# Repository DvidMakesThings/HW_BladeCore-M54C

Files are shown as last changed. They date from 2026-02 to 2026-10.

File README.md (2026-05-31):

# BladeCore‑M54C

BladeCore‑M54C is part of the **BladeCore** modular controller series.  
Each BladeCore variant is implemented as a standalone hardware repository, sharing a common architectural philosophy while targeting different microcontrollers and interfaces.

This repository documents the **BladeCore-M54C** hardware, which is based on the **RP2354B** microcontroller and integrates **CAN 2.0B connectivity**.

## BladeCore Series Overview

The BladeCore series consists of the following hardware variants:

| Module | Microcontroller | Primary Interface | Form Factor | Status |
|---|---|---|---|---|
| [BladeCore‑M40](#)  | RP2040  | — | - | Work in progress |
| [BladeCore‑M40E](#) | RP2040  | Ethernet | - | Work in progress |
| [BladeCore‑M40C](#) | RP2040  | CAN | - | Work in progress |
| [BladeCore‑M54](#)  | RP2354B | — | - | Work in progress |
| [BladeCore-M54E](https://github.com/DvidMakesThings/HW_BladeCore-M54E) | RP2354B | Ethernet | 2980 | Available |
| [BladeCore-M54C](https://github.com/DvidMakesThings/HW_BladeCore-M54C) | RP2354B | CAN | 2980 | Available |

### Naming Scheme Explanation

The BladeCore naming scheme encodes the **microcontroller family** and **primary communication interface** directly in the module name:

- **M40** designates an RP2040‑based module  
- **M54** designates an RP2354B‑based module  
- **E** suffix indicates integrated Ethernet support  
- **C** suffix indicates integrated CAN support  

Variants without a suffix represent the **base module** for that microcontroller family, without Ethernet or CAN integrated.

Each BladeCore variant is implemented as a **separate hardware design and repository**.

## Description

BladeCore-M54C is a compact controller module built around the **RP2354B** microcontroller, combined with a **MCP2515T-I/ML CAN controller** and the **TCAN1044AVDRBRQ1** CAN transceiver.  
The module is designed as a **2980-size M.2 M-Key card**, intended to be embedded into a carrier board or system that provides power through the M.2 edge connector.

The design integrates:

*   RP2354B microcontroller
*   External QSPI flash memory
*   External I²C EEPROM
*   Onboard CAN controller and transceiver with 120 Ohm termination
*   Dual‑path USB connectivity with automatic source selection
*   Onboard power regulation and defined power‑up sequencing

This repository contains the schematics and documentation.

- [BladeCore‑M54 schematics (PDF)](src/PDF/BladeCore-M54C_Schematics.pdf).
- [BladeCore‑M54 KiCad folder](src/HardwareDesign/1.0.0/).

### Resources

- **KiCad Libraries:** [src/HardwareDesign/Libraries/KiCad](src/HardwareDesign/Libraries/KiCad)
    - BladeCore‑M54C footprint 
    - BladeCore‑M54C symbol
    - Plain M.2 connector footprint (MDT420E03001)
    - 3D STEP: BladeCore‑M54C + MDT420E03001 assembly
    - 3D STEP: M.2 connector
- **Eagle Libraries:** [src/HardwareDesign/Libraries/Eagle](src/HardwareDesign/Libraries/Eagle)
    - Status: Work in progress

## Hardware Overview

<table>
    <tr>
        <td align="center">
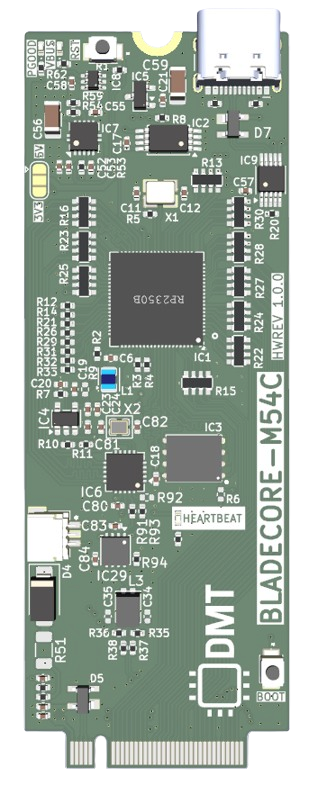
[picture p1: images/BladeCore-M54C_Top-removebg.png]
BladeCore‑M54C top view
            <br><em>Top view</em>
        </td>
        <td align="center">
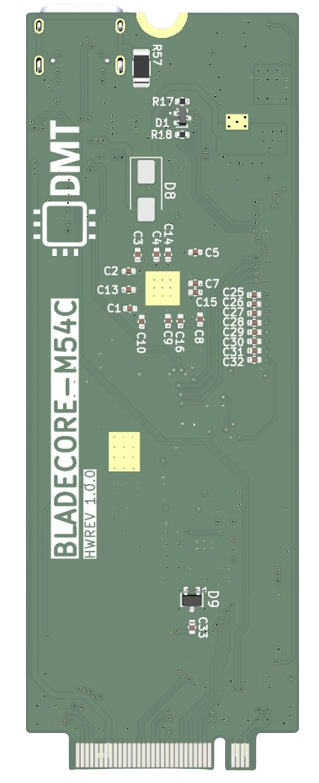
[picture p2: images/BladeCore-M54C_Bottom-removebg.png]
BladeCore‑M54C bottom view
            <br><em>Bottom view</em>
        </td>
    </tr>
 </table>

### Form Factor

*   **M.2 2980**
*   **M‑Key**
*   Power and I/O routed through the M.2 edge connector

### Microcontroller

*   **RP2354B**
*   External **12 MHz crystal**
*   Internal 1.1 V core supply generated by the MCU
*   SWD debug interface available
*   GPIOs routed to the M.2 edge connector

### Memory

*   **Integrated Flash**
    *   RP2354B
    *   Capacity: **2 MB**
*   **External QSPI Flash**
    *   W25Q128JVPIQ
    *   Capacity: **16 MB**
*   **External I²C EEPROM**
    *   AT24C256
    *   Capacity: **256 kbit**

***

### CAN

*   **MCP2515T-I/ML CAN controller**
*   **TCAN1044AVDRBRQ1** CAN transceiver
*   Interface to MCU via **SPI**
*   Onboard 120 Ohm termination
*   Dedicated reset and interrupt signals
*   ESD protection

### USB

BladeCore‑M54C supports **two physical USB connection paths**:

1.  **USB routed through the M.2 edge connector** (external host or carrier board USB), and
2.  **Onboard USB‑C connector**.

A **FSUSB42 USB 2.0 high‑speed multiplexer** is used to select which USB path is connected to the RP2354B.

**USB path selection behavior:**

*   By default, the USB data lines are routed to the **M.2 edge connector**.
*   When the **onboard USB‑C connector is plugged in**, the FSUSB42 automatically **redirects the USB data path** from the edge connector to the onboard USB‑C connector.
*   Removing the onboard USB connection restores the default routing to the M.2 edge connector.

This allows the module to be normally operated via a carrier board USB connection, while still enabling direct access through the onboard USB‑C connector when needed, without manual configuration.

***

### Power

*   Input supply: **VBUS / 5 V / 3.3 V** (5V and 3.3V is selectable by onboard solder jumper)
*   **TPS74801** low‑dropout regulator generating 3.3 V in case of 5V power is selected
*   Power‑good signaling with visal feedback (LED)
*   USB VBUS sensing routed to ADC
*   Optional USB‑powered operation depending on component population (as noted in schematics)

### M.2 Connector Pinout

#### Left Side (Odd Pins)

| Pin | Name | F0 | F1 | F2 | F3 | F4 | F5 | F6 | F7 | F8 | F9 |
|----:|---|----|----|----|----|----|----|----|----|----|----|
| 1 | GND | | | | | | | | | | |
| 3 | GPIO24 | SPI0 TX | UART1 RTS | I2C1 SCL | PWM3 B | SIO | PIO0 | PIO1 | PIO2 | | CLOCK GPOUT1 |
| 5 | GPIO23 | SPI0 TX | UART1 RTS | I2C1 SCL | PWM3 B | SIO | PIO0 | PIO1 | PIO2 | | CLOCK GPOUT1 |
| 7 | GPIO22 | SPI0 SCK | UART1 CTS | I2C1 SDA | PWM3 A | SIO | PIO0 | PIO1 | PIO2 | | CLOCK GPIN1 |
| 9 | GPIO21 | SPI0 CSn | UART1 RX | **I2C0 SCL | PWM2 B | SIO | PIO0 | PIO1 | PIO2 | | CLOCK GPOUT0 |
| 11 | GND | | | | | | | | | | |
| 13 | GPIO20 | SPI0 RX | UART1 TX | **I2C0 SDA | PWM2 A | SIO | PIO0 | PIO1 | PIO2 | | CLOCK GPIN0 |
| 15 | GPIO19 | SPI0 TX | UART0 RTS | I2C1 SCL | PWM1 B | SIO | PIO0 | PIO1 | PIO2 | | QMI CS1n |
| 17 | GPIO18 | SPI0 SCK | UART0 CTS | I2C1 SDA | PWM1 A | SIO | PIO0 | PIO1 | PIO2 | | |
| 19 | GPIO17 | SPI0 CSn | UART0 RX | **I2C0 SCL | PWM0 B | SIO | PIO0 | PIO1 | PIO2 | | |
| 21 | GPIO16 | SPI0 RX | UART0 TX | **I2C0 SDA | PWM0 A | SIO | PIO0 | PIO1 | PIO2 | | |
| 23 | GND | | | | | | | | | | |
| 25 | GPIO15 | *SPI1 TX | UART0 RTS | I2C1 SCL | PWM7 B | SIO | PIO0 | PIO1 | PIO2 | | CLOCK GPOUT1 |
| 27 | GPIO14 | *SPI1 SCK | UART0 CTS | I2C1 SDA | PWM7 A | SIO | PIO0 | PIO1 | PIO2 | | CLOCK GPIN1 |
| 29 | GPIO13 | *SPI1 CSn | UART0 RX | **I2C0 SCL | PWM6 B | SIO | PIO0 | PIO1 | PIO2 | | CLOCK GPOUT0 |
| 31 | GPIO12 | *SPI1 RX | UART0 TX | **I2C0 SDA | PWM6 A | SIO | PIO0 | PIO1 | PIO2 | | CLOCK GPIN0 |
| 33 | GPIO11 | *SPI1 TX | UART1 RTS | I2C1 SCL | PWM5 B | SIO | PIO0 | PIO1 | PIO2 | | |
| 35 | GPIO10 | *SPI1 SCK | UART1 CTS | I2C1 SDA | PWM5 A | SIO | PIO0 | PIO1 | PIO2 | | |
| 37 | GPIO9 | *SPI1 CSn | UART1 RX | **I2C0 SCL | PWM4 B | SIO | PIO0 | PIO1 | PIO2 | | |
| 39 | GPIO8 | *SPI1 RX | UART1 TX | **I2C0 SDA | PWM4 A | SIO | PIO0 | PIO1 | PIO2 | | QMI CS1n |
| 41 | GND | | | | | | | | | | |
| 43 | GPIO7 | SPI0 TX | UART1 RTS | I2C1 SCL | PWM3 B | SIO | PIO0 | PIO1 | PIO2 | | |
| 45 | GPIO6 | SPI0 SCK | UART1 CTS | I2C1 SDA | PWM3 A | SIO | PIO0 | PIO1 | PIO2 | | |
| 47 | GPIO5 | SPI0 CSn | UART1 RX | **I2C0 SCL | PWM2 B | SIO | PIO0 | PIO1 | PIO2 | | |
| 49 | GPIO4 | SPI0 RX | UART1 TX | **I2C0 SDA | PWM2 A | SIO | PIO0 | PIO1 | PIO2 | | |
| 51 | GPIO3 | SPI0 TX | UART0 RTS | I2C1 SCL | PWM1 B | SIO | PIO0 | PIO1 | PIO2 | | |
| 53 | GPIO2 | SPI0 SCK | UART0 CTS | I2C1 SDA | PWM1 A | SIO | PIO0 | PIO1 | PIO2 | | |
| 55 | GPIO1 | SPI0 CSn | UART0 RX | **I2C0 SCL | PWM0 B | SIO | PIO0 | PIO1 | PIO2 | | TRACECLK |
| 57 | GPIO0 | SPI0 RX | UART0 TX | **I2C0 SDA | PWM0 A | SIO | PIO0 | PIO1 | PIO2 | | QMI CS1n |
| 67 | GND | | | | | | | | | | |
| 69 | USB_D+ | | | | | | | | | | |
| 71 | USB_D- | | | | | | | | | | |
| 73 | GND | | | | | | | | | | |
| 75 | VBUS | | | | | | | | | | |

#### Right Side (Even Pins)

| Pin | Name | F0 | F1 | F2 | F3 | F4 | F5 | F6 | F7 | F8 | F9 |
|----:|---|----|----|----|----|----|----|----|----|----|----|
| 2 | GND | | | | | | | | | | |
| 4 | GPIO27 | *SPI1 TX | UART1 RTS | I2C1 SCL | PWM5 B | SIO | PIO0 | PIO1 | PIO2 | | |
| 6 | GPIO26 | *SPI1 SCK | UART1 CTS | I2C1 SDA | PWM5 A | SIO | PIO0 | PIO1 | PIO2 | | |
| 8 | GPIO25 | *SPI1 CSn | UART1 RX | **I2C0 SCL | PWM4 B | SIO | PIO0 | PIO1 | PIO2 | | CLOCK GPOUT3 |
| 10 | 3V3_OUT | | | | | | | | | | |
| 12 | 3V3_OUT | | | | | | | | | | |
| 14 | +5V_IN | | | | | | | | | | |
| 16 | +5V_IN | | | | | | | | | | |
| 18 | GND | | | | | | | | | | |
| 20 | GND | | | | | | | | | | |
| 22 | GND | | | | | | | | | | |
| 24 | GND | | | | | | | | | | |
| 26 | GND | | | | | | | | | | |
| 28 | CAN_P | | | | | | | | | | |
| 30 | CAN_N | | | | | | | | | | |
| 32 | GND | | | | | | | | | | |
| 34 | GPIO37 |  | SPI0 CSn | UART1 RX | **I2C0 SCL | PWM10 B | SIO | PIO0 | PIO1 | PIO2 |  |
| 36 | GPIO38 |  | SPI0 SCK | UART1 CTS | I2C1 SDA | PWM11 A | SIO | PIO0 | PIO1 | PIO2 |  |
| 38 | GND | | | | | | | | | | |
| 40 | GPIO39 |  | SPI0 TX | UART1 RTS | I2C1 SCL | PWM11 B | SIO | PIO0 | PIO1 | PIO2 |  |
| 42 | GND | | | | | | | | | | |
| 44 | GND | | | | | | | | | | |
| 46 | ADC0/GPIO40 |  | *SPI1 RX | UART1 TX | **I2C0 SDA | PWM8 A | SIO | PIO0 | PIO1 | PIO2 |  |
| 48 | ADC1/GPIO41 |  | *SPI1 CSn | UART1 RX | **I2C0 SCL | PWM8 B | SIO | PIO0 | PIO1 | PIO2 |  |
| 50 | ADC2/GPIO42 |  | *SPI1 SCK | UART1 CTS | I2C1 SDA | PWM9 A | SIO | PIO0 | PIO1 | PIO2 |  |
| 52 | ADC3/GPIO43 |  | *SPI1 TX | UART1 RTS | I2C1 SCL | PWM9 B | SIO | PIO0 | PIO1 | PIO2 |  |
| 54 | ADC4/GPIO44 |  | *SPI1 RX | UART0 TX | **I2C0 SDA | PWM10 A | SIO | PIO0 | PIO1 | PIO2 |  |
| 56 | ADC5/GPIO45 |  | *SPI1 CSn | UART0 RX | **I2C0 SCL | PWM10 B | SIO | PIO0 | PIO1 | PIO2 |  |
| 58 | GND | | | | | | | | | | |
| 68 | GND | | | | | | | | | | |
| 70 | GND | | | | | | | | | | |
| 72 | VBUS | | | | | | | | | | |
| 74 | VBUS | | | | | | | | | | |
| SH1 | SHIELD | | | | | | | | | | |

*SPI1 is used for the onboard CAN controller (MCP2515T)

**I2C0 is used for the onboard EEPROM (AT24C256)

## Revision History

| Revision | Date | Notes |
| --- | --- | --- |
| 1.0.0 | 2026‑01‑31 | Initial creation |

## Notes

*   This documentation intentionally avoids assumptions about firmware features, supported protocols, or software behavior.
*   All statements are derived from the provided schematics and explicit design notes.
*   Component‑level limits and behavior should be verified against the respective datasheets.

## License
### Hardware Components
Hardware designs, schematics, and related documentation are licensed under the **Creative Commons Attribution-NonCommercial-ShareAlike 4.0 International License (CC BY-NC-SA 4.0)**. See the [Hardware License](LICENSE-CC-BY-NC-SA) file for details.

#### What CC BY-NC-SA 4.0 means:

- ✅ **You can** study, modify, and distribute the hardware designs
- ✅ **You can** create derivative works for personal, educational, or non-commercial use
- ✅ **You can** build this project for your own personal use

- ⚠️ **You must** give appropriate credit and indicate if changes were made
- ⚠️ **You must** share any modifications under the same license terms
- ⚠️ **You must** include the original license and copyright notices

- ❌ **You cannot** use the designs for commercial purposes without explicit permission
- ❌ **You cannot** manufacture and sell products based on these designs without a commercial license
- ❌ **You cannot** create closed-source derivatives for commercial purposes
- ❌ **You cannot** use the designer's trademarks without permission

### Commercial & Enterprise Use

Commercial use of this project is prohibited without obtaining a separate commercial license. If you are interested in:

- Manufacturing and selling products based on these designs
- Incorporating these designs into commercial products
- Any other commercial applications

Please contact me through any of the channels listed in the [Contact](#contact) section to discuss commercial licensing arrangements. Commercial licenses are available with reasonable terms to support ongoing development.

## Contact

For questions or feedback:
- **Email:** [info@dmt-hw.com](mailto:info@dmt-hw.com)
- **GitHub:** [DvidMakesThings](https://github.com/DvidMakesThings)

## Contributing

Contributions are welcome! As this is an early-stage project, please reach out before 
making substantial changes:

1. Fork the repository
2. Create a feature branch (`git checkout -b feature/concept`)
3. Commit your changes (`git commit -m 'Add concept'`)
4. Push to the branch (`git push origin feature/concept`)
5. Open a Pull Request with a detailed description

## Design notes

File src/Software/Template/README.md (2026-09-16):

# Create_M54C_RTOS.ps1

One PowerShell script that generates a ready-to-build FreeRTOS project for the BladeCore-M54C module (RP2354B) and, when asked, keeps the project's `CMakeLists.txt` in sync with your own source files.

Location: `src/Software/Template/Create_M54C_RTOS.ps1`

## What it does

- Writes a complete project (`main.c`, `CONFIG.h`, `FreeRTOSConfig.h`, `CMakeLists.txt`, `pico_sdk_import.cmake`, `build.py`, `.gitignore`, `.vscode/`) into a folder you choose.
- Creates an `incl/` folder for your own source and header files.
- Downloads and installs whatever is missing on your PC: Git, Python 3, CMake, Ninja, ARM GNU toolchain, Raspberry Pi Pico SDK, picotool, OpenOCD, FreeRTOS-Kernel.
- Sets `PICO_SDK_PATH` and `PICO_TOOLCHAIN_PATH` at user scope.
- Has an update mode that scans `incl/` and rewrites two marked regions of `CMakeLists.txt` so every `.c` becomes a source and every subfolder with a `.h` becomes an include directory.

## Requirements

- Windows 10 or 11
- Windows PowerShell 5.1 or newer
- winget available (only used to install Git and Python if they are missing)
- Internet access on the first run

You do NOT need admin rights. Everything installs under `%USERPROFILE%\.pico-sdk\`.

## Quick start

Open PowerShell in the repo root and run:

```powershell
.\src\Software\Template\Create_M54C_RTOS.ps1 -TargetPath C:\Dev\MyProject -ProjectName MyProject
```

That single command will:
1. Check every required tool. Install anything missing.
2. Clone the Pico SDK and FreeRTOS-Kernel.
3. Write all project files at `C:\Dev\MyProject`.
4. Print a "Next steps" block with the exact build command.

## Build and flash

From inside the generated project folder:

```powershell
python3 build.py            # configure if needed, then build
python3 build.py rebuild    # wipe build/, then build from scratch
python3 build.py clean      # delete build/
python3 build.py size       # print memory usage of last build
python3 build.py upload     # build, then flash via picotool (hold BOOTSEL)
```

Build outputs land in `build/`:

```
MyProject.elf, MyProject.hex, MyProject.uf2, MyProject.bin, MyProject.dis, MyProject.elf.map
```

The `.uf2` is what you drag onto the RPI-RP2 mass storage volume, or `python3 build.py upload` handles it automatically.

## Adding your own source files

1. Drop `.c` and `.h` files under `incl/`. Group them in subfolders however you like, a folder can hold as many files as you want:
    ```
    incl/
       task/
          task1.c
          task1.h
          task2.c
          task2.h
       utils/
          utils.c
          utils.h
    ```
2. Run:
    ```powershell
    .\src\Software\Template\Create_M54C_RTOS.ps1 -TargetPath C:\Dev\MyProject -Update
    ```
3. `CMakeLists.txt` now has your sources between `# === USER SOURCES BEGIN ===` and `# === USER SOURCES END ===`, and your header folders between `# === USER INCLUDE DIRS BEGIN ===` and `# === USER INCLUDE DIRS END ===`. Nothing else is touched.
4. Rebuild:
    ```powershell
    python3 build.py rebuild
    ```

You can `#include "task/task1.h"` from `main.c` right away because `incl/` is on the include path by default.

Rules for `-Update`:
- Every `.c` under `incl/` becomes a source.
- Every subfolder that contains at least one `.h` becomes an include directory.
- Only `.c` and `.h` extensions are picked up. `.cpp`, `.cc`, `.S`, `.hpp` are ignored; add them to `CMakeLists.txt` outside the marker regions.
- File and folder names must not contain spaces or `#` / `+` / `"`. CMake will misparse them.
- Do not put symlinks or junctions under `incl/`. The scan follows them and can loop.
- Anything you put inside the marker regions is overwritten on the next `-Update`. Custom tweaks belong outside the markers.

## Command reference

```powershell
.\Create_M54C_RTOS.ps1 -TargetPath <path> [-ProjectName <name>] [-SkipToolInstall] [-Force]
.\Create_M54C_RTOS.ps1 -TargetPath <path> -Update
```

| Parameter | Mode | Meaning |
|---|---|---|
| `-TargetPath` | both | Path of the project folder. |
| `-ProjectName` | create | C identifier used as the CMake target name. Defaults to the folder name.|
| `-Update` | update | Rescan `incl/` and rewrite the two marker regions of `CMakeLists.txt`.  |
| `-SkipToolInstall` | create | Skip all tool detection and installation. |
| `-Force` | create | Overwrite existing files in `TargetPath`. |

Examples:

```powershell
# Create a new project, install any missing tools
.\Create_M54C_RTOS.ps1 -TargetPath C:\Dev\MyProject -ProjectName MyProject

# Regenerate files into a folder that already has stuff in it
.\Create_M54C_RTOS.ps1 -TargetPath C:\Dev\MyProject -Force

# Only generate files, don't touch anything else on the PC
.\Create_M54C_RTOS.ps1 -TargetPath C:\Dev\MyProject -SkipToolInstall

# After you've added or removed files under incl\
.\Create_M54C_RTOS.ps1 -TargetPath C:\Dev\MyProject -Update
```

## What gets installed and where

Everything lands under `%USERPROFILE%\.pico-sdk\` (no admin needed):

| Tool | Version | Location |
|---|---|---|
| Pico SDK | 2.2.0 | `%USERPROFILE%\.pico-sdk\sdk\2.2.0\` |
| ARM GNU toolchain | 14.2.rel1 | `%USERPROFILE%\.pico-sdk\toolchain\14_2_Rel1\` |
| CMake | 3.31.5 | `%USERPROFILE%\.pico-sdk\cmake\v3.31.5\` |
| Ninja | 1.12.1 | `%USERPROFILE%\.pico-sdk\ninja\v1.12.1\` |
| picotool | 2.2.0-a4 | `%USERPROFILE%\.pico-sdk\picotool\2.2.0-a4\` |
| OpenOCD | 0.12.0+dev | `%USERPROFILE%\.pico-sdk\openocd\0.12.0+dev\` |
| FreeRTOS-Kernel | main branch  | `<project>\FreeRTOS-Kernel\` (git clone per project) |

Winget is used to install Git and Python 3 if they are missing on your PATH.

Two user environment variables are set:
- `PICO_SDK_PATH`
- `PICO_TOOLCHAIN_PATH`

## Generated project layout

```
MyProject/
   .vscode/                (IDE tasks, launch, IntelliSense, CMake kits)
   FreeRTOS-Kernel/        (git clone, ignored by git)
   incl/                   (your source and header files go here)
   build/                  (created by build.py, ignored by git)
   .gitignore
   build.py                (build and flash helper)
   CMakeLists.txt          (has USER SOURCES and USER INCLUDE DIRS regions)
   CONFIG.h                (BladeCore-M54C pin map)
   FreeRTOSConfig.h
   main.c
   pico_sdk_import.cmake
```

## VS Code

Open the generated folder:

```powershell
code C:\Dev\MyProject
```

The recommended extensions (Cortex-Debug, C/C++, Raspberry Pi Pico, Serial Monitor) are listed in `.vscode/extensions.json`.

- `Ctrl+Shift+B` runs the "Compile Project" task.
- The "Flash" and "Rescue Reset" tasks use OpenOCD over CMSIS-DAP.
- Two Cortex-Debug launch configs are provided: embedded OpenOCD and external OpenOCD on `localhost:3333`.

## Troubleshooting

**"Target path is not empty. Use -Force to overwrite."**
Either point `-TargetPath` at an empty or non-existent folder, or pass `-Force`.

**"USER SOURCES markers not found in CMakeLists.txt"**
The `-Update` mode requires the two marker regions. If you deleted them, restore them by running create mode with `-Force` (this overwrites CMakeLists.txt), then re-add your customizations outside the markers.

**Build cannot find CMake / Ninja / picotool**
Open a fresh terminal so the updated `PICO_SDK_PATH`, `PICO_TOOLCHAIN_PATH`, and `PATH` are picked up. `build.py` also searches `%USERPROFILE%\.pico-sdk\...` as a fallback, so it works even if PATH is misconfigured.

**Board does not enter BOOTSEL**
Hold the BOOTSEL button while plugging USB, then run `python3 build.py upload`.

**Python 2 is on PATH as `python`**
The script auto-prefers `python3` and only accepts a `Python 3.x` version. If your PC only has Python 2, it will install Python 3.12 via winget.

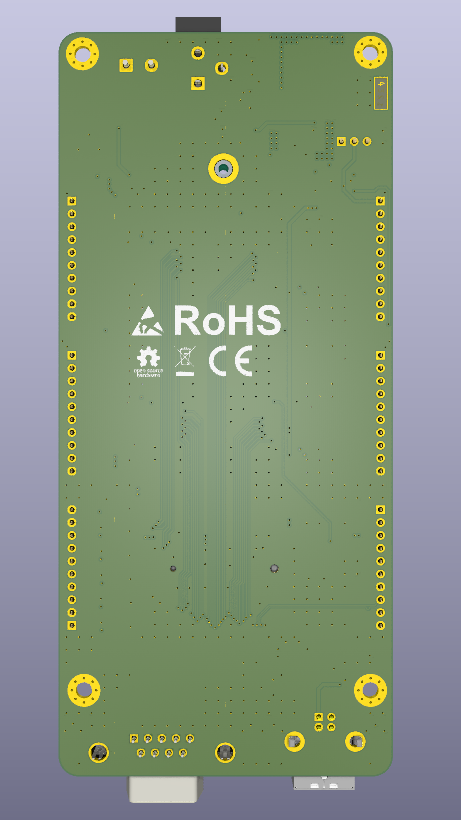
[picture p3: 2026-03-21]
src/HardwareDesign/M54-DevBoard_1.0.0/Images/M54-DevBoard_1.0.0_Bottom.png

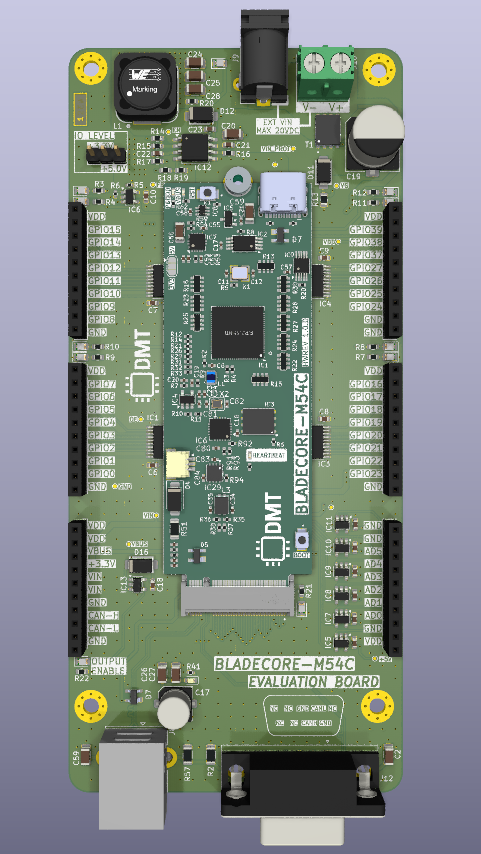
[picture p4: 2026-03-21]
src/HardwareDesign/M54-DevBoard_1.0.0/Images/M54-DevBoard_1.0.0_Top.png

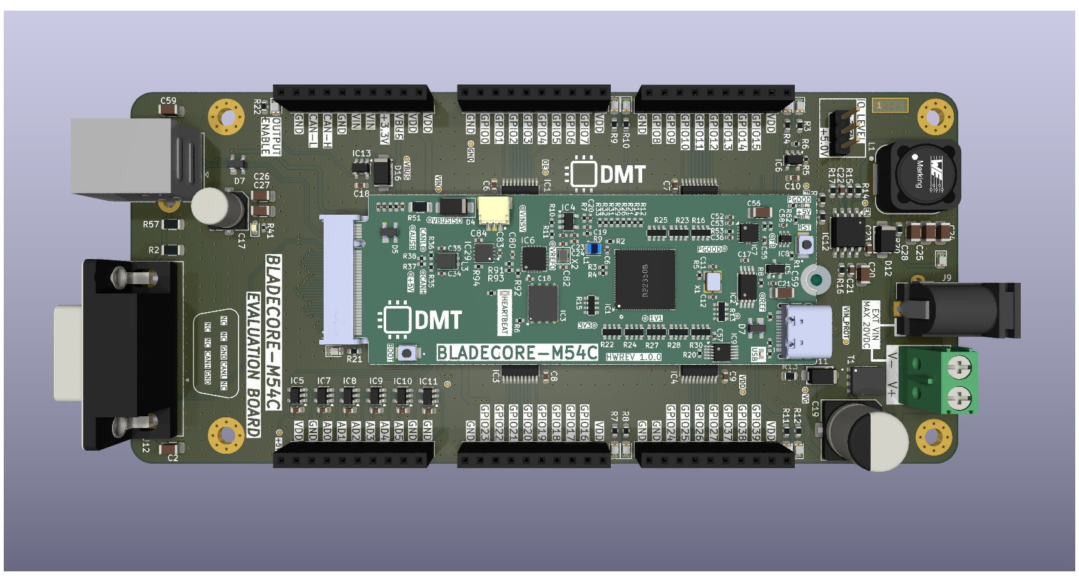
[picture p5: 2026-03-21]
src/HardwareDesign/M54-DevBoard_1.0.0/Images/3D/M54-DevBoard_1.0.0-3.png

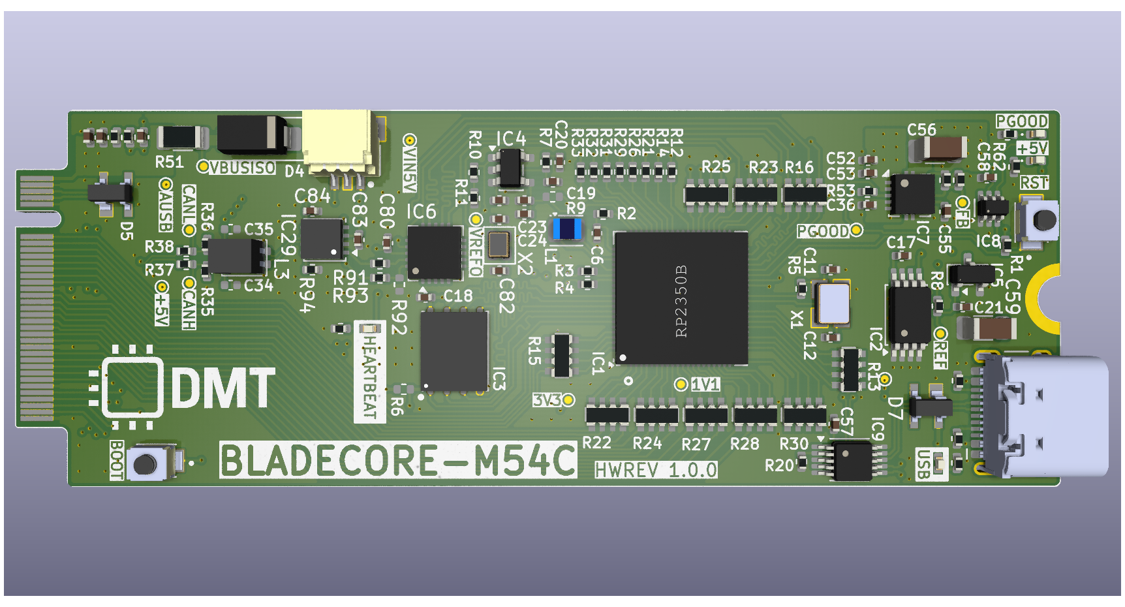
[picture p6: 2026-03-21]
src/HardwareDesign/1.0.0/Images/BladeCore-M54C_Top.png

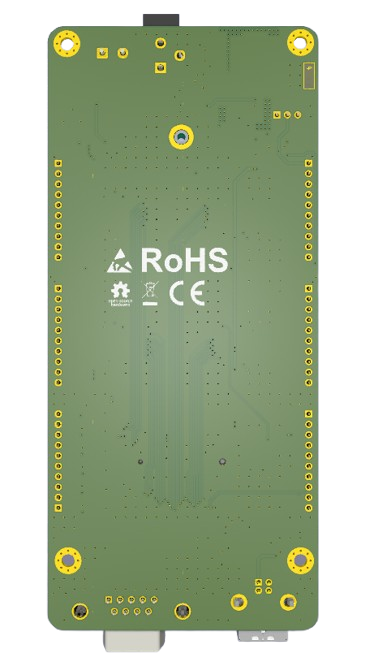
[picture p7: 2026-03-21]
src/HardwareDesign/M54-DevBoard_1.0.0/Images/M54-DevBoard_1.0.0_Bottom-removebg-preview.png

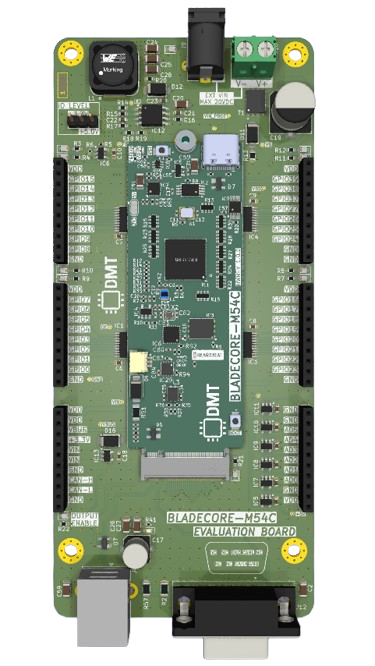
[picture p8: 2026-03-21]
src/HardwareDesign/M54-DevBoard_1.0.0/Images/M54-DevBoard_1.0.0_Top-removebg-preview.png

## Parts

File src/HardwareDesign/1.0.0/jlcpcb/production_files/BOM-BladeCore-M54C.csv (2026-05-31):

Comment | Designator | Footprint | LCSC | Quantity
0R 1% | R51 | R_1206_3216Metric | C205296 | 1
100R 1% | R13,R15,R16,R22,R23,R24,R25,R27,R28,R30 | R_Array_Convex_4x0603 | C136838 | 10
100R 1% | R12,R14,R21,R26,R29,R31,R32,R33 | R_0402_1005Metric | C25076 | 8
100nF 50V | C1,C10,C13,C14,C15,C17,C18,C19,C2,C21,C23,C3,C4,C5,C51,C52,C57,C58,C7,C8,C80,C83,C84,C9 | C_0402_1005Metric | C307331 | 24
100uH CMC | L3 | ACT1210D-101-2P-TL00 | C3039743 | 1
10K 1% | R10,R11,R53,R94 | R_0402_1005Metric | C25744 | 4
10pF 50V | C11,C12,C81,C82 | C_0402_1005Metric | C466222 | 4
10uF 50V | C56 | C_1206_3216Metric | C13585 | 1
12MHz 10pF | X1 | X3225 | C2901649 | 1
16MHz 8pF | X2 | Crystal_SMD_2016-4Pin_2.0x1.6mm | C2965577 | 1
1K 1% | R34,R41,R5,R60,R62,R91 | R_0402_1005Metric | C11702 | 6
1M 1% | R57 | R_1206_3216Metric | C17927 | 1
1R 1% | R37,R38 | R_0402_1005Metric | C185446 | 2
1nF 2kV | C59 | C_1206_3216Metric | C173242 | 1
1nF 50V | C25,C26,C27,C28,C29,C30,C31,C32 | C_0402_1005Metric | C14442 | 8
1uF 50V | C53 | C_0402_1005Metric | C1518208 | 1
2.2K 1% | R17,R18 | R_0402_1005Metric | C25879 | 2
2.2nF 50V | C55 | C_0402_1005Metric | C106861 | 1
2.4K 1% | R59 | R_0402_1005Metric | C25882 | 1
27R 1% | R7 | R_0402_1005Metric | C138021 | 1
3.3uH 2.8A | L1 | 0805 | C42411119 | 1
33R 1% | R2,R3,R4 | R_0402_1005Metric | C25105 | 3
4.7K 1% | R1,R8 | R_0402_1005Metric | C25900 | 2
4.7nF 50V | C33 | C_0402_1005Metric | C1538 | 1
4.7uF 10V | C20,C22,C24 | C_0402_1005Metric | C368809 | 3
4.7uF 25V | C16,C36,C49,C50,C6 | C_0402_1005Metric | C22367824 | 5
5.1K 1% | R19,R20,R52,R55,R56 | R_0402_1005Metric | C25905 | 5
510R 1% | R93 | R_0402_1005Metric | C25123 | 1
60.4R 1% | R35,R36 | R_0402_1005Metric | C137954 | 2
7.5K 1% | R54 | R_0402_1005Metric | C25918 | 1
AT24C256C-XHL-T | IC2 | TSSOP-8 | C33035 | 1
B3U-1000P | SW1,SW2 | SW_B3U-1000P | C231329 | 2
Blue | D3 | LED_0402_1005Metric | C22355736 | 1
FSUSB42MUX | IC9 | MSOP-10_3x3mm_P0.5mm | C11355 | 1
Green | D10,D2,D6 | LED_0402_1005Metric | C965793 | 3
LM4040B30FTA | IC5 | SOT-23 | C460604 | 1
MCP2515T-I/ML | IC6 | QFN-20-1EP_4x4mm_P0.5mm_EP2.7x2.7mm | C96140 | 1
MCP6001RT | IC4 | SOT-23-5 | C154973 | 1
PESD2CANFD24V-UX | D9 | SOT-323_SC-70 | C46970732 | 1
RCLAMP0582BQTCT | D1 | SOT-416 | C841193 | 1
RP2354B | IC1 | QFN80_10x10 | C39843328 | 1
SM03B-SRSS-TB | J2 | JST_SM03B-SRSS-TB_LF__SN_ | C160403 | 1
SN74LVC1G97QDCKRQ1 | IC8 | SOT-363_SC-70-6 | C179911 | 1
SP0503BAHTG | D5,D7 | SOT143 | C3040626 | 2
TCAN1044AVDRBRQ1 | IC29 | HVSON-8-1EP_3x3mm_P0.65mm_EP1.6x2.4mm | C3234119 | 1
TPS74801DRCT | IC7 | VSON-10-1EP_3x3mm_P0.5mm_EP1.65x2.4mm_ThermalVias | C882845 | 1
USB-TYPE-C-018 | J3 | USB_C_Receptacle_HCTL_HC-TYPE-C-16P-01A | C2927038 | 1
W25Q128JVPIQ | IC3 | WSON8_6x5 | C190862 | 1
SS13 | D4 | D_SMA |  | 1
~ | TP6 | TestPoint_0.6mm |  | 1
~ | TP1 | TestPoint_0.6mm |  | 1
~ | TP8 | TestPoint_0.6mm |  | 1
~ | TP10 | TestPoint_0.6mm |  | 1
~ | TP7 | TestPoint_0.6mm |  | 1
~ | TP2 | TestPoint_0.6mm |  | 1
~ | TP3 | TestPoint_0.6mm |  | 1
~ | TP4 | TestPoint_0.6mm |  | 1
~ | TP15 | TestPoint_0.6mm |  | 1
~ | TP16 | TestPoint_0.6mm |  | 1
~ | TP17 | TestPoint_0.6mm |  | 1
~ | TP11 | TestPoint_0.6mm |  | 1
~ | TP5 | TestPoint_0.6mm |  | 1
~ | TP12 | TestPoint_0.6mm |  | 1
~ | TP13 | TestPoint_0.6mm |  | 1
SS13 | D11 | D_SMA |  | 1
~ | TP14 | TestPoint_0.6mm |  | 1
SS13 | D8 | D_SMA |  | 1

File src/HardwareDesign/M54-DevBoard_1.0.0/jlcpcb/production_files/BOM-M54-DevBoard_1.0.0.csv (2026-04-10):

Comment | Designator | Footprint | LCSC | Quantity
100K 1% | R14,R16,R17 | R_0603_1608Metric | C25803 | 3
100nF 50V | C1,C10,C11,C12,C13,C14,C15,C16,C18,C21,C23,C29,C3,C4,C5,C6,C7,C8,C9 | C_0603_1608Metric | C14663 | 19
100uF 50V | C17 | C_Elec_6.3x7.7 | C3151829 | 1
10K 1% | R1,R13 | R_0805_2012Metric | C17414 | 2
10K 1% | R24,R25,R26,R27,R6 | R_0603_1608Metric | C25804 | 5
10uF 50V | C20,C24,C25,C26,C27,C28 | C_1206_3216Metric | C13585 | 6
150pF 50V | C22 | C_0603_1608Metric | C1594 | 1
15K 1% | R5 | R_0603_1608Metric | C22809 | 1
15uH 4.2A | L1 | L_12x12x6_WE-PD-1260 | C2049359 | 1
1K 1% | R41 | R_0402_1005Metric | C11702 | 1
1K 1% | R10,R11,R12,R20,R21,R22,R3,R4,R7,R8,R9 | R_0603_1608Metric | C21190 | 11
1M 1% | R2,R57 | R_1206_3216Metric | C17927 | 2
1nF 2kV | C2,C59 | C_1206_3216Metric | C173242 | 2
210K 1% | R19 | R_0603_1608Metric | C22952 | 1
24.9K 1% | R15 | R_0603_1608Metric | C2930080 | 1
330uF 50V | C19 | CP_Elec_10x10.5 | C178596 | 1
40.2K 1% | R18 | R_0603_1608Metric | C12447 | 1
Blue | D1 | LED_0603_1608Metric | C965817 | 1
CMSH3-40MA | D12 | SMA | C48937470 | 1
Green | D14,D15 | LED_0805_2012Metric | C965815 | 2
M2.5 | ST1 | Round Standoff Threaded M2.5 Steel | C7435234 | 1
MP4462DN-LF-Z | IC12 | SO-8_3.9x4.9mm_EP2.6x3.5mm | C28398 | 1
OPA365AQDBVRQ1 | IC10,IC11,IC13,IC5,IC7,IC8,IC9 | SOT-23-5 | C485978 | 7
Orange | D10,D2,D5,D8 | LED_0805_2012Metric | C965813 | 4
PJ-102AH | J9 | BarrelJack_CUI_PJ-102AH_Horizontal | C3096093 | 1
Red | D13,D3,D4,D6,D9 | LED_0805_2012Metric | C7371913 | 5
SMAZ15-13-F | D11 | SMA | C110524 | 1
SP0503BAHTG | D7 | SOT143 | C3040626 | 1
SQJ459EP-T1_GE3 | T1 | PowerPAK SO-8 | C3289501 | 1
TXS0108EPWR | IC1,IC2,IC3,IC4 | TSSOP-20_4.4x6.5_P0.65mm | C17206 | 4
USB-B-S-F-B-TH | J8 | USB_B_Lumberg_2411_02_Horizontal | C5714571 | 1
LM397 | IC21 | SOT-23-5 |  | 1
LM397 | IC20 | SOT-23-5 |  | 1
PINHD_1x10_Female | J3 | PinSocket_1x10_P2.54mm_Vertical |  | 1
PINHD_1x10_Female | J4 | PinSocket_1x10_P2.54mm_Vertical |  | 1
PINHD_1x10_Female | J5 | PinSocket_1x10_P2.54mm_Vertical |  | 1
PINHD_1x10_Female | J7 | PinSocket_1x10_P2.54mm_Vertical |  | 1
BSS138LT1G | T2 | SOT-23 |  | 1
BSS138LT1G | T3 | SOT-23 |  | 1
BSS138LT1G | T4 | SOT-23 |  | 1
BSS138LT1G | T5 | SOT-23 |  | 1
BSS138LT1G | T6 | SOT-23 |  | 1
BSS138LT1G | T7 | SOT-23 |  | 1
BSS138LT1G | T8 | SOT-23 |  | 1
~ | TP1 | TestPoint_0.6mm |  | 1
~ | TP2 | TestPoint_0.6mm |  | 1
~ | TP3 | TestPoint_0.6mm |  | 1
~ | TP4 | TestPoint_0.6mm |  | 1
~ | TP5 | TestPoint_0.6mm |  | 1
~ | TP7 | TestPoint_0.6mm |  | 1
~ | TP8 | TestPoint_0.6mm |  | 1
~ | TP9 | TestPoint_0.6mm |  | 1
~ | TP10 | TestPoint_0.6mm |  | 1
~ | TP11 | TestPoint_0.6mm |  | 1
~ | TP12 | TestPoint_0.6mm |  | 1
PINHD_1x10_Female | J6 | PinSocket_1x10_P2.54mm_Vertical |  | 1
~ | TP6 | TestPoint_0.6mm |  | 1
BSS138LT1G | T9 | SOT-23 |  | 1
DE9_Socket_MountingHoles | J12 | DSUB-9_Socket_Horizontal_P2.77x2.84mm_EdgePinOffset7.70mm_Housed_MountingHolesOffset9.12mm |  | 1
PINHD_1x3_Male | J11 | PinHeader_1x03_P2.54mm_Vertical |  | 1
1888687 | J10 | TerminalBlock_Phoenix_PT-1,5-2-5.0-H_1x02_P5.00mm_Horizontal |  | 1
PINHD_1x10_Female | J2 | PinSocket_1x10_P2.54mm_Vertical |  | 1
~ | D16 | SMA |  | 1

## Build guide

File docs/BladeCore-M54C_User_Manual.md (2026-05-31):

---
title: BladeCore-M54C User Manual
---

**Hardware Revision:** 1.0.0
**Date:** 2026-01-31
**Author:** DMT

## Table of Contents

1. [Introduction](#1-introduction)
2. [General Specifications](#2-general-specifications)
3. [Electrical Characteristics](#3-electrical-characteristics)
4. [Microcontroller](#4-microcontroller)
5. [Memory Subsystem](#5-memory-subsystem)
6. [CAN Interface](#6-can-interface)
7. [USB Interface](#7-usb-interface)
8. [Power Management](#8-power-management)
9. [M.2 Connector Pinout](#9-m2-connector-pinout)
10. [Onboard Peripherals](#10-onboard-peripherals)
11. [Power-Up Sequencing](#11-power-up-sequencing)
12. [Getting Started -- Software](#12-getting-started----software)
13. [Programming Guide](#13-programming-guide)
14. [Code Examples](#14-code-examples)
15. [Design Considerations for Carrier Boards](#15-design-considerations-for-carrier-boards)
16. [Mechanical Specifications](#16-mechanical-specifications)
17. [Absolute Maximum Ratings](#17-absolute-maximum-ratings)
18. [Revision History](#18-revision-history)

## 1. Introduction

BladeCore-M54C is a compact, modular microcontroller card built around the **RP2354B**
(ARM Cortex-M33, dual-core) combined with an **MCP2515 CAN controller** and
**TCAN1044AVDRBRQ1 CAN transceiver**.  The module uses an **M.2 2980 M-Key** form
factor (29 mm wide, 80 mm long) with a standard M-Key edge connector at a
non-standard board width, making it suitable for embedding into carrier boards or
systems that provide power and I/O connectivity through the M.2 edge connector.

### Key Features

- RP2354B dual-core ARM Cortex-M33 microcontroller
- 2 MB integrated flash + 16 MB external QSPI flash
- 256 kbit external I2C EEPROM with 200+ year data retention
- CAN 2.0B via MCP2515 (SPI-attached) + TCAN1044A transceiver
- Dual-path USB 2.0 with automatic source selection (M.2 + USB-C)
- 31 GPIO pins + 6 ADC channels routed to M.2 edge connector
- Onboard 3.3 V LDO with power-good signaling
- Defined power-up sequencing
- Onboard heartbeat LED (PWM-capable)
- SWD debug interface

### BladeCore Series

BladeCore-M54C belongs to the BladeCore modular controller series:

| Module | MCU | Primary Interface | 
|---|---|---|
| BladeCore-M40  | RP2040  | -- |
| BladeCore-M40E | RP2040  | Ethernet | 
| BladeCore-M40C | RP2040  | CAN |
| BladeCore-M54  | RP2354B | -- | 
| BladeCore-M54E | RP2354B | Ethernet | 
| BladeCore-M54C | RP2354B | CAN |

**Naming convention:** M40 = RP2040-based, M54 = RP2354B-based. Suffix E = Ethernet,
C = CAN, no suffix = base module.

## 2. General Specifications

| Parameter | Value |
|---|---|
| Microcontroller | RP2354B (ARM Cortex-M33, dual core) |
| Package | QFN-80-EP (10 x 10 mm) |
| System Clock | 150 MHz, overclock possible (Tested max is 200MHz) |
| External Crystal | 12 MHz, 10 pF load |
| Integrated Flash | 2 MB (internal to MCU) |
| External Flash (QSPI) | 16 MB (W25Q128JVPIQ, 133 MHz) |
| External EEPROM (I2C) | 256 kbit (AT24C256C, 400 kHz) |
| CAN | CAN 2.0B, MCP2515 (SPI) + TCAN1044A transceiver |
| USB | USB 2.0, dual path (M.2 + USB-C) |
| GPIO (M.2 connector) | 31 digital I/O pins |
| ADC Channels (M.2) | 6 channels (12-bit, GPIO40--GPIO45) |
| Onboard ADC Channels | 2 (VBUS sense, 3.0 V reference) |
| Operating Voltage (I/O) | 3.3 V |
| Form Factor | M.2 2980 M-Key |
| PCB Layers | 6 |

## 3. Electrical Characteristics

### 3.1 Recommended Operating Conditions

| Parameter | Symbol | Min | Typical | Max | Unit |
|---|---|---|---|---|---|
| Supply Voltage (5 V in)  | VIN | 4.75  | 5.0 | 5.5 | V |
| Supply Voltage (3.3 V) | VCC | 3.0 | 3.3 | 3.6 | V |
| USB VBUS Voltage | VBUS | 4.75  | 5.0 | 5.25  | V |
| Operating Temperature | TA | -20 | 25 | 70 | degC |
| I/O Logic Level (High) | VIH | 2.0 | -- | 3.3 | V |
| I/O Logic Level (Low) | VIL | 0 | -- | 0.8 | V |

### 3.2 RP2354B Core Parameters

| Parameter | Value |
|---|---|
| Core Voltage | 1.1 V (internal) |
| GPIO Output Drive | 2 / 4 / 8 / 12 mA |
| GPIO Input Hysteresis | Schmitt trigger |
| Internal Pull-Up/Down Resistance | 50--80 kOhm |
| ADC Resolution | 12 bits |
| ADC Reference Voltage | 3.3 V (AVDD) |

### 3.3 Power Consumption (Typical)

| Condition | Current (3.3 V)  | Notes |
|---|---|---|
| MCU idle, CAN off | ~15 mA | RP2354B in normal idle |
| MCU active, CAN off | ~40 mA | Both cores running |
| MCU active, CAN active | ~55 mA | MCP2515 + TCAN1044A active |
| MCU dormant (sleep) | <1 mA | Deep sleep, all peripherals off |

> **Note:** The above values are approximate. Actual consumption depends on clock
> frequency, active peripherals, GPIO loading, and CAN bus traffic. Consult the
> RP2354B, MCP2515, and TCAN1044A datasheets for detailed characterization.

### 3.4 LDO Regulator (TPS74801)

| Parameter | Symbol | Min  | Typical | Max  | Unit |
|---|---|---|---|---|---|
| Input Voltage | VIN | 1.1  | 5.0 | 5.5  | V |
| Output Voltage | VOUT | -- | 3.3 | -- | V |
| Max Output Current | IOUT | -- | -- | 1.5  | A |
| Dropout Voltage | VDO | -- | 110 | 300  | mV |
| Output Voltage Accuracy| -- | -- | +/-1 | -- | % |
| Thermal Shutdown | -- | -- | 160 | -- | degC |

### 3.5 Voltage Reference (LM4040B30FTA)

| Parameter | Value |
|---|---|
| Reference Voltage | 3.000 V |
| Tolerance | +/-0.1% |
| Package | SOT-23 |
| Connected To | ADC7 (GPIO47) via 10K-10K divider |

## 4. Microcontroller

### 4.1 RP2354B Overview

The RP2354B is a dual-core ARM Cortex-M33 microcontroller from Raspberry Pi Ltd.
It features hardware floating-point, DSP extensions, and the RP2-series PIO
(Programmable I/O) state machines.

| Feature | Specification |
|---|---|
| Architecture | ARM Cortex-M33 (ARMv8-M) |
| Cores | 2 |
| Max Clock Speed | 150 MHz |
| FPU | Single-precision hardware FPU |
| DSP | Yes (ARMv8-M DSP extension) |
| PIO State Machines | 3 PIO blocks (PIO0, PIO1, PIO2)  |
| DMA Channels | 16 |
| Timers | 2 hardware timers |
| PWM Channels | 24 (12 slices x 2 channels) |
| UART | 2 |
| SPI | 2 |
| I2C | 2 |
| USB | 1 (USB 1.1 Host/Device) |
| ADC | 12-bit SAR, 8 channels (+ temp)  |
| Internal Flash | 2 MB |
| SRAM | 520 KB |
| Debug | SWD (Serial Wire Debug) |
| Package | QFN-80-EP (10 x 10 mm) |

### 4.2 Clock Configuration

- **External Crystal:** 12 MHz (X3225 footprint), 10 pF load capacitance
- **System PLL:** Configurable up to 150 MHz system clock
- **USB PLL:** 48 MHz (required for USB operation)

### 4.3 GPIO Allocation on BladeCore-M54C

| GPIO Range  | Count | Assignment |
|---|---|---|
| GPIO0--27 | 28 | Routed to M.2 edge connector (user I/O) |
| GPIO28--31  | 4 | MCP2515 CAN SPI1 (MISO, CS, SCK, MOSI) |
| GPIO32--33  | 2 | I2C0 -- EEPROM (SDA, SCL) |
| GPIO34 | 1 | MCP2515 hardware reset |
| GPIO35 | 1 | MCP2515 interrupt (active low) |
| GPIO36 | 1 | Onboard heartbeat LED (blue, PWM) |
| GPIO37--39  | 3 | Routed to M.2 edge connector (user I/O) |
| GPIO40--45  | 6 | Routed to M.2 as ADC0--ADC5 |
| GPIO46 | 1 | Onboard ADC6 -- USB VBUS sense |
| GPIO47 | 1 | Onboard ADC7 -- 3.0 V reference monitor |

**Total GPIO available on M.2 connector: 37** (31 digital + 6 ADC-capable)

> **Warning:** GPIO28--31 are dedicated to the MCP2515 CAN controller and are
> NOT available for user applications. GPIO34 and GPIO35 are used for MCP2515
> reset and interrupt respectively.

## 5. Memory Subsystem

### 5.1 Integrated Flash

- Built into the RP2354B
- Capacity: 2 MB
- Used for program storage and execution (XIP -- execute in place)

### 5.2 External QSPI Flash (W25Q128JVPIQ)

| Parameter | Value |
|---|---|
| Part Number | W25Q128JVPIQ (Winbond) |
| Capacity | 16 MB (128 Mbit) |
| Interface | Quad SPI (QSPI) |
| Max Clock | 133 MHz |
| Package | 8-WSON (6 x 5 mm) |
| Erase Granularity | 4 KB sector / 32 KB block / 64 KB block |
| Write Granularity | 256 bytes (page program) |
| Endurance | 100,000 erase cycles per sector  |

The external flash is connected to the RP2354B's dedicated QSPI interface and can be
used for additional program storage, file systems (e.g., LittleFS), or data logging.

### 5.3 External EEPROM (AT24C256C)

| Parameter | Value |
|---|---|
| Part Number | AT24C256C-XHL-T (Microchip) |
| Capacity | 256 kbit (32,768 x 8 bytes) |
| Interface | I2C (shared with I2C0) |
| I2C Address | 0x50 (A0 = A1 = GND) |
| Max Clock | 400 kHz (Fast mode) |
| Write Page Size | 64 bytes |
| Write Cycle Time | 5 ms (max) |
| Endurance | 1,000,000 write cycles |
| Data Retention | 200+ years |
| Package | 8-TSSOP |
| Pull-Up Resistors | 4.7 kOhm on SDA and SCL |

The EEPROM is connected to I2C0 on GPIO32/33, which are internal to the module and
not routed to the M.2 connector. When I2C0 is used on a different pin pair via the
M.2 edge connector, it operates on a physically separate bus - address 0x50 is fully
available on the carrier board side. The EEPROM is ideal for storing configuration
data, calibration values, serial numbers, or small persistent datasets.

## 6. CAN Interface

### 6.1 MCP2515 CAN Controller Overview

| Parameter | Value |
|---|---|
| Part Number | MCP2515T-I/ML (Microchip) |
| Standard | CAN 2.0B (active) |
| Message Buffers | 3 TX, 2 RX (with 6 acceptance filters) |
| Interface to MCU | SPI (up to 10 MHz) |
| Crystal | 16 MHz, 8 pF load |
| Package | QFN-20 (4 x 4 mm) |
| Operating Temp | -40 degC to +85 degC |

The MCP2515 is a stand-alone CAN controller with an SPI interface.  It implements
the CAN 2.0B protocol, supporting both standard (11-bit) and extended (29-bit)
identifiers.  Message filtering and buffering are handled in hardware.

### 6.2 TCAN1044A CAN Transceiver

| Parameter | Value |
|---|---|
| Part Number | TCAN1044AVDRBRQ1 (Texas Instruments) |
| Standard | CAN 2.0 / CAN FD (physical layer) |
| Data Rate | Up to 5 Mbps (CAN FD capable) |
| Supply Voltage | 3.3 V |
| Bus Fault Protection| +/-58 V |
| Package | HVSON-8 (3 x 3 mm) |
| Operating Temp | -40 degC to +125 degC |
| Automotive Qualified| Yes (AEC-Q100) |

The TCAN1044A converts the MCP2515 logic-level TX/RX signals to differential
CAN bus levels (CANH / CANL).

### 6.3 SPI Connection to MCU

| Signal | GPIO | Direction (MCU view) |
|---|---|---|
| MISO | GPIO28 | Input |
| CS | GPIO29 | Output |
| SCK | GPIO30 | Output |
| MOSI | GPIO31 | Output |

These GPIO are used internally and are NOT available on the M.2 connector for
user applications.

| Control  | GPIO | Function |
|---|---|---|
| RST | GPIO34 | Hardware reset (active low) |
| INT | GPIO35 | Interrupt output (active low) |

**SPI Configuration:**
- SPI Instance: SPI1
- Baudrate: 10 MHz (default in CONFIG.h)
- Mode: SPI Mode 0 (CPOL=0, CPHA=0)

### 6.4 CAN Bus Signals on M.2 Connector

| M.2 Pin | Signal | Description |
|---|---|---|
| 28 | CAN_P | CAN High (CANH) |
| 30 | CAN_N | CAN Low (CANL) |

The carrier board connects these pins to the CAN bus through an appropriate
connector (e.g., screw terminal, DB-9, or pin header).

### 6.5 Bus Termination

The module includes onboard split termination:

- R35: 60.4 Ohm (CANH to midpoint)
- R36: 60.4 Ohm (CANL to midpoint)
- Total differential termination: ~120 Ohm (standard CAN bus termination)

> **Note:** The onboard termination is suitable when the module is at one end of
> the CAN bus.  For mid-bus installations, the termination resistors should be
> removed (depopulated) and termination provided at both physical ends of the bus.

### 6.6 Signal Conditioning

- **Common Mode Choke:** ACT1210D-101-2P-TL00 (TDK), 100 uH at 100 kHz,
  1210 package.  Suppresses common-mode noise on the CAN differential pair.
- **Coupling Capacitors:** C34, C35 (47 pF, optional / DNI).  May improve EMC
  performance but can degrade signal integrity at higher bit rates -- evaluate
  on the target application.

### 6.7 ESD Protection

- **Device:** PESD2CANFD24V-UX (Nexperia)
- **Rating:** 24 V, dual-channel ESD protection for CAN FD bus lines
- **Package:** SOC-75 (SOT-523)

### 6.8 Reference Crystal

- Frequency: 16 MHz
- Load Capacitance: 8 pF
- Package: SMD 2016 (2.0 x 1.6 mm)

## 7. USB Interface

### 7.1 Dual-Path Architecture

BladeCore-M54C provides two physical USB connection paths:

1. **M.2 edge connector USB** -- for connection through the carrier board
2. **Onboard USB-C connector** -- for direct access during development or provisioning

A **FSUSB42MUX** (OnSemi) USB 2.0 multiplexer automatically selects the active path:

| Condition | Active USB Path |
|---|---|
| No USB-C cable connected | M.2 edge connector |
| USB-C cable connected | Onboard USB-C |

This selection is automatic -- no firmware intervention or manual jumper configuration
is required.

### 7.2 M.2 USB Signals

| M.2 Pin | Signal | Description |
|---|---|---|
| 69 | USB_D+ | USB Data + |
| 71 | USB_D- | USB Data - |
| 72, 74  | VBUS | USB VBUS (5V) |
| 75 | VBUS | USB VBUS (5V) |

### 7.3 USB-C Connector

- Type: USB-TYPE-C-018 receptacle
- Supports plugging/unplugging during operation (hot-swap)
- CC resistors onboard for proper USB-C enumeration
- ESD protection: SP0503BAHTG on data lines

### 7.4 USB VBUS Sensing

The USB VBUS voltage is monitored via GPIO46 (ADC6) through a resistive voltage divider:

- Divider: 5.1 kOhm / 5.1 kOhm
- ADC input voltage at 5.0 V VBUS: ~2.5 V
- Formula: VBUS = ADC_reading * (3.0 / 4096) * 2

This allows firmware to detect whether USB power is present and measure the
actual VBUS voltage.

## 8. Power Management

### 8.1 Power Input Options

BladeCore-M54C can be powered through four paths:

| Source | Input Pins | Path |
|---|---|---|
| M.2 5 V | Pins 14, 16 (+5V INPUT) | 5 V -> TPS74801 LDO -> 3.3 V rail |
| M.2 VBUS | Pins 72, 74, 75 (VBUS) | VBUS -> TPS74801 LDO -> 3.3 V rail |
| Onboard USB-C | USB-C connector | VBUS -> TPS74801 LDO -> 3.3 V rail |
| External 3.3 V | Pins 10, 12 (+3.3V OUTPUT) | Direct to 3.3 V rail (LDO bypassed) |

### 8.2 3.3 V Output to Carrier Board

When the module is powered from 5 V (pins 14/16, VBUS, or USB-C), the regulated
3.3 V rail is provided back to the carrier board on M.2 pins 10 and 12
(+3.3V OUTPUT).  The LDO can supply **1.5 A** total.  Each M.2 contact is rated
for 0.5 A, so with two pins the connector limits the carrier board output to
**1 A**.  The remaining 0.5 A is the module's own budget, of which ~55 mA is
typically consumed (with CAN active).

When the module is powered externally at 3.3 V on these same pins, the carrier
board supplies both the module and itself -- the LDO is not active in this mode.

### 8.3 Voltage Regulator -- TPS74801DRCT

| Parameter | Value |
|---|---|
| Type | Low-Dropout (LDO) |
| Output Voltage | 3.3 V |
| Max Output Current | 1.5 A |
| Dropout Voltage | 110 mV typical |
| Package | VSON-10-1EP (3x3 mm) |
| Enable Pin | VEN (active high) |
| Power-Good Output | PGOOD (open drain) |

### 8.4 Power-Good Indication

The LDO provides a PGOOD signal that goes high once the output voltage reaches
regulation. This signal is buffered through an **SN74LVC1G97QDCKRQ1** logic gate
before driving an onboard green LED (visual indicator).

### 8.5 Onboard Voltage Reference

A precision **LM4040B30FTA** (3.000 V, +/-0.1%) voltage reference is connected
to GPIO47 (ADC7) through a 10K / 10K voltage divider. This enables:
- ADC calibration at runtime (known reference voltage)
- Detection of supply rail drift
- High-accuracy analog measurements

**To calibrate the ADC:**
```
Expected ADC reading for 3.0V reference through 10K/10K divider:
  VADC = 3.0 / 2 = 1.5 V
  Expected ADC code = 1.5 / 3.0 * 4096 = ~2048

  Calibration factor = 2048 / actual_adc_reading
  Apply this factor to all subsequent ADC readings.
```

## 9. M.2 Connector Pinout

### 9.1 Left Side (Odd Pins)

| Pin | Signal  | GPIO | Alternate Functions |
|-----|---|---|---|
| 1 | GND | -- | Ground |
| 3 | GPIO24  | GPIO24 | SPI0 TX, UART1 RTS, I2C1 SCL, PWM3 B, PIO0/1/2 |
| 5 | GPIO23  | GPIO23 | SPI0 TX, UART1 RTS, I2C1 SCL, PWM3 B, PIO0/1/2 |
| 7 | GPIO22  | GPIO22 | SPI0 SCK, UART1 CTS, I2C1 SDA, PWM3 A, PIO0/1/2 |
| 9 | GPIO21  | GPIO21 | SPI0 CSn, UART1 RX, I2C0 SCL, PWM2 B, PIO0/1/2 |
| 11  | GND | -- | Ground |
| 13  | GPIO20  | GPIO20 | SPI0 RX, UART1 TX, I2C0 SDA, PWM2 A, PIO0/1/2 |
| 15  | GPIO19  | GPIO19 | SPI0 TX, UART0 RTS, I2C1 SCL, PWM1 B, QMI CS1n |
| 17  | GPIO18  | GPIO18 | SPI0 SCK, UART0 CTS, I2C1 SDA, PWM1 A, PIO0/1/2 |
| 19  | GPIO17  | GPIO17 | SPI0 CSn, UART0 RX, I2C0 SCL, PWM0 B, PIO0/1/2 |
| 21  | GPIO16  | GPIO16 | SPI0 RX, UART0 TX, I2C0 SDA, PWM0 A, PIO0/1/2 |
| 23  | GND | -- | Ground |
| 25  | GPIO15  | GPIO15 | SPI1 TX, UART0 RTS, I2C1 SCL, PWM7 B, PIO0/1/2 |
| 27  | GPIO14  | GPIO14 | SPI1 SCK, UART0 CTS, I2C1 SDA, PWM7 A, PIO0/1/2 |
| 29  | GPIO13  | GPIO13 | SPI1 CSn, UART0 RX, I2C0 SCL, PWM6 B, PIO0/1/2 |
| 31  | GPIO12  | GPIO12 | SPI1 RX, UART0 TX, I2C0 SDA, PWM6 A, PIO0/1/2 |
| 33  | GPIO11  | GPIO11 | SPI1 TX, UART1 RTS, I2C1 SCL, PWM5 B, PIO0/1/2 |
| 35  | GPIO10  | GPIO10 | SPI1 SCK, UART1 CTS, I2C1 SDA, PWM5 A, PIO0/1/2 |
| 37  | GPIO9 | GPIO9  | SPI1 CSn, UART1 RX, I2C0 SCL, PWM4 B, PIO0/1/2 |
| 39  | GPIO8 | GPIO8  | SPI1 RX, UART1 TX, I2C0 SDA, PWM4 A, QMI CS1n |
| 41  | GND | -- | Ground |
| 43  | GPIO7 | GPIO7  | SPI0 TX, UART1 RTS, I2C1 SCL, PWM3 B, PIO0/1/2 |
| 45  | GPIO6 | GPIO6  | SPI0 SCK, UART1 CTS, I2C1 SDA, PWM3 A, PIO0/1/2 |
| 47  | GPIO5 | GPIO5  | SPI0 CSn, UART1 RX, I2C0 SCL, PWM2 B, PIO0/1/2 |
| 49  | GPIO4 | GPIO4  | SPI0 RX, UART1 TX, I2C0 SDA, PWM2 A, PIO0/1/2 |
| 51  | GPIO3 | GPIO3  | SPI0 TX, UART0 RTS, I2C1 SCL, PWM1 B, PIO0/1/2 |
| 53  | GPIO2 | GPIO2  | SPI0 SCK, UART0 CTS, I2C1 SDA, PWM1 A, PIO0/1/2 |
| 55  | GPIO1 | GPIO1  | SPI0 CSn, UART0 RX, I2C0 SCL, PWM0 B, TRACECLK |
| 57  | GPIO0 | GPIO0  | SPI0 RX, UART0 TX, I2C0 SDA, PWM0 A, QMI CS1n |
| 67  | GND | -- | Ground |
| 69  | USB_D+  | -- | USB Data Plus |
| 71  | USB_D-  | -- | USB Data Minus |
| 73  | GND | -- | Ground |
| 75  | VBUS | -- | USB VBUS (5 V) |

### 9.2 Right Side (Even Pins)

| Pin | Signal | GPIO | Notes |
|-----|---|---|---|
| 2 | GND | -- | Ground |
| 4 | GPIO27 | GPIO27 | SPI1 TX, UART1 RTS, I2C1 SCL, PWM5 B |
| 6 | GPIO26 | GPIO26 | SPI1 SCK, UART1 CTS, I2C1 SDA, PWM5 A |
| 8 | GPIO25 | GPIO25 | SPI1 CSn, UART1 RX, I2C0 SCL, PWM4 B |
| 10  | +3.3V OUTPUT| -- | 3.3 V LDO output / external 3.3 V input |
| 12  | +3.3V OUTPUT| -- | 3.3 V LDO output / external 3.3 V input |
| 14  | +5V INPUT | -- | 5 V power input to module |
| 16  | +5V INPUT | -- | 5 V power input to module |
| 18  | GND | -- | Ground |
| 20  | GND | -- | Ground |
| 22  | GND | -- | Ground |
| 24  | GND | -- | Ground |
| 26  | GND | -- | Ground |
| 28  | CAN_P | -- | CAN High (CANH) |
| 30  | CAN_N | -- | CAN Low (CANL) |
| 32  | GND | -- | Ground |
| 34  | GPIO37 | GPIO37 | SPI0 CSn, UART1 RX, I2C0 SCL, PWM2 B, PIO0/1/2 |
| 36  | GPIO38 | GPIO38 | SPI0 RX, UART1 TX, I2C0 SDA, PWM3 A, PIO0/1/2  |
| 38  | GND | -- | Ground |
| 40  | GPIO39 | GPIO39 | SPI0 TX, UART1 RTS, I2C1 SCL, PWM3 B, PIO0/1/2 |
| 42  | GND | -- | Ground |
| 44  | GND | -- | Ground |
| 46  | ADC0/GPIO40 | GPIO40 | Analog/digital, PWM8 A, SPI1, UART1, I2C0 |
| 48  | ADC1/GPIO41 | GPIO41 | Analog/digital, PWM8 B, SPI1, UART1, I2C0 |
| 50  | ADC2/GPIO42 | GPIO42 | Analog/digital, PWM9 A, SPI1, UART1, I2C1 |
| 52  | ADC3/GPIO43 | GPIO43 | Analog/digital, PWM9 B, SPI1, UART1, I2C1 |
| 54  | ADC4/GPIO44 | GPIO44 | Analog/digital, PWM10 A, SPI1, UART0, I2C0 |
| 56  | ADC5/GPIO45 | GPIO45 | Analog/digital, PWM10 B, SPI1, UART0, I2C0 |
| 58  | GND | -- | Ground |
| 68  | GND | -- | Ground |
| 70  | GND | -- | Ground |
| 72  | VBUS | -- | USB VBUS (5 V) |
| 74  | VBUS | -- | USB VBUS (5 V) |
| SH1 | SHIELD | -- | Shield / Ground |

### 9.3 Important Notes

- **SPI1** (GPIO8--15, GPIO25--31, GPIO40--45) overlaps with both user-accessible
  pins and the onboard MCP2515.  GPIO28--31 are dedicated to the MCP2515 and are
  **not** available on the M.2 connector.  User code must avoid configuring
  GPIO28--31 for other purposes.
- **I2C0** can be used on any M.2-accessible GPIO with an I2C0 alternate function.
  The onboard EEPROM uses GPIO32--33, which are not wired to the M.2 connector,
  so the carrier board's I2C0 bus is physically independent.
- **CAN bus** signals (CAN_P, CAN_N) on M.2 pins 28 and 30 are directly from
  the TCAN1044A transceiver -- these are not GPIO-controlled.

## 10. Onboard Peripherals

### 10.1 Heartbeat LED

| Parameter | Value |
|---|---|
| GPIO | GPIO36 |
| Color | Blue |
| Package | 0402 (1005 Metric) |
| Series Resistor| 1000 Ohm |
| PWM Slice | Slice 2, Channel A |
| PWM Frequency | 1000 Hz (configurable) |

The heartbeat LED is intended as a visual "alive" indicator.  It can be driven
with simple digital on/off or with hardware PWM for breathing/fading effects.

### 10.2 Reset Buttons

Two tactile switches (B3U-1000P, Omron) are provided on the board for manual
reset and boot-mode selection.

### 10.3 Status LEDs

| LED | Color | Designator | Function |
|---|---|---|---|
| +5V | Green | D10 | Connected to VIN_PWR; active when VBUS or +5V is present |
| PGOOD | Green | D6 | Driven via SN74LVC1G97 buffer; active when 3.3V is OK |
| VBUS | Green | D11 | Monitors onboard USB-C VBUS |
| Heartbeat | Blue  | D3 | Connected to MCU GPIO36; PWM breathing indicator |

### 10.4 ESD Protection

| Device | Protection |
|---|---|
| SP0503BAHTG | USB data line ESD clamping |
| RCLAMP0582BQTCT | General I/O ESD clamping |
| PESD2CANFD24V-UX | CAN bus line ESD clamping |

## 11. Power-Up Sequencing

The board follows a defined power-up sequence with the following timeline:

| Step | Event | Time (cumulative) |
|---|---|---|
| 1 | VIN applied (5.0 V) | 0 ms |
| 2 | VEN asserted (TPS74801 enables) | 0 ms |
| 3 | VOUT (3.3 V) reaches regulation | ~4 ms (soft-start) |
| 4 | PGOOD asserts (power-good valid) | ~4 ms |
| 5 | RP2354B 3.3 V rail stable | ~4 ms |
| 6 | RP2354B 1.1 V core valid (POR) | ~4.01 ms |
| 7 | RP2354B ready for execution | ~4.09 ms |
| 8 | MCP2515 ready after reset | ~4.13 ms |

> **Note:** The MCP2515 requires a minimum 2 us reset pulse width.  After
> deasserting the reset pin, the oscillator start-up time depends on the 16 MHz
> crystal -- typically under 1 ms.  Firmware should wait at least 1 ms after
> releasing the MCP2515 reset before attempting SPI communication.

## 12. Getting Started -- Software

### 12.1 Prerequisites

- **Raspberry Pi Pico SDK** version 2.2.0 or later
- **ARM GCC Toolchain** version 14.2 or later
- **CMake** version 3.13 or later
- **Picotool** version 2.2.0 or later (for UF2 flashing)
- A USB cable (USB-C or via carrier board M.2 connection)

### 12.2 Environment Setup (Windows)

1. Install the [Raspberry Pi Pico VS Code Extension](https://marketplace.visualstudio.com/items?itemName=raspberry-pi.raspberry-pi-pico)
   which automatically installs and manages the SDK, toolchain, and picotool.

2. Alternatively, install manually:
   ```
   # Install Pico SDK
   git clone https://github.com/raspberrypi/pico-sdk.git
   cd pico-sdk
   git checkout 2.2.0
   git submodule update --init

   # Set environment variable
   set PICO_SDK_PATH=C:\path\to\pico-sdk
   ```

### 12.3 Building the Heartbeat Example

```
cd src/Software/Heartbeat

mkdir build
cd build

cmake -G "Ninja" ..
ninja
```

This produces `Heartbeat.uf2` in the build directory.

### 12.4 Flashing Firmware

1. Hold the BOOTSEL button on the RP2354B while connecting USB (or pressing reset).
2. The board enumerates as a USB mass storage device (RP2350 drive).
3. Copy the `.uf2` file to the drive:
   ```
   copy Heartbeat.uf2 E:\
   ```
   (Replace `E:\` with the actual drive letter.)
4. The board automatically reboots and begins executing.

Alternatively, use picotool:
```
picotool load Heartbeat.uf2
picotool reboot
```

### 12.5 Serial Monitor (USB CDC)

The Heartbeat example enables USB stdio output. Connect a terminal at any baud
rate (USB CDC is rate-independent):

```
# Using PuTTY, Tera Term, or any serial monitor
# Select the COM port assigned to the Pico
```

## 13. Programming Guide

### 13.1 Pin Configuration Header

All pin assignments are centralized in `CONFIG.h`.  Always use these definitions
instead of hardcoding GPIO numbers:

```c
#include "CONFIG.h"

// CAN SPI
PIN_CAN_MISO    // GPIO28 - SPI1 RX
PIN_CAN_CS      // GPIO29 - SPI1 CSn
PIN_CAN_SCK     // GPIO30 - SPI1 SCK
PIN_CAN_MOSI    // GPIO31 - SPI1 TX

// I2C EEPROM
PIN_I2C0_SDA    // GPIO32
PIN_I2C0_SCL    // GPIO33

// CAN control
PIN_CAN_RST     // GPIO34 - MCP2515 reset (active low)
PIN_CAN_INT     // GPIO35 - MCP2515 interrupt (active low)

// Heartbeat LED
PIN_HEARTBEAT   // GPIO36

// ADC
PIN_ADC_VUSB    // GPIO46 / ADC6 - USB VBUS sense
PIN_ADC_VREF    // GPIO47 / ADC7 - Voltage reference
```

### 13.2 SPI1 -- CAN Controller (MCP2515)

```c
#include "hardware/spi.h"
#include "CONFIG.h"

void mcp2515_spi_init(void) {
    spi_init(CAN_SPI_INSTANCE, CAN_SPI_BAUDRATE);

    gpio_set_function(PIN_CAN_MISO, GPIO_FUNC_SPI);
    gpio_set_function(PIN_CAN_MOSI, GPIO_FUNC_SPI);
    gpio_set_function(PIN_CAN_SCK, GPIO_FUNC_SPI);

    // CS is managed manually (active low)
    gpio_init(PIN_CAN_CS);
    gpio_set_dir(PIN_CAN_CS, GPIO_OUT);
    gpio_put(PIN_CAN_CS, 1);  // Deselect

    // Reset pin
    gpio_init(PIN_CAN_RST);
    gpio_set_dir(PIN_CAN_RST, GPIO_OUT);
    gpio_put(PIN_CAN_RST, 1);  // Not in reset

    // Interrupt pin
    gpio_init(PIN_CAN_INT);
    gpio_set_dir(PIN_CAN_INT, GPIO_IN);
    gpio_pull_up(PIN_CAN_INT);
}

void mcp2515_reset(void) {
    gpio_put(PIN_CAN_RST, 0);
    sleep_us(10);         // Hold reset for at least 2 us
    gpio_put(PIN_CAN_RST, 1);
    sleep_ms(1);          // Wait for oscillator start-up
}

// MCP2515 SPI instruction: RESET
void mcp2515_soft_reset(void) {
    uint8_t cmd = 0xC0;  // RESET instruction
    gpio_put(PIN_CAN_CS, 0);
    spi_write_blocking(CAN_SPI_INSTANCE, &cmd, 1);
    gpio_put(PIN_CAN_CS, 1);
    sleep_ms(1);
}

// MCP2515 SPI instruction: READ register
uint8_t mcp2515_read_reg(uint8_t addr) {
    uint8_t tx[2] = {0x03, addr};  // READ instruction + address
    uint8_t rx = 0;
    gpio_put(PIN_CAN_CS, 0);
    spi_write_blocking(CAN_SPI_INSTANCE, tx, 2);
    spi_read_blocking(CAN_SPI_INSTANCE, 0x00, &rx, 1);
    gpio_put(PIN_CAN_CS, 1);
    return rx;
}

// MCP2515 SPI instruction: WRITE register
void mcp2515_write_reg(uint8_t addr, uint8_t value) {
    uint8_t tx[3] = {0x02, addr, value};  // WRITE instruction + address + data
    gpio_put(PIN_CAN_CS, 0);
    spi_write_blocking(CAN_SPI_INSTANCE, tx, 3);
    gpio_put(PIN_CAN_CS, 1);
}

// MCP2515 SPI instruction: BIT MODIFY register
void mcp2515_bit_modify(uint8_t addr, uint8_t mask, uint8_t value) {
    uint8_t tx[4] = {0x05, addr, mask, value};
    gpio_put(PIN_CAN_CS, 0);
    spi_write_blocking(CAN_SPI_INSTANCE, tx, 4);
    gpio_put(PIN_CAN_CS, 1);
}
```

### 13.3 I2C0 -- EEPROM (AT24C256)

```c
#include "hardware/i2c.h"
#include "CONFIG.h"

void eeprom_init(void) {
    i2c_init(EEPROM_I2C_INSTANCE, EEPROM_I2C_BAUDRATE);
    gpio_set_function(PIN_I2C0_SDA, GPIO_FUNC_I2C);
    gpio_set_function(PIN_I2C0_SCL, GPIO_FUNC_I2C);
    // External 4.7K pull-ups are on the board -- no internal pull-ups needed
}

// Write up to 64 bytes (one EEPROM page) at a time
int eeprom_write(uint16_t mem_addr, const uint8_t *data, size_t len) {
    uint8_t buf[66];  // 2 address bytes + 64 data bytes max
    buf[0] = (uint8_t)(mem_addr >> 8);
    buf[1] = (uint8_t)(mem_addr & 0xFF);

    if (len > 64) len = 64;
    for (size_t i = 0; i < len; i++) {
        buf[2 + i] = data[i];
    }

    int ret = i2c_write_blocking(EEPROM_I2C_INSTANCE, EEPROM_I2C_ADDR,
                                  buf, 2 + len, false);
    sleep_ms(5);  // Wait for write cycle to complete
    return ret;
}

// Read arbitrary number of bytes
int eeprom_read(uint16_t mem_addr, uint8_t *data, size_t len) {
    uint8_t addr_buf[2];
    addr_buf[0] = (uint8_t)(mem_addr >> 8);
    addr_buf[1] = (uint8_t)(mem_addr & 0xFF);

    int ret = i2c_write_blocking(EEPROM_I2C_INSTANCE, EEPROM_I2C_ADDR,
                                  addr_buf, 2, true);  // No stop
    if (ret < 0) return ret;

    return i2c_read_blocking(EEPROM_I2C_INSTANCE, EEPROM_I2C_ADDR,
                              data, len, false);
}
```

### 13.4 ADC -- Voltage Monitoring

```c
#include "hardware/adc.h"
#include "CONFIG.h"

void adc_monitoring_init(void) {
    adc_init();
    adc_gpio_init(PIN_ADC_VUSB);  // GPIO46 / ADC6
    adc_gpio_init(PIN_ADC_VREF);  // GPIO47 / ADC7
}

// Read USB VBUS voltage (5V nominal)
float read_vbus_voltage(void) {
    adc_select_input(6);  // ADC6 = GPIO46
    adc_read();           // Throwaway sample after channel switch
    uint16_t raw = adc_read();
    // 5.1K / 5.1K divider, factor = 2
    return (float)raw * 3.0f / 4096.0f * 2.0f;
}

// Read precision voltage reference (3.0V nominal)
float read_vref(void) {
    adc_select_input(7);  // ADC7 = GPIO47
    adc_read();           // Throwaway sample after channel switch
    uint16_t raw = adc_read();
    // 10K / 10K divider, factor = 2
    return (float)raw * 3.0f / 4096.0f * 2.0f;
}

// Calculate ADC calibration factor using known reference
float get_adc_calibration_factor(void) {
    adc_select_input(7);
    adc_read();           // Throwaway sample after channel switch
    uint16_t raw = adc_read();
    float measured = (float)raw * 3.0f / 4096.0f * 2.0f;
    return 3.0f / measured;  // Ratio of known vs measured
}
```

### 13.5 PWM -- Heartbeat LED

```c
#include "hardware/pwm.h"
#include "hardware/clocks.h"
#include "CONFIG.h"

#define PWM_WRAP 65535

void heartbeat_init(void) {
    gpio_set_function(PIN_HEARTBEAT, GPIO_FUNC_PWM);

    uint slice = pwm_gpio_to_slice_num(PIN_HEARTBEAT);
    pwm_config cfg = pwm_get_default_config();

    float divider = (float)clock_get_hz(clk_sys) /
                    ((float)HEARTBEAT_PWM_FREQ_HZ * (PWM_WRAP + 1));
    if (divider < 1.0f) divider = 1.0f;

    pwm_config_set_clkdiv(&cfg, divider);
    pwm_config_set_wrap(&cfg, PWM_WRAP);
    pwm_init(slice, &cfg, true);
    pwm_set_chan_level(slice, pwm_gpio_to_channel(PIN_HEARTBEAT), 0);
}

// Set LED brightness: 0 = off, 65535 = full
void heartbeat_set(uint16_t brightness) {
    uint slice = pwm_gpio_to_slice_num(PIN_HEARTBEAT);
    uint channel = pwm_gpio_to_channel(PIN_HEARTBEAT);
    pwm_set_chan_level(slice, channel, brightness);
}
```

### 13.6 UART (via M.2 Connector)

```c
#include "hardware/uart.h"

// Example: UART0 on GPIO0 (TX) and GPIO1 (RX) -- M.2 pins 57 and 55
void uart_example_init(void) {
    uart_init(uart0, 115200);
    gpio_set_function(0, GPIO_FUNC_UART);  // UART0 TX
    gpio_set_function(1, GPIO_FUNC_UART);  // UART0 RX
}
```

### 13.7 CMakeLists.txt Template

```cmake
cmake_minimum_required(VERSION 3.13)

set(CMAKE_C_STANDARD 11)
set(CMAKE_CXX_STANDARD 17)
set(CMAKE_EXPORT_COMPILE_COMMANDS ON)

# Pico SDK integration (VS Code extension auto-config)
if(WIN32)
    set(USERHOME $ENV{USERPROFILE})
else()
    set(USERHOME $ENV{HOME})
endif()
set(sdkVersion 2.2.0)
set(toolchainVersion 14_2_Rel1)
set(picotoolVersion 2.2.0-a4)
set(picoVscode ${USERHOME}/.pico-sdk/cmake/pico-vscode.cmake)
if (EXISTS ${picoVscode})
    include(${picoVscode})
endif()

set(PICO_BOARD pico2 CACHE STRING "Board type")

include(pico_sdk_import.cmake)

project(MyProject C CXX ASM)
pico_sdk_init()

add_executable(MyProject main.c)

pico_set_program_name(MyProject "MyProject")
pico_set_program_version(MyProject "0.1")

# Enable USB output, disable UART output
pico_enable_stdio_uart(MyProject 0)
pico_enable_stdio_usb(MyProject 1)

target_link_libraries(MyProject
    pico_stdlib
    hardware_spi       # For MCP2515 CAN controller
    hardware_i2c       # For EEPROM
    hardware_adc       # For ADC monitoring
    hardware_pwm       # For heartbeat LED
)

target_include_directories(MyProject PRIVATE
    ${CMAKE_CURRENT_LIST_DIR}
)

pico_add_extra_outputs(MyProject)
```

## 14. Code Examples

### 14.1 Heartbeat LED (Breathing Effect)

The included `Heartbeat.c` example demonstrates a smooth PWM breathing pattern on
the onboard blue LED.  See `src/Software/Heartbeat/` for the complete project.

**Behavior:** The LED linearly fades from off to full brightness and back over
approximately 2 seconds (128 steps x 2 directions x 8 ms per step).

### 14.2 Minimal MCP2515 CAN Initialization

```c
#include <stdio.h>
#include "pico/stdlib.h"
#include "hardware/spi.h"
#include "CONFIG.h"

int main(void) {
    stdio_init_all();

    // Initialize SPI1 for MCP2515
    spi_init(CAN_SPI_INSTANCE, CAN_SPI_BAUDRATE);
    gpio_set_function(PIN_CAN_MISO, GPIO_FUNC_SPI);
    gpio_set_function(PIN_CAN_MOSI, GPIO_FUNC_SPI);
    gpio_set_function(PIN_CAN_SCK, GPIO_FUNC_SPI);

    gpio_init(PIN_CAN_CS);
    gpio_set_dir(PIN_CAN_CS, GPIO_OUT);
    gpio_put(PIN_CAN_CS, 1);

    // Hardware reset the MCP2515
    gpio_init(PIN_CAN_RST);
    gpio_set_dir(PIN_CAN_RST, GPIO_OUT);
    gpio_put(PIN_CAN_RST, 0);
    sleep_us(10);
    gpio_put(PIN_CAN_RST, 1);
    sleep_ms(1);

    // Software reset (puts MCP2515 into Configuration mode)
    uint8_t reset_cmd = 0xC0;
    gpio_put(PIN_CAN_CS, 0);
    spi_write_blocking(CAN_SPI_INSTANCE, &reset_cmd, 1);
    gpio_put(PIN_CAN_CS, 1);
    sleep_ms(1);

    // Read CANSTAT register (address 0x0E) to verify Configuration mode
    uint8_t tx[2] = {0x03, 0x0E};  // READ instruction + CANSTAT address
    uint8_t canstat = 0;
    gpio_put(PIN_CAN_CS, 0);
    spi_write_blocking(CAN_SPI_INSTANCE, tx, 2);
    spi_read_blocking(CAN_SPI_INSTANCE, 0x00, &canstat, 1);
    gpio_put(PIN_CAN_CS, 1);

    printf("MCP2515 CANSTAT: 0x%02X (expected 0x80 = Config mode)\n", canstat);

    while (true) {
        tight_loop_contents();
    }
}
```

### 14.3 EEPROM Read/Write Test

```c
#include <stdio.h>
#include <string.h>
#include "pico/stdlib.h"
#include "hardware/i2c.h"
#include "CONFIG.h"

int main(void) {
    stdio_init_all();
    sleep_ms(2000);  // Wait for USB enumeration

    // Initialize I2C0
    i2c_init(EEPROM_I2C_INSTANCE, EEPROM_I2C_BAUDRATE);
    gpio_set_function(PIN_I2C0_SDA, GPIO_FUNC_I2C);
    gpio_set_function(PIN_I2C0_SCL, GPIO_FUNC_I2C);

    // Write test data to EEPROM address 0x0000
    uint8_t write_buf[] = {0x00, 0x00, 'H', 'e', 'l', 'l', 'o'};
    int ret = i2c_write_blocking(EEPROM_I2C_INSTANCE, EEPROM_I2C_ADDR,
                                  write_buf, sizeof(write_buf), false);
    printf("Write returned: %d\n", ret);
    sleep_ms(5);  // EEPROM write cycle

    // Read back
    uint8_t addr_buf[] = {0x00, 0x00};
    i2c_write_blocking(EEPROM_I2C_INSTANCE, EEPROM_I2C_ADDR,
                        addr_buf, 2, true);

    uint8_t read_buf[5] = {0};
    i2c_read_blocking(EEPROM_I2C_INSTANCE, EEPROM_I2C_ADDR,
                       read_buf, 5, false);

    printf("Read back: %c%c%c%c%c\n",
           read_buf[0], read_buf[1], read_buf[2],
           read_buf[3], read_buf[4]);

    while (true) {
        tight_loop_contents();
    }
}
```

### 14.4 ADC Calibration and VBUS Monitoring

```c
#include <stdio.h>
#include "pico/stdlib.h"
#include "hardware/adc.h"
#include "CONFIG.h"

int main(void) {
    stdio_init_all();
    sleep_ms(2000);

    adc_init();
    adc_gpio_init(PIN_ADC_VUSB);
    adc_gpio_init(PIN_ADC_VREF);

    // Calibrate using onboard 3.0V reference
    adc_select_input(7);  // ADC7 = GPIO47 (VREF)
    adc_read();           // Throwaway sample after channel switch
    uint16_t ref_raw = adc_read();
    float ref_measured = (float)ref_raw * 3.0f / 4096.0f * 2.0f;
    float cal_factor = 3.0f / ref_measured;

    printf("Reference ADC raw: %u\n", ref_raw);
    printf("Measured: %.3f V (expected 3.000 V)\n", ref_measured);
    printf("Calibration factor: %.4f\n", cal_factor);

    while (true) {
        // Read VBUS
        adc_select_input(6);  // ADC6 = GPIO46 (VUSB)
        adc_read();           // Throwaway sample after channel switch
        uint16_t vbus_raw = adc_read();
        float vbus = (float)vbus_raw * 3.0f / 4096.0f * 2.0f * cal_factor;

        printf("VBUS: %.2f V (raw: %u)\n", vbus, vbus_raw);
        sleep_ms(1000);
    }
}
```

## 15. Design Considerations for Carrier Boards

### 15.1 CAN Bus Wiring

The carrier board connects the CAN bus signals from the M.2 connector to a bus
connector (screw terminal, DB-9, pin header, etc.):

- **CAN_P (CANH):** M.2 pin 28
- **CAN_N (CANL):** M.2 pin 30

Use a twisted pair or close-routed differential pair for the CAN bus traces.
Keep stub lengths as short as possible to minimize reflections.

### 15.2 Power Supply Design

- **5 V mode:** Provide stable 5 V on M.2 pins 14 and 16 (+5V INPUT).
  Minimum current capacity: 300 mA (to support MCU + MCP2515 + TCAN1044A + peripherals).
  Recommended: 1 A or more if the carrier board also draws from the 3.3 V output.
  M.2 pins 10 and 12 provide **3.3 V output** from the onboard LDO (up to 1 A
  available for carrier board electronics).
- **External 3.3 V mode:** Supply regulated 3.3 V on M.2 pins 10 and 12.
  The carrier board supplies all current (module draws ~55 mA
  typical with CAN active).
- Add bulk capacitance (47-100 uF) near the M.2 connector on the carrier board.

### 15.3 USB Routing

- Route USB_D+ (pin 69) and USB_D- (pin 71) as a 90 Ohm differential pair.
- Keep trace lengths matched.
- Provide VBUS on pins 72, 74, 75 if USB-powered operation is desired.

### 15.4 I2C Bus Extension

- I2C0 can be used on any M.2-accessible GPIO with the I2C0 alternate function.
  The onboard EEPROM (GPIO32--33) is not wired to the M.2 connector, so the
  carrier board operates on a physically separate I2C bus -- all addresses
  including 0x50 are available.
- Total bus capacitance should not exceed 400 pF for reliable 400 kHz operation.

### 15.5 SPI Bus Sharing

- SPI1 is occupied by the MCP2515 (GPIO28--31, directly on the module).
- SPI0 is fully available on the M.2 connector (multiple GPIO options).
- If using SPI1 on M.2 GPIO pins (GPIO8--15, GPIO25--27, GPIO40--45),
  make sure the MCP2515 CS (GPIO29) is deasserted (high) to avoid bus contention.

### 15.6 CAN Bus Termination

- The module includes onboard 120 Ohm split termination (2x 60.4 Ohm).
- If the module is at one end of the CAN bus, onboard termination is sufficient.
- For mid-bus placement, remove the onboard termination resistors (R35, R36) and
  provide 120 Ohm termination at both physical ends of the bus.
- Maximum recommended bus length depends on bit rate:
  - 1 Mbps: ~25 m
  - 500 kbps: ~100 m
  - 125 kbps: ~500 m

## 16. Mechanical Specifications

| Parameter | Value |
|---|---|
| Form Factor | M.2 2980 M-Key |
| Card Dimensions | 29 mm x 80 mm |
| Thickness | ~1.6 mm (6-layer PCB) |
| Edge Connector | M-Key (75 pins) |
| Mating Connector | MDT420E03001 (or equiv) |
| Mounting | M2.5 threaded standoff  |
| Weight | < 10 g |

## 17. Absolute Maximum Ratings

Exceeding absolute maximum ratings may cause permanent damage to the module.

| Parameter | Rating |
|---|---|
| VIN (5 V input) | -0.3 to 6.0 V  |
| VCC (3.3 V rail) | -0.3 to 3.6 V  |
| GPIO voltage (any pin) | -0.3 to 3.63 V |
| Maximum GPIO source current  | 12 mA per pin |
| Maximum total GPIO current | 50 mA |
| Storage Temperature | -40 to +85 degC |
| Operating Temperature | -20 to +70 degC |
| ESD (HBM) | 2 kV |

> **Caution:** The RP2354B GPIOs are **NOT** 5 V tolerant.  All signal levels
> connected to the M.2 connector must be 3.3 V logic.  Use level shifters on
> the carrier board if interfacing with 5 V systems.

## 18. Revision History

| Revision | Date | Notes |
|---|---|---|
| 1.0.0 | 2026-01-31 | Initial creation |

*This document is derived from the BladeCore-M54C schematics (v1.0.0) and
associated design files. Component-level limits and behavior should be verified
against the respective datasheets. For the latest information, refer to the
project repository.*

*Hardware licensed under CC BY-NC-SA 4.0.*
*Contact: info@dmt-hw.com | GitHub: DvidMakesThings*

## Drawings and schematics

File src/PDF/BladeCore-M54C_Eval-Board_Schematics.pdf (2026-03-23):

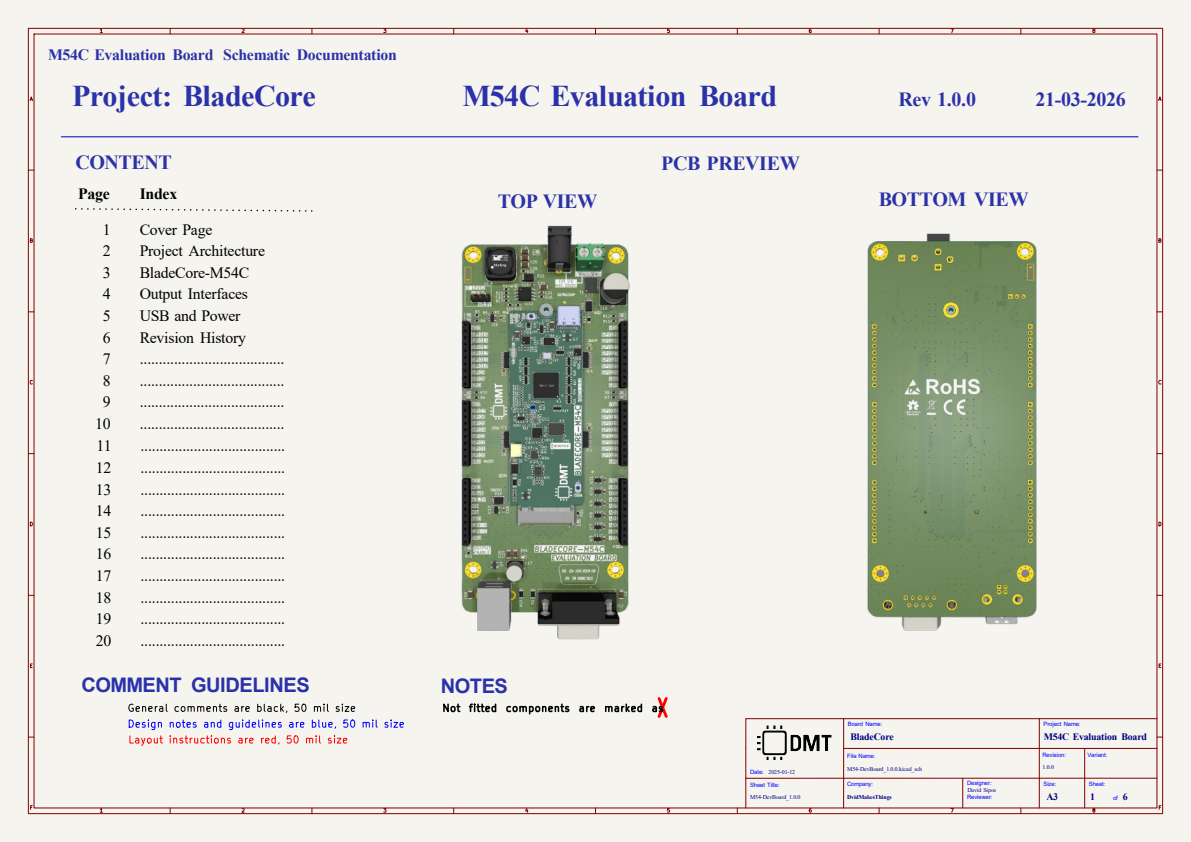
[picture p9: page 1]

M54C Evaluation Board Schematic Documentation
Project: BladeCore

Design notes and guidelines are blue, 50 mil size
Layout instructions are red, 50 mil size

File Name: Sheet Title: M54-DevBoard_1.0.0

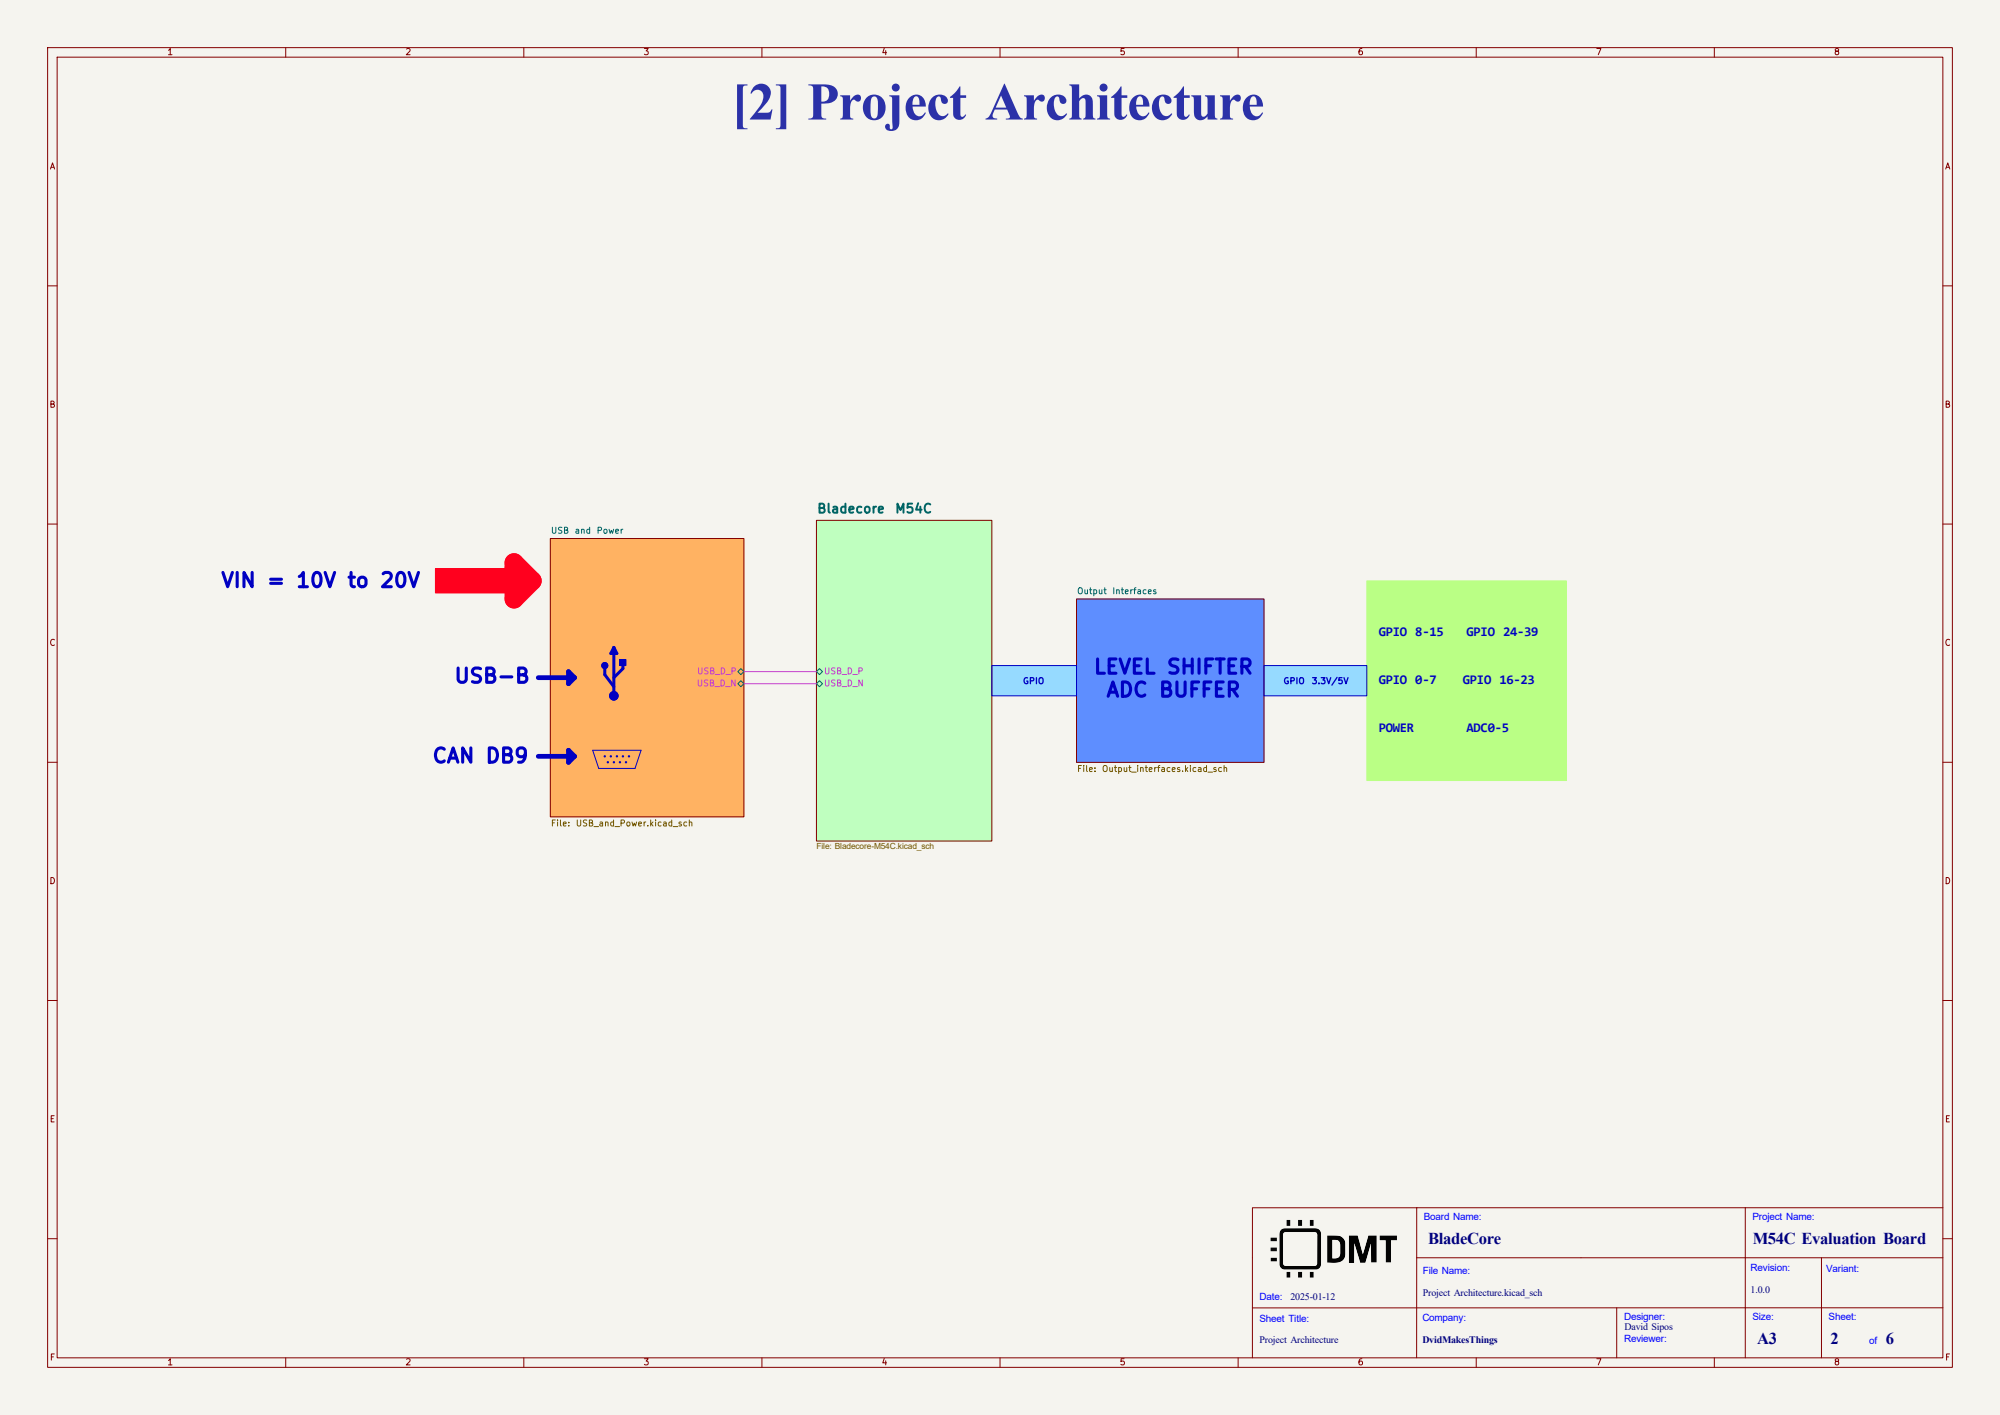
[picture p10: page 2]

Output Interfaces File: Output_interfaces.kicad_sch USB_D_P USB_D_N Bladecore M54C

File Name: Sheet Title: Project Architecture

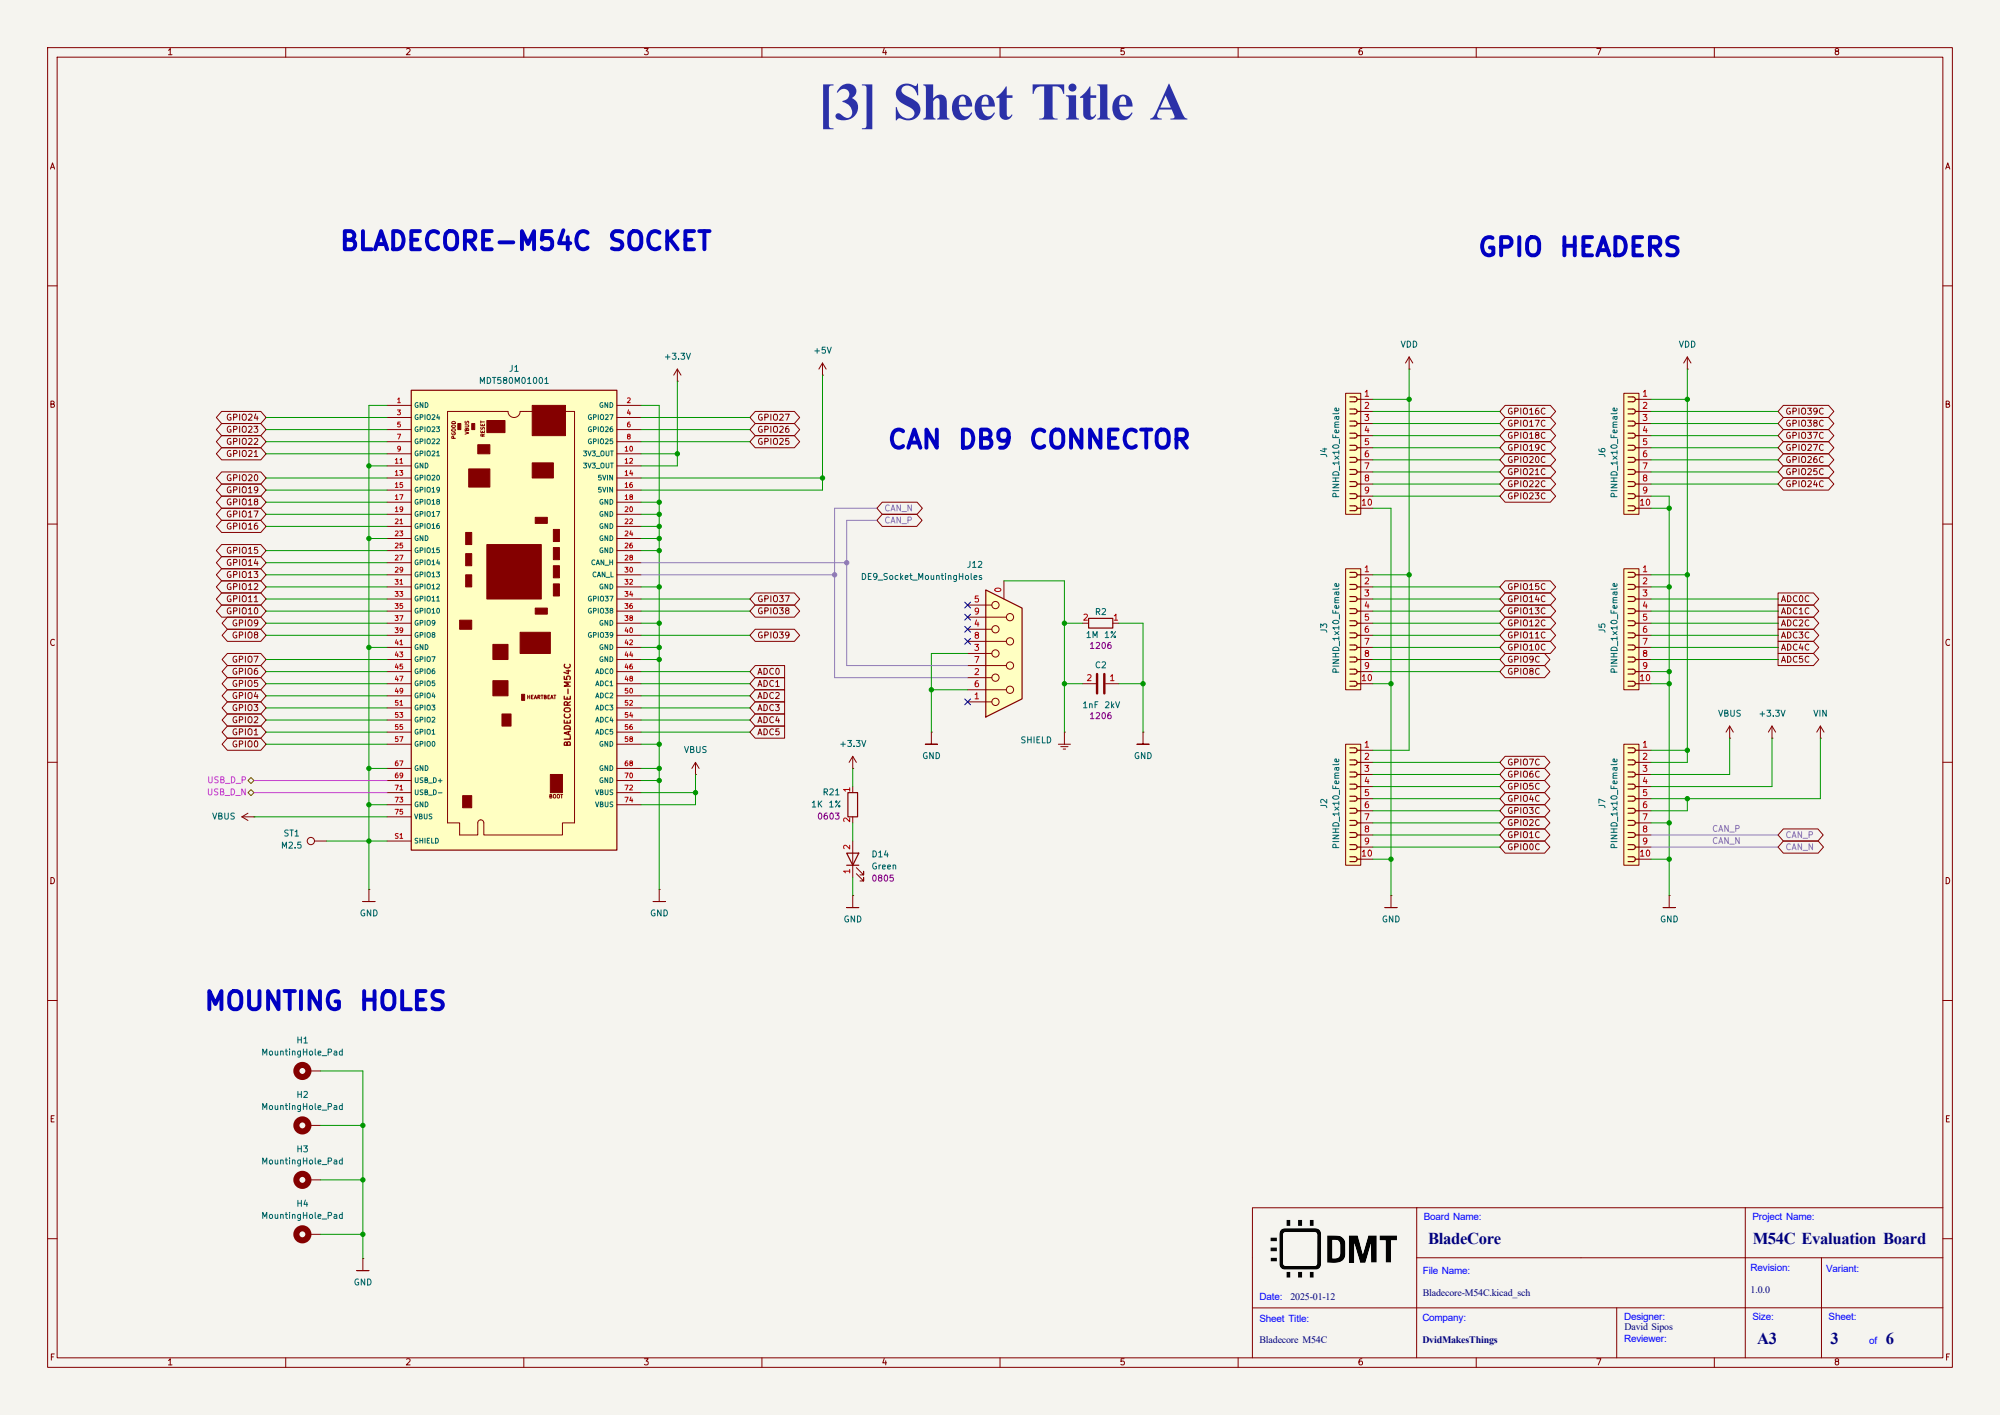
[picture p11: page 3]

1 2 D14 Green 0805 GND +3.3V GND +3.3V VIN

File Name: Sheet Title: Bladecore M54C

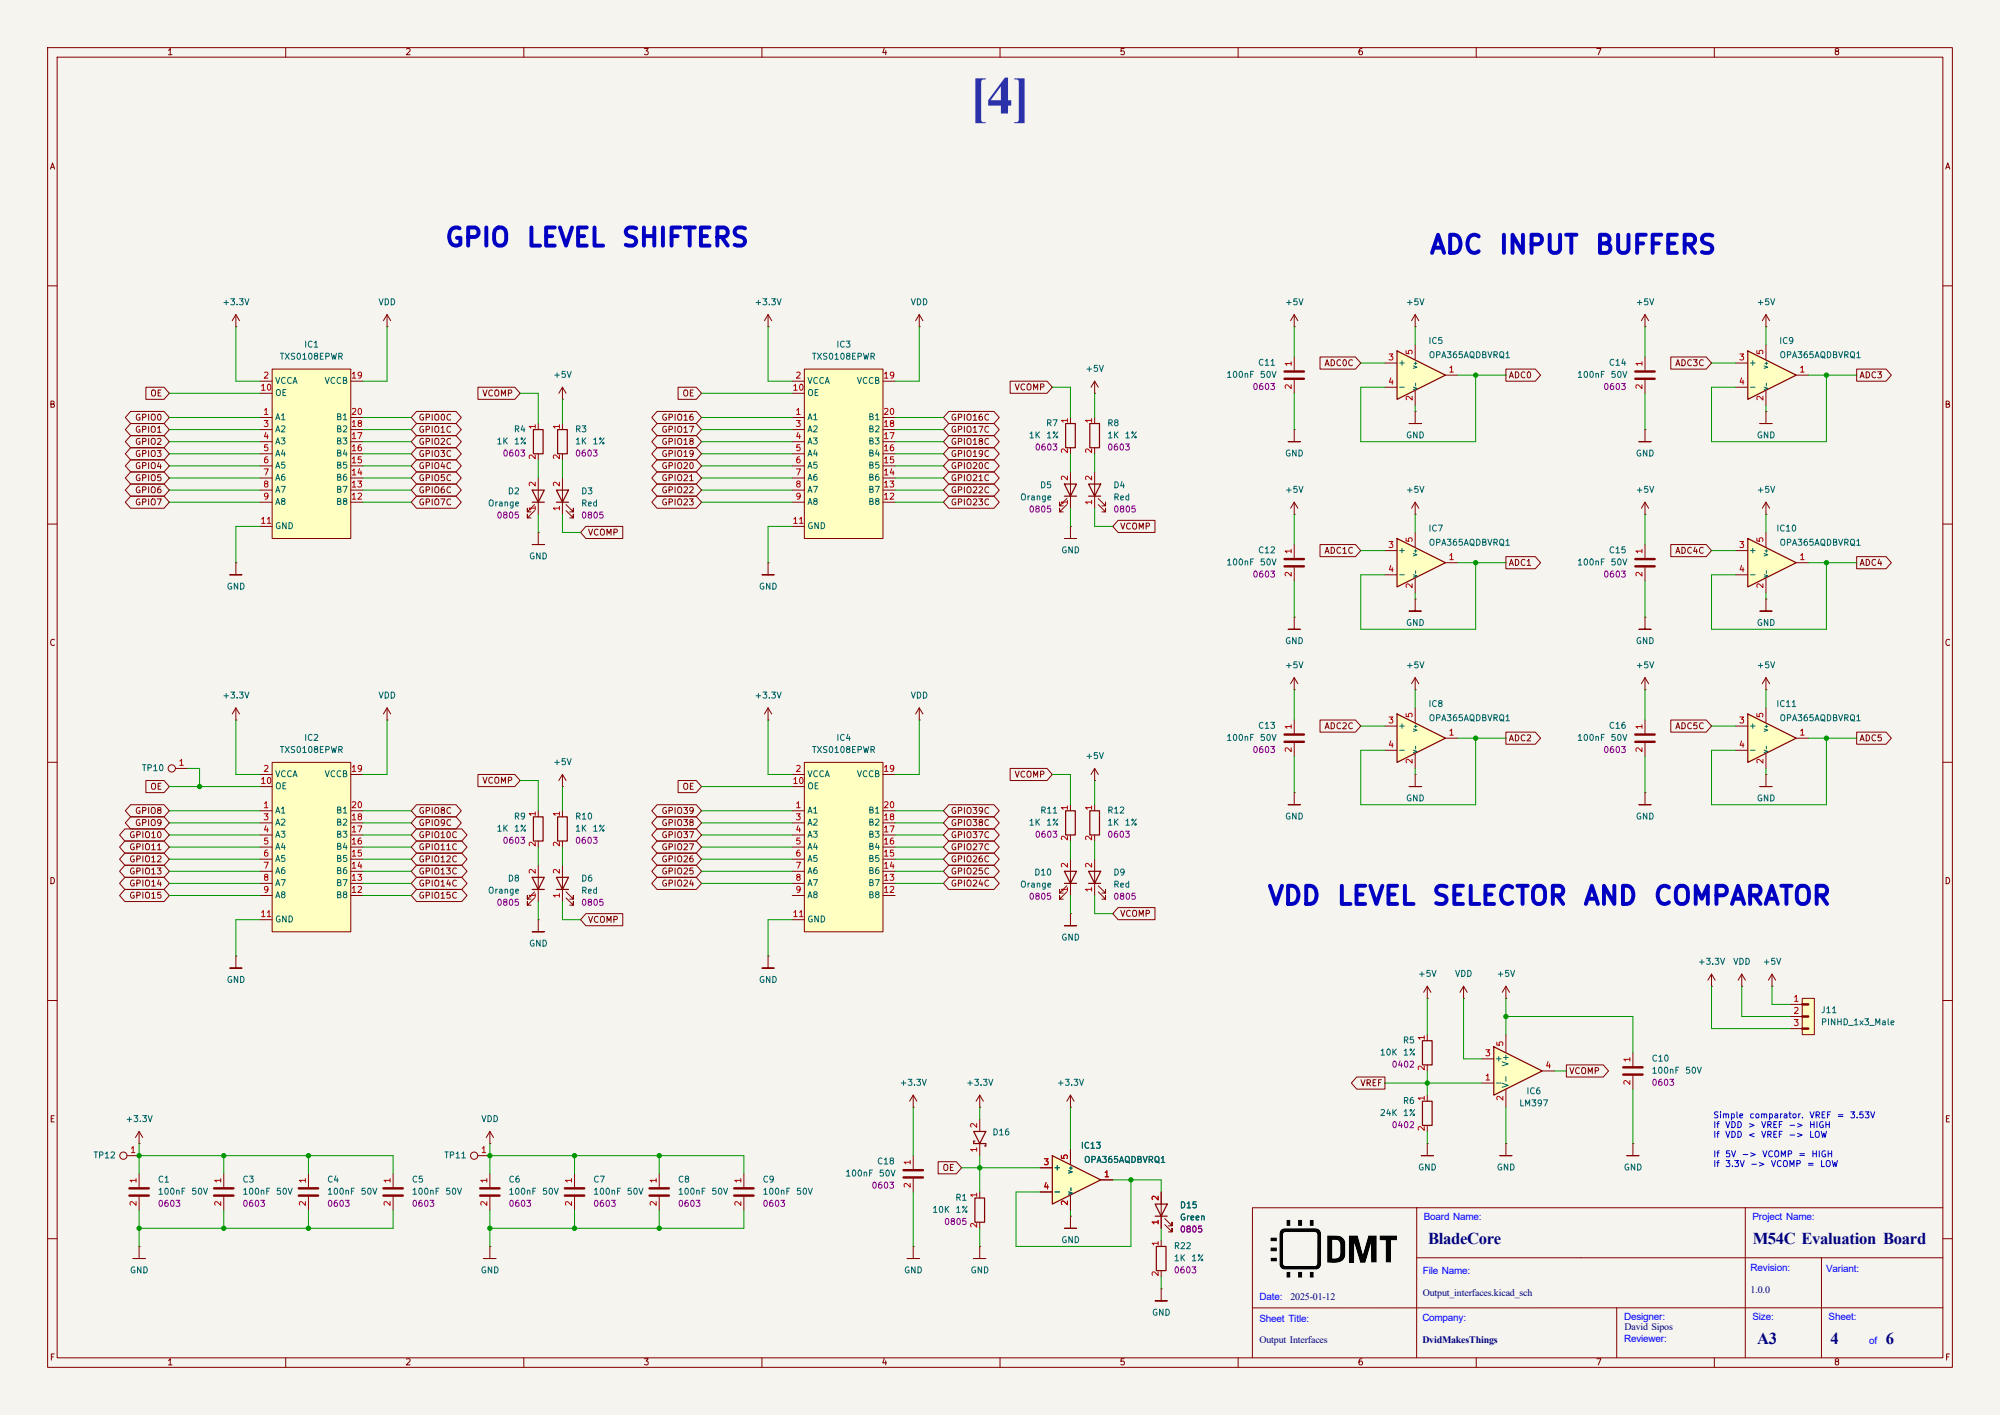
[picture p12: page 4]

VDD LEVEL SELECTOR AND COMPARATOR

Simple comparator. VREF = 3.53V
If VDD > VREF -> HIGH
If VDD < VREF -> LOW

File Name: Sheet Title: Output Interfaces

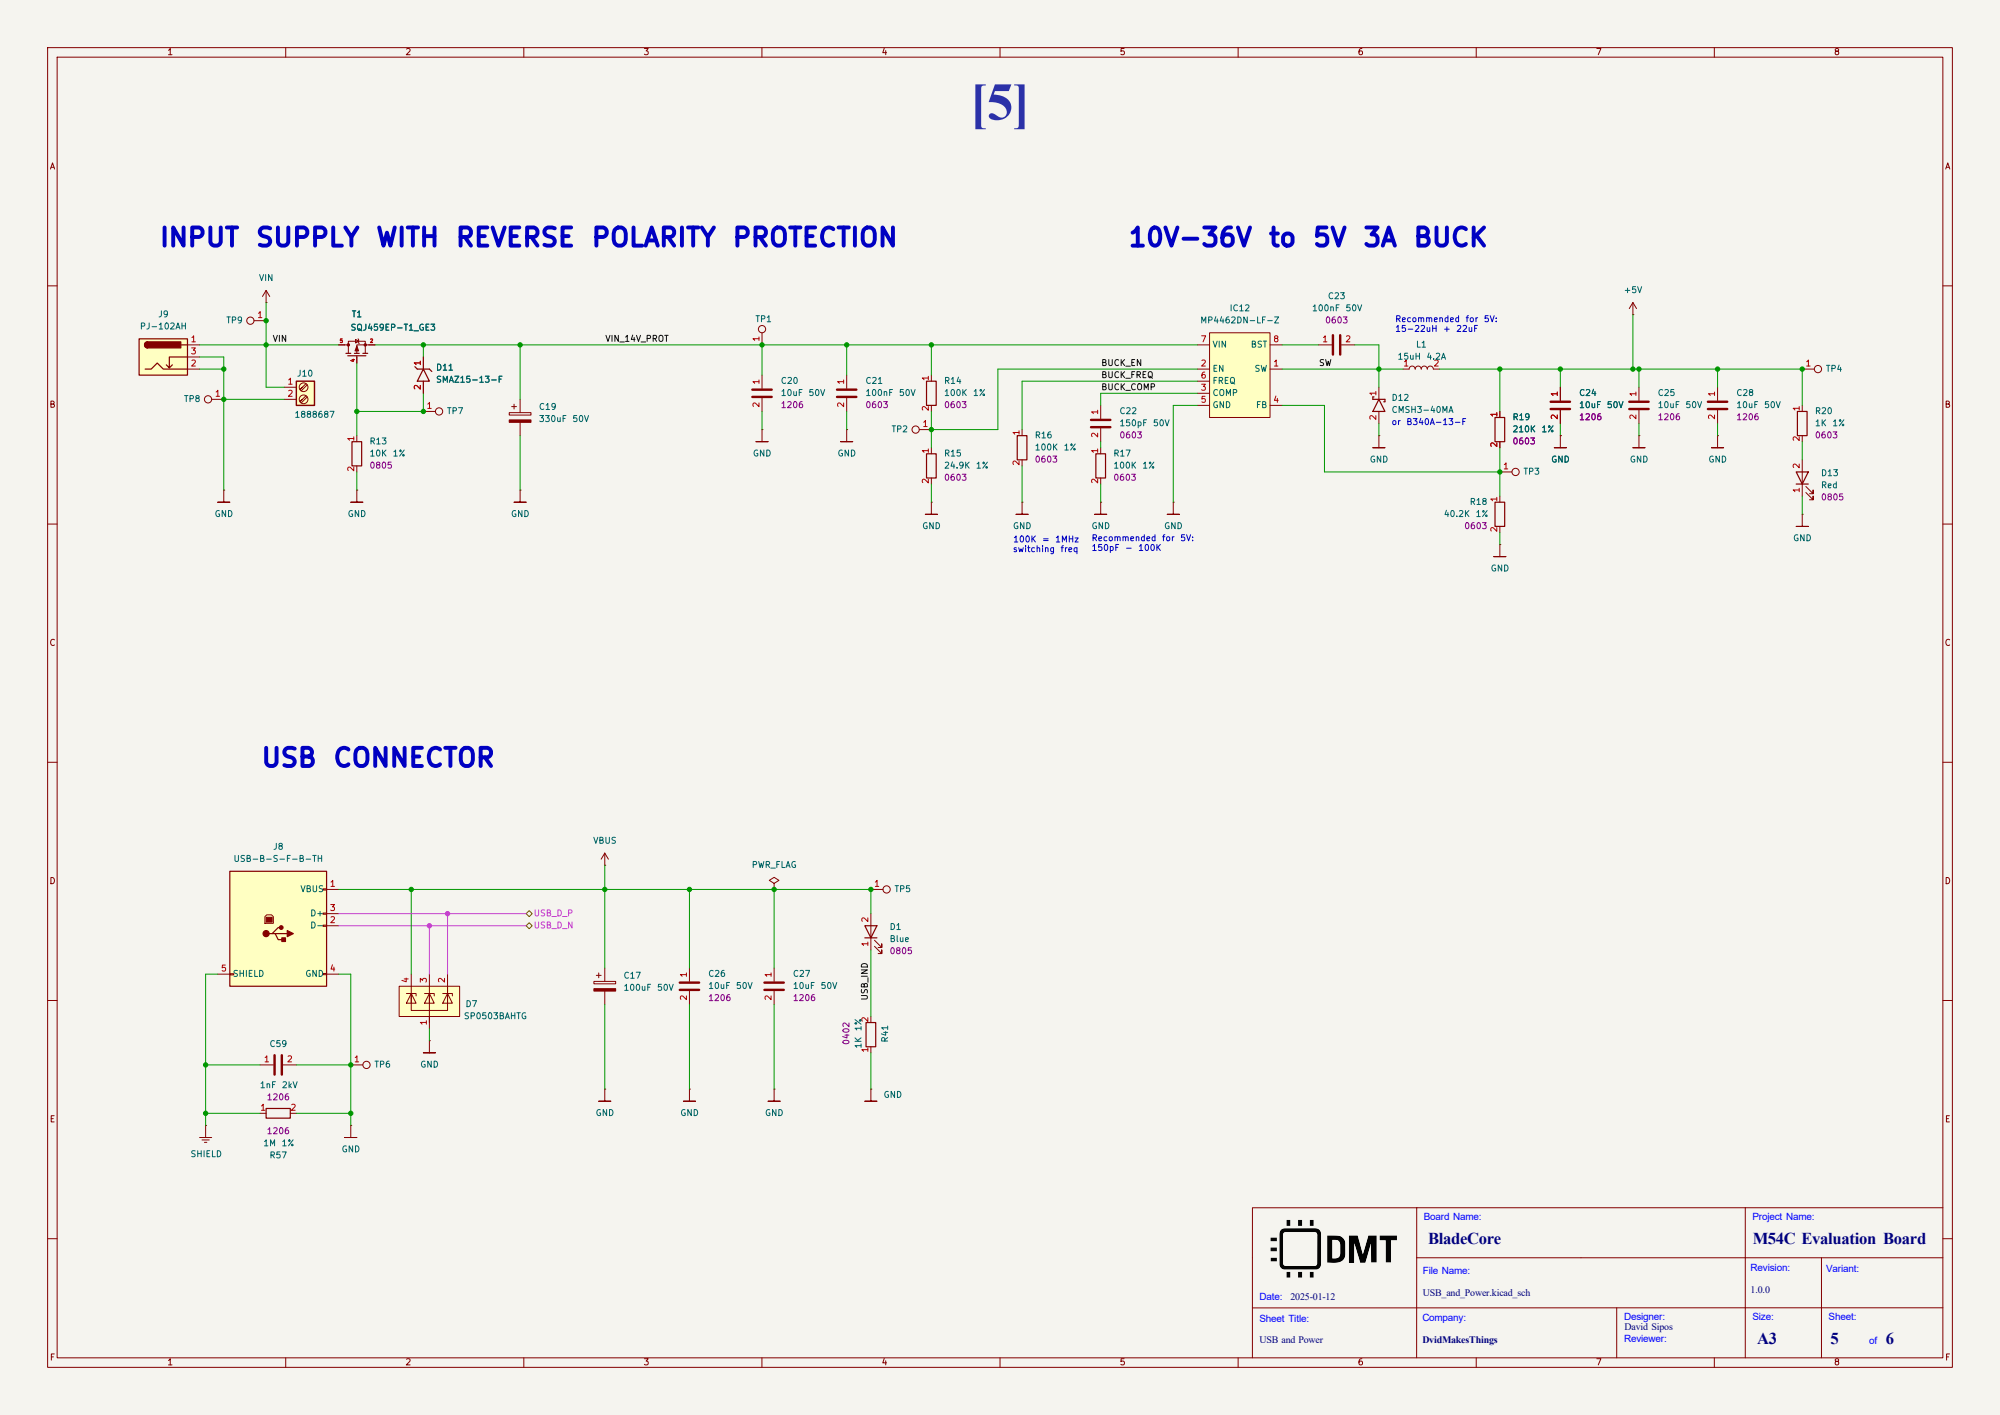
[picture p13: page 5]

INPUT SUPPLY WITH REVERSE POLARITY PROTECTION

Recommended for 5V: 15-22uH + 22uF 10V-36V to 5V 3A BUCK

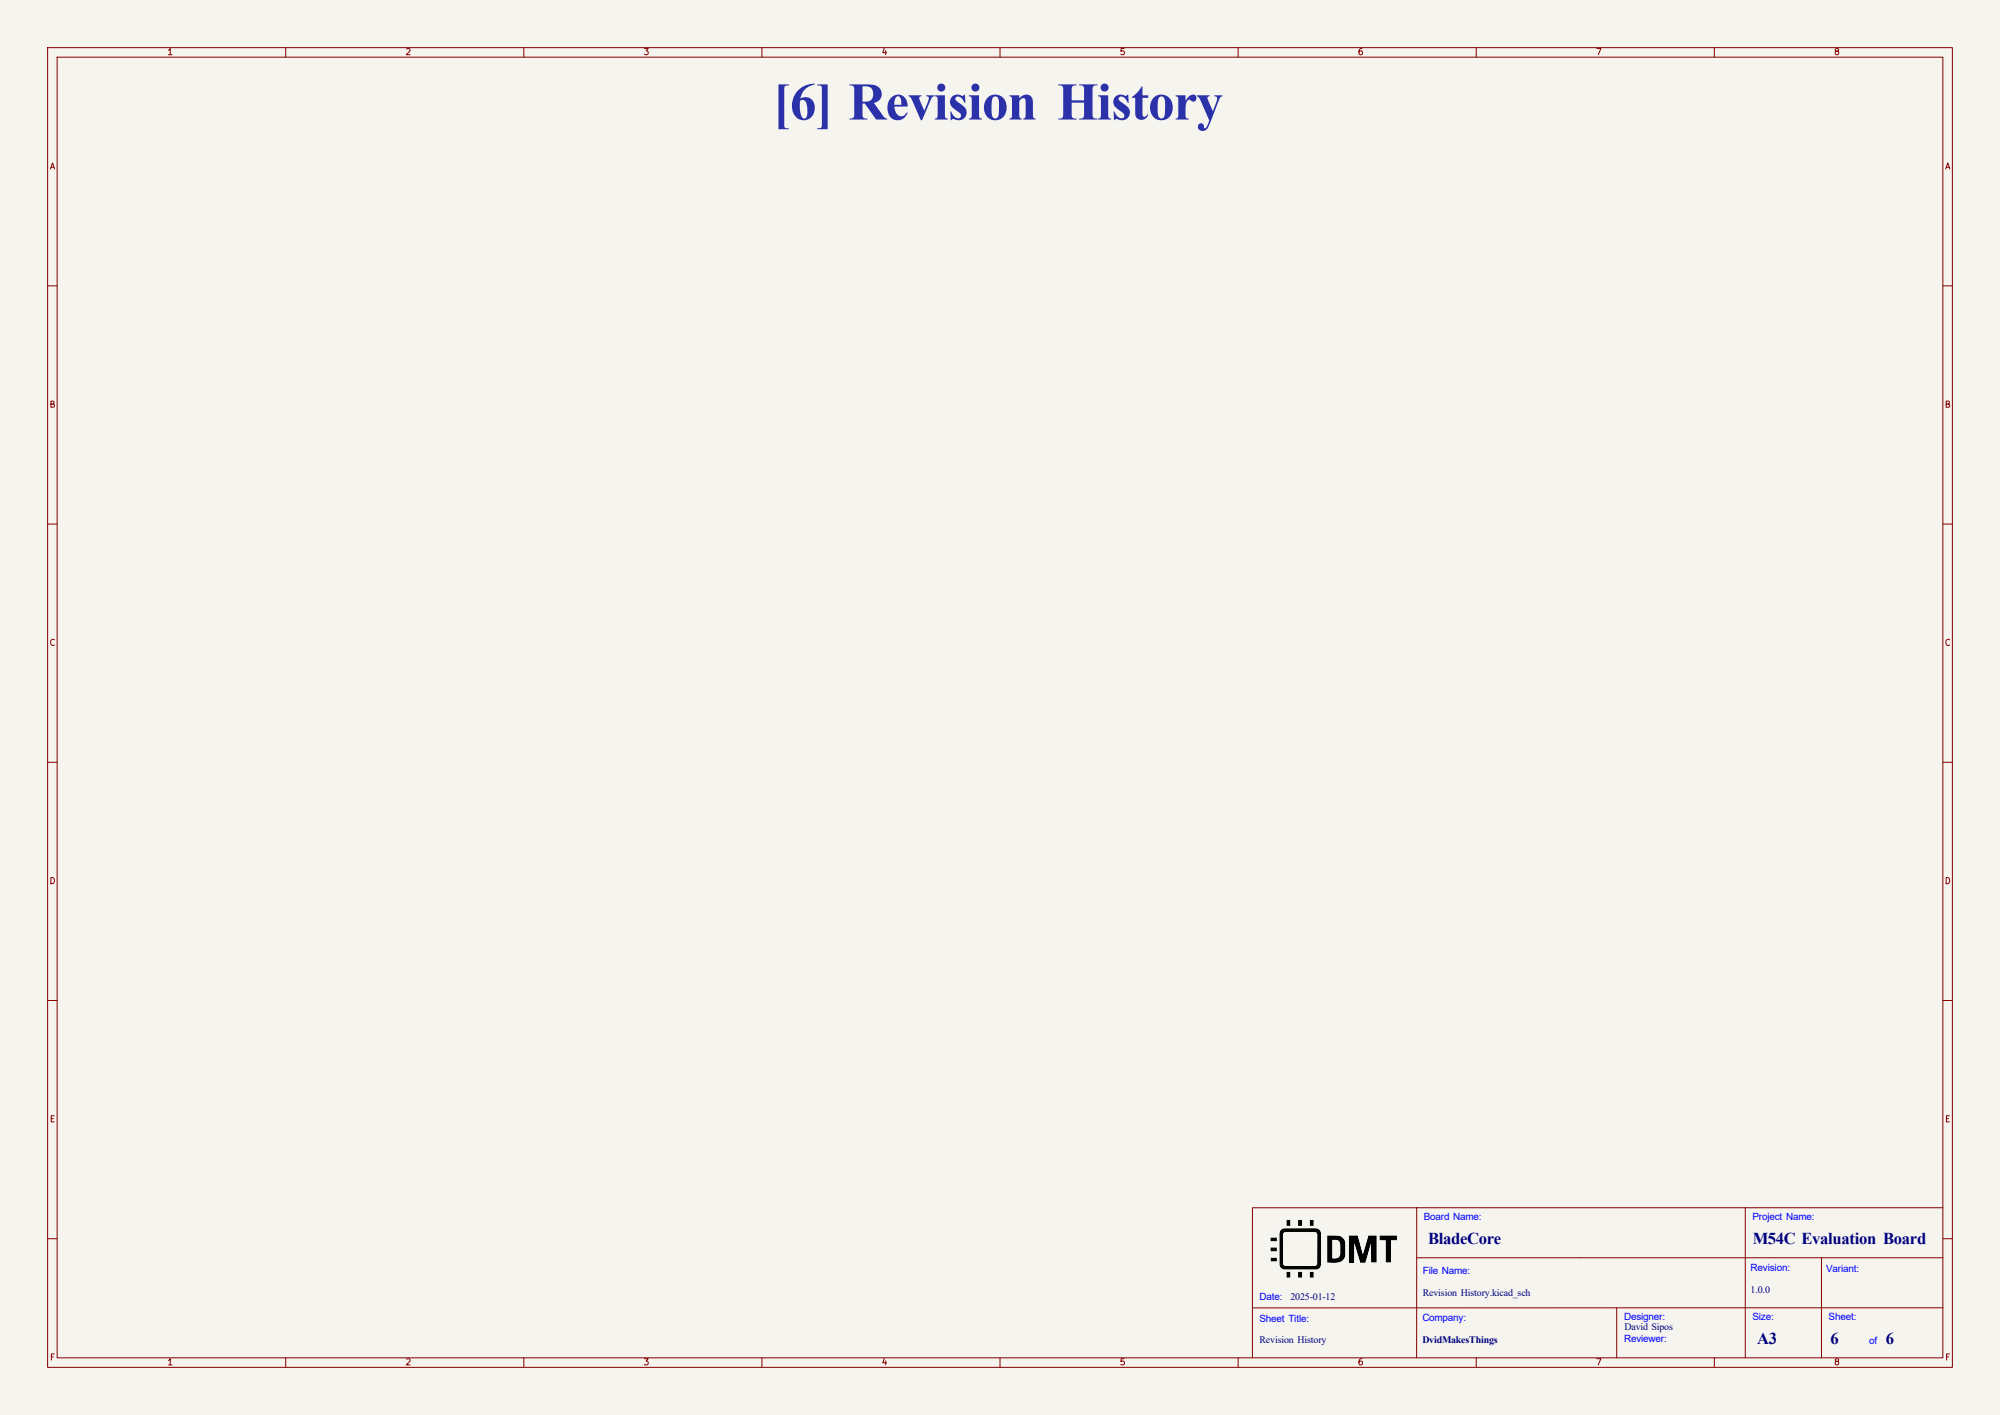
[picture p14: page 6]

File Name: Sheet Title: Revision History

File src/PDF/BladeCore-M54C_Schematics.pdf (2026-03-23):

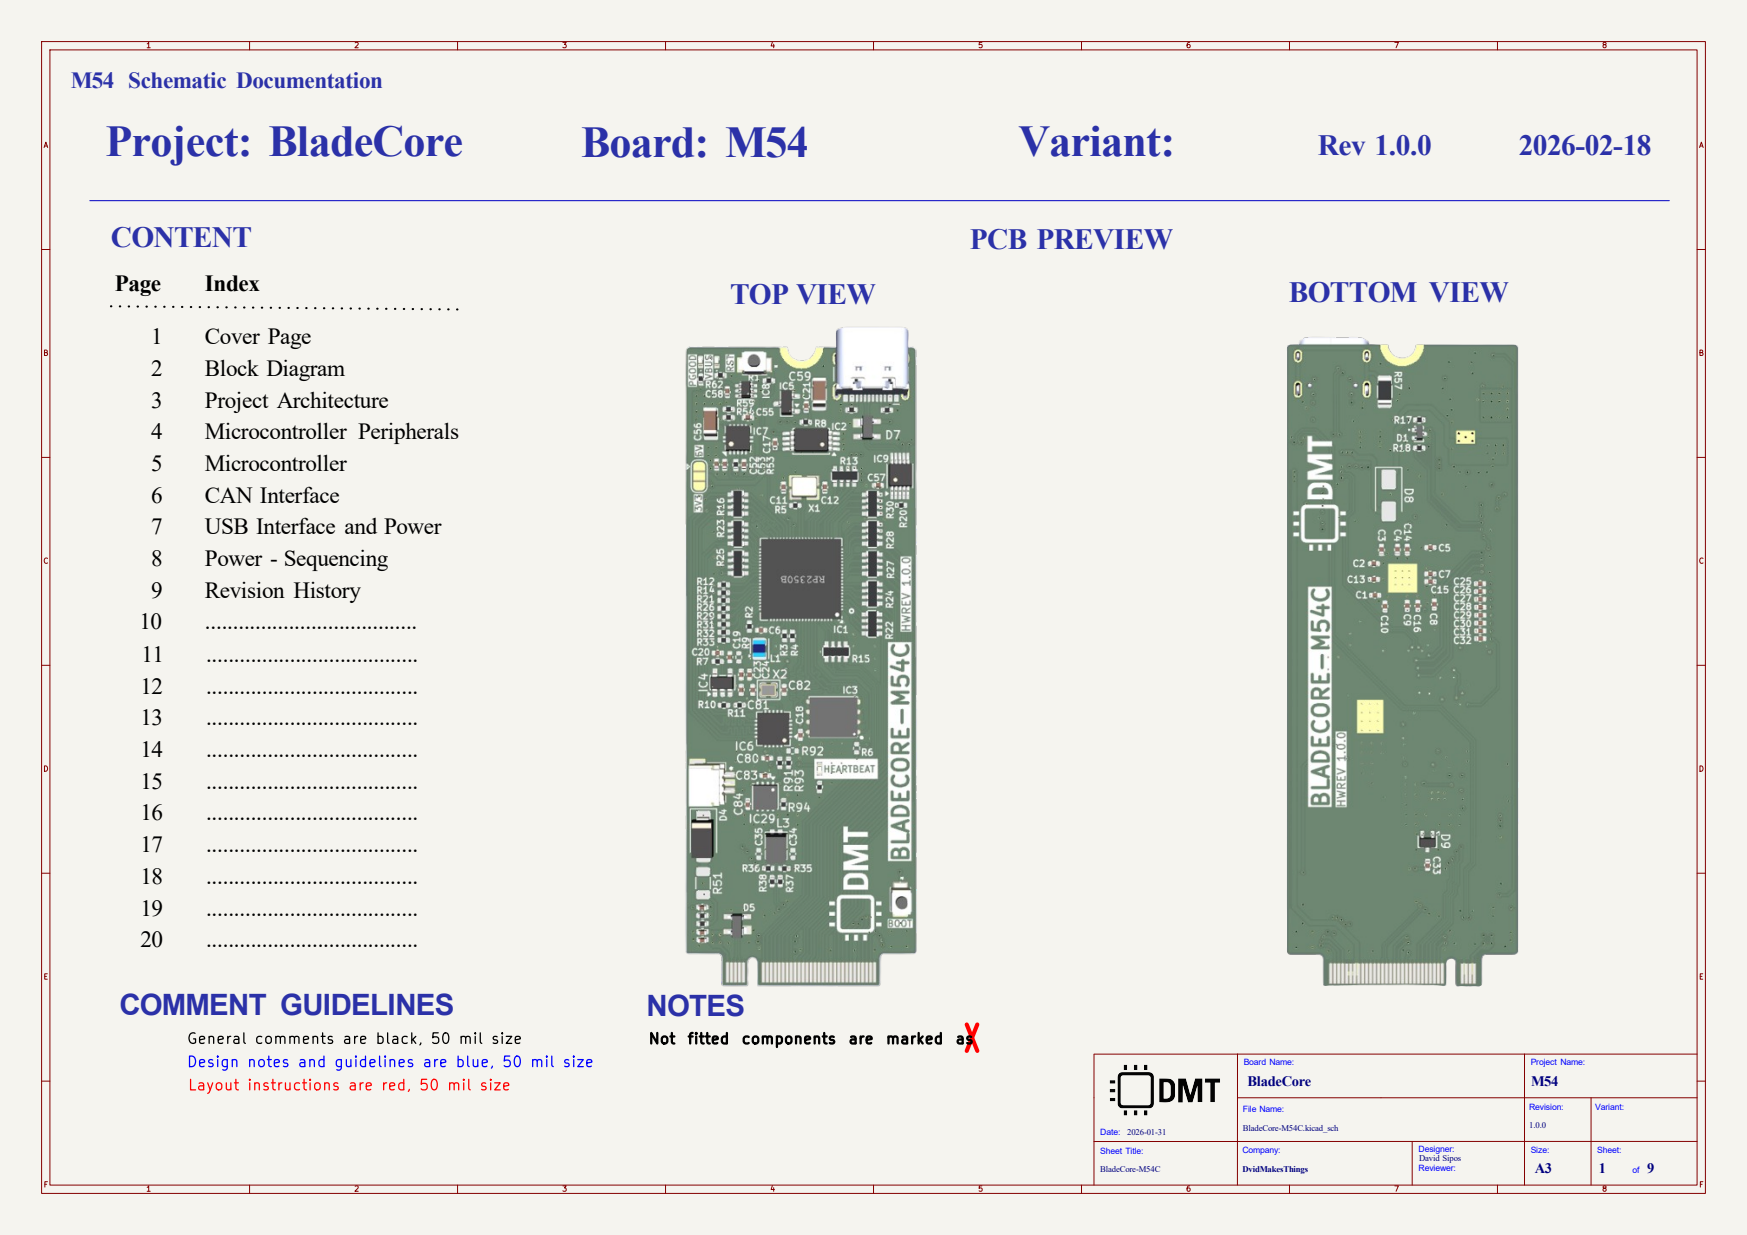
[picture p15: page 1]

File Name: Sheet Title: BladeCore-M54C M54 Schematic Documentation

Not fitted components are marked as

Design notes and guidelines are blue, 50 mil size

Layout instructions are red, 50 mil size

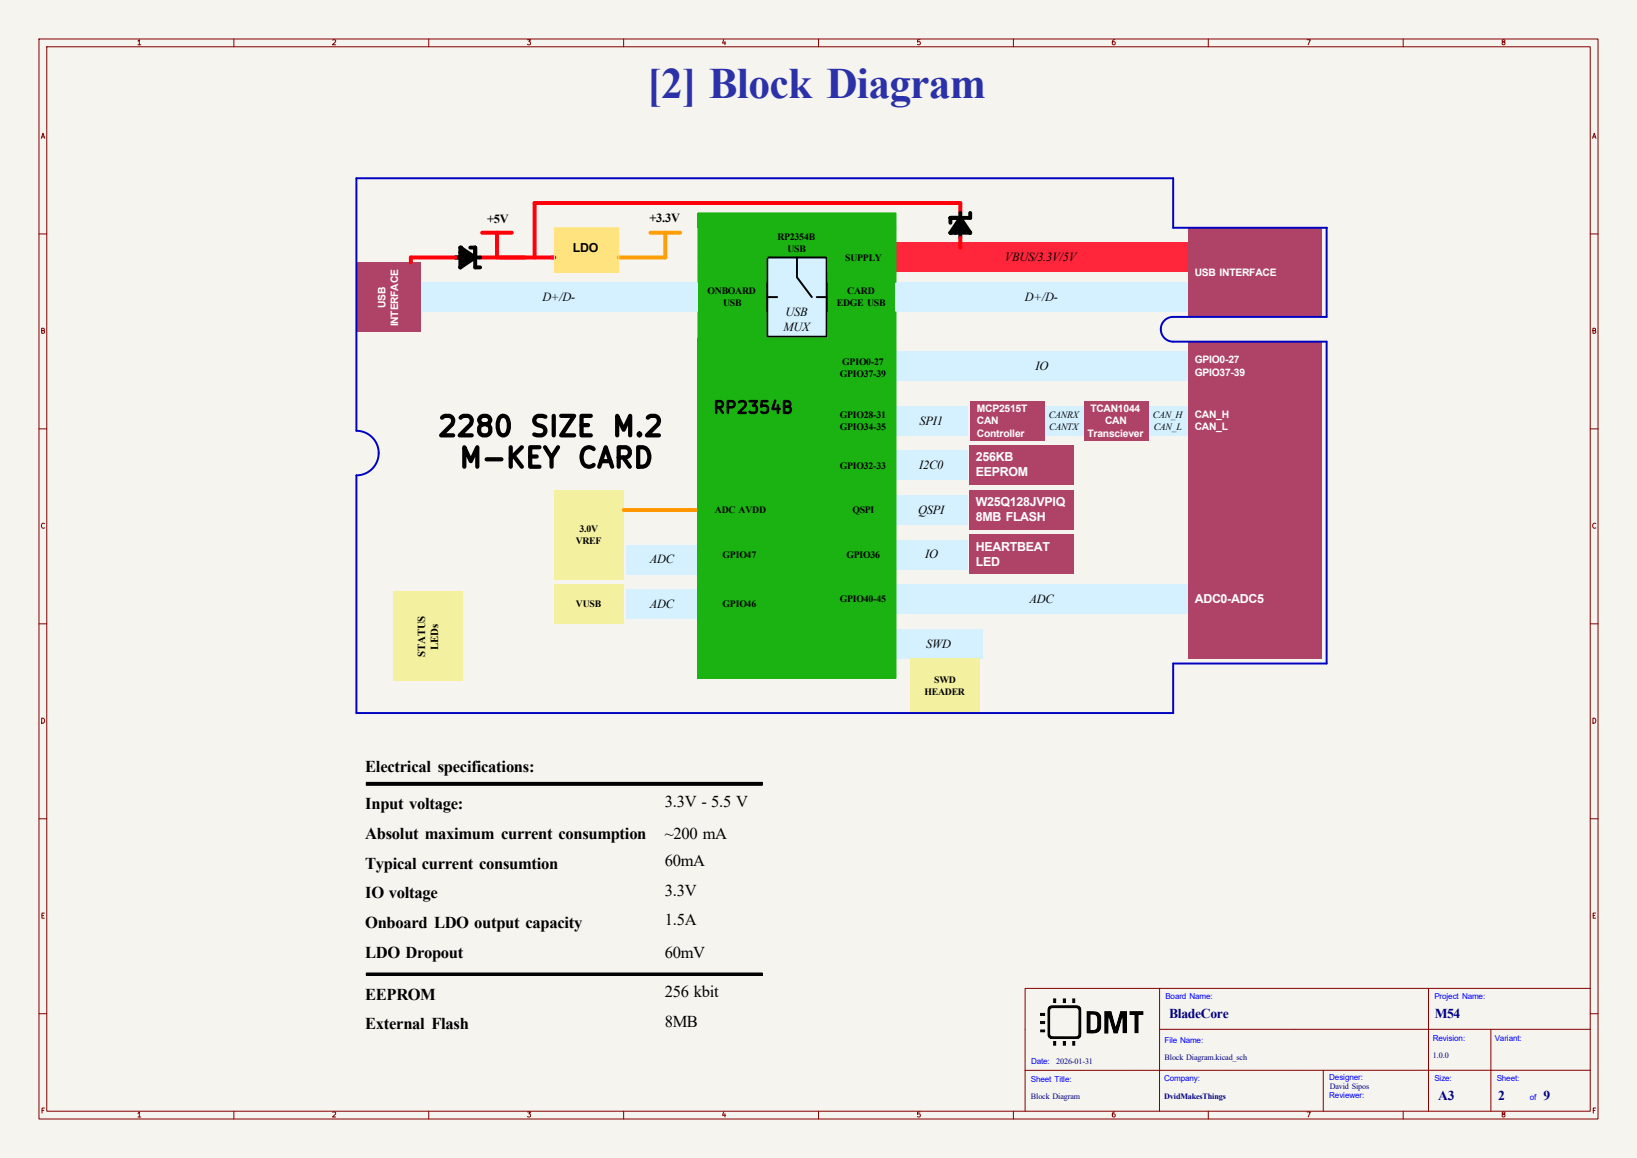
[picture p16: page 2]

~200 mA STATUS LEDs USB INTERFACE

Input voltage:
Absolut maximum current consumption
IO voltage
Onboard LDO output capacity
LDO Dropout

File Name: Sheet Title: Block Diagram

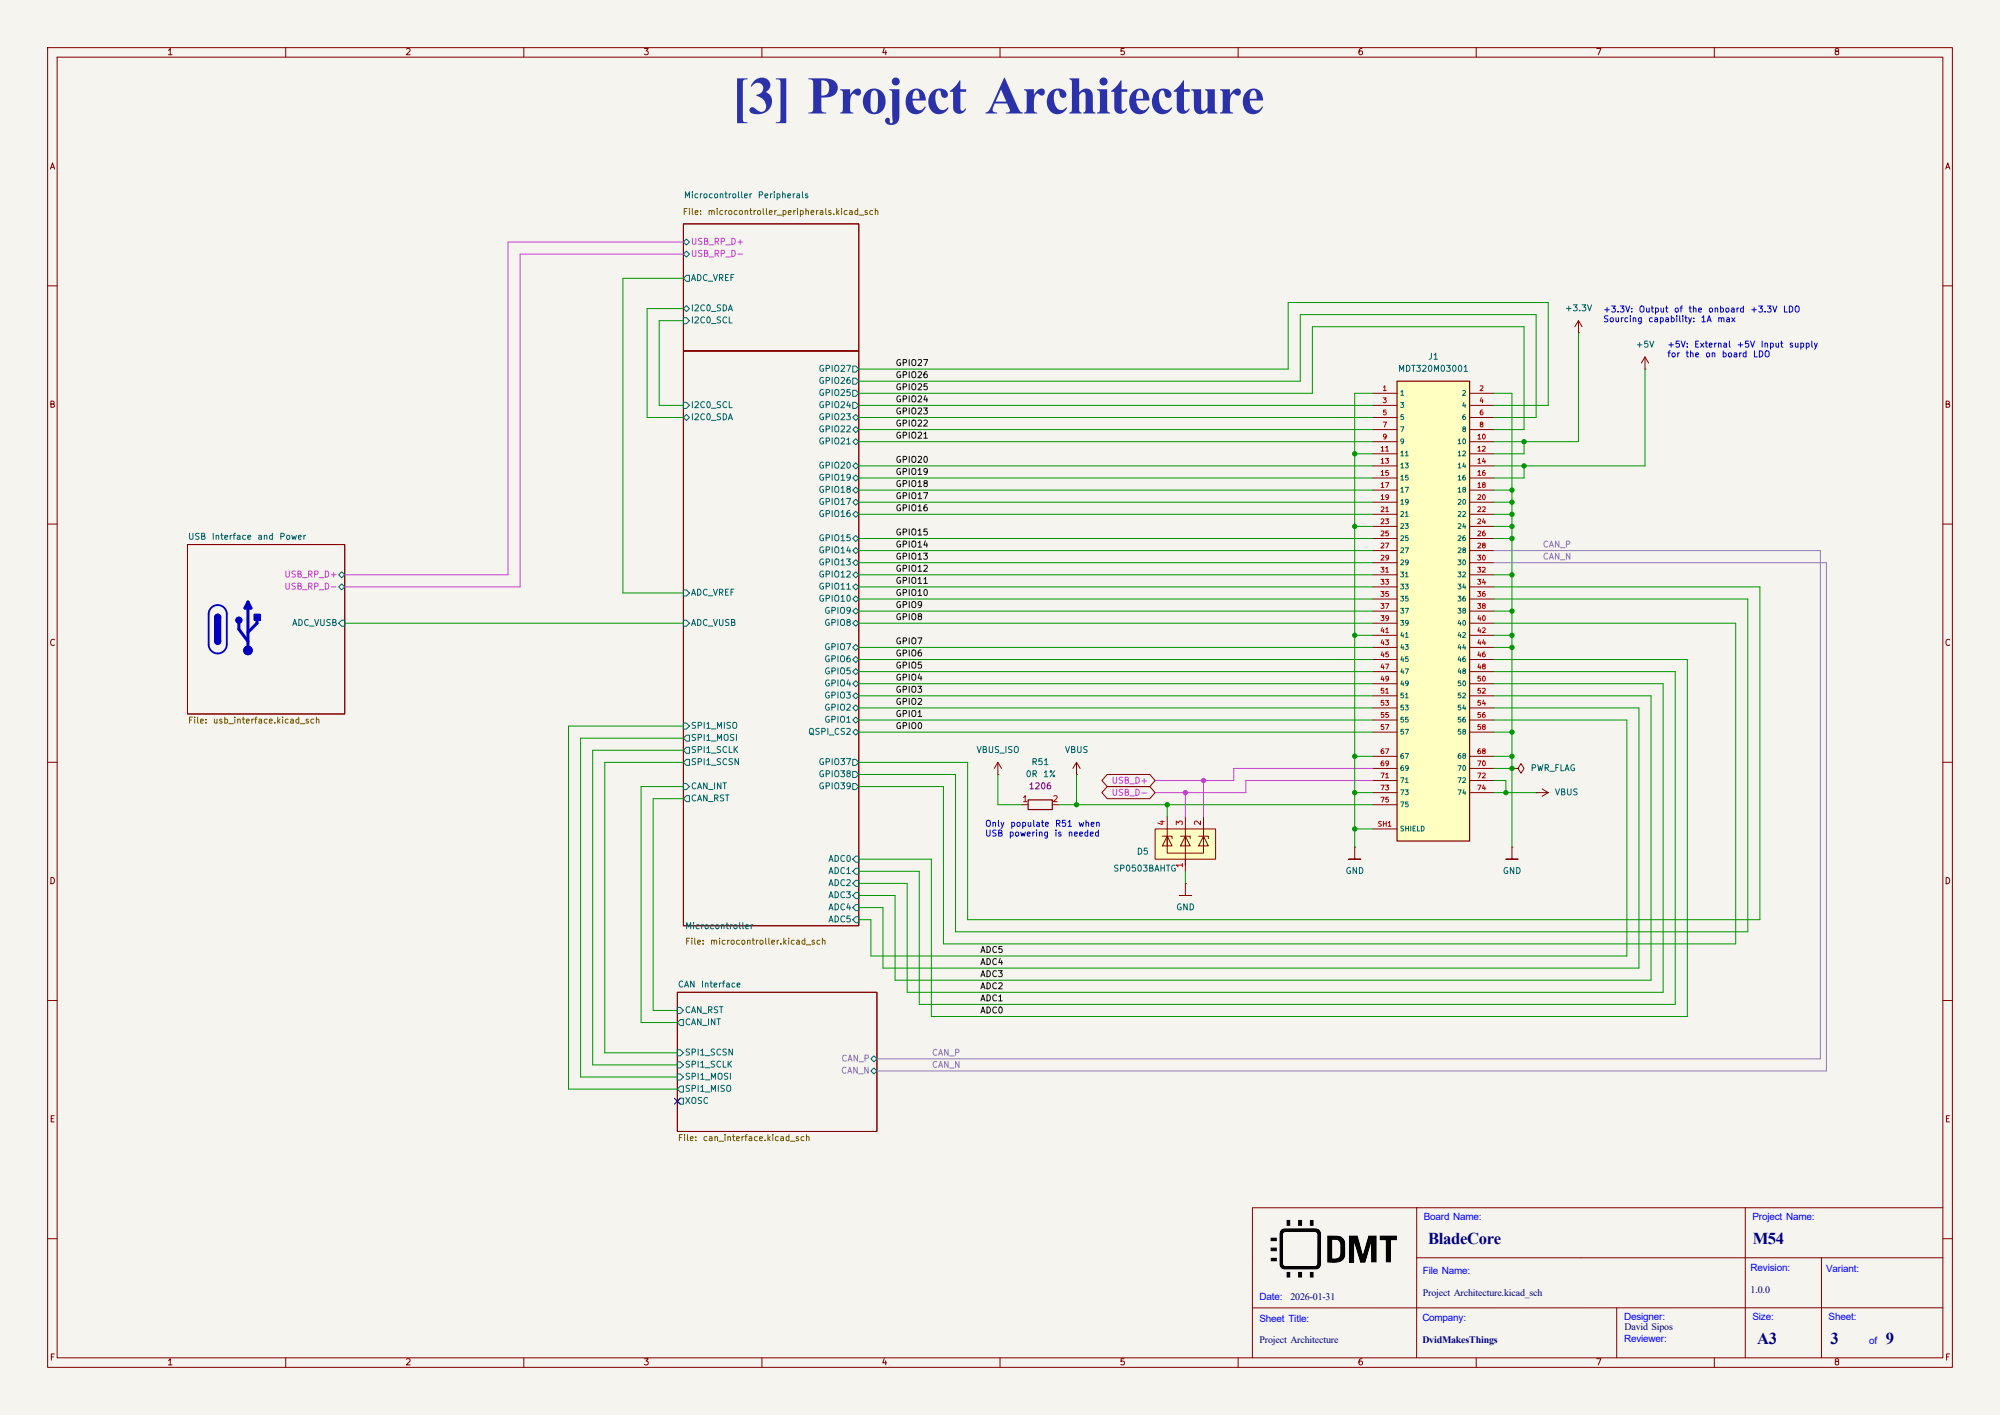
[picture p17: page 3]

Sourcing capability: 1A max Only populate R51 when
GPIO2 GPIO21 GPIO20 GPIO26 GPIO6

+3.3V: Output of the onboard +3.3V LDO

for the on board LDO

ADC3
ADC2

File Name: Sheet Title: Project Architecture SPI1_MOSI SPI1_SCLK

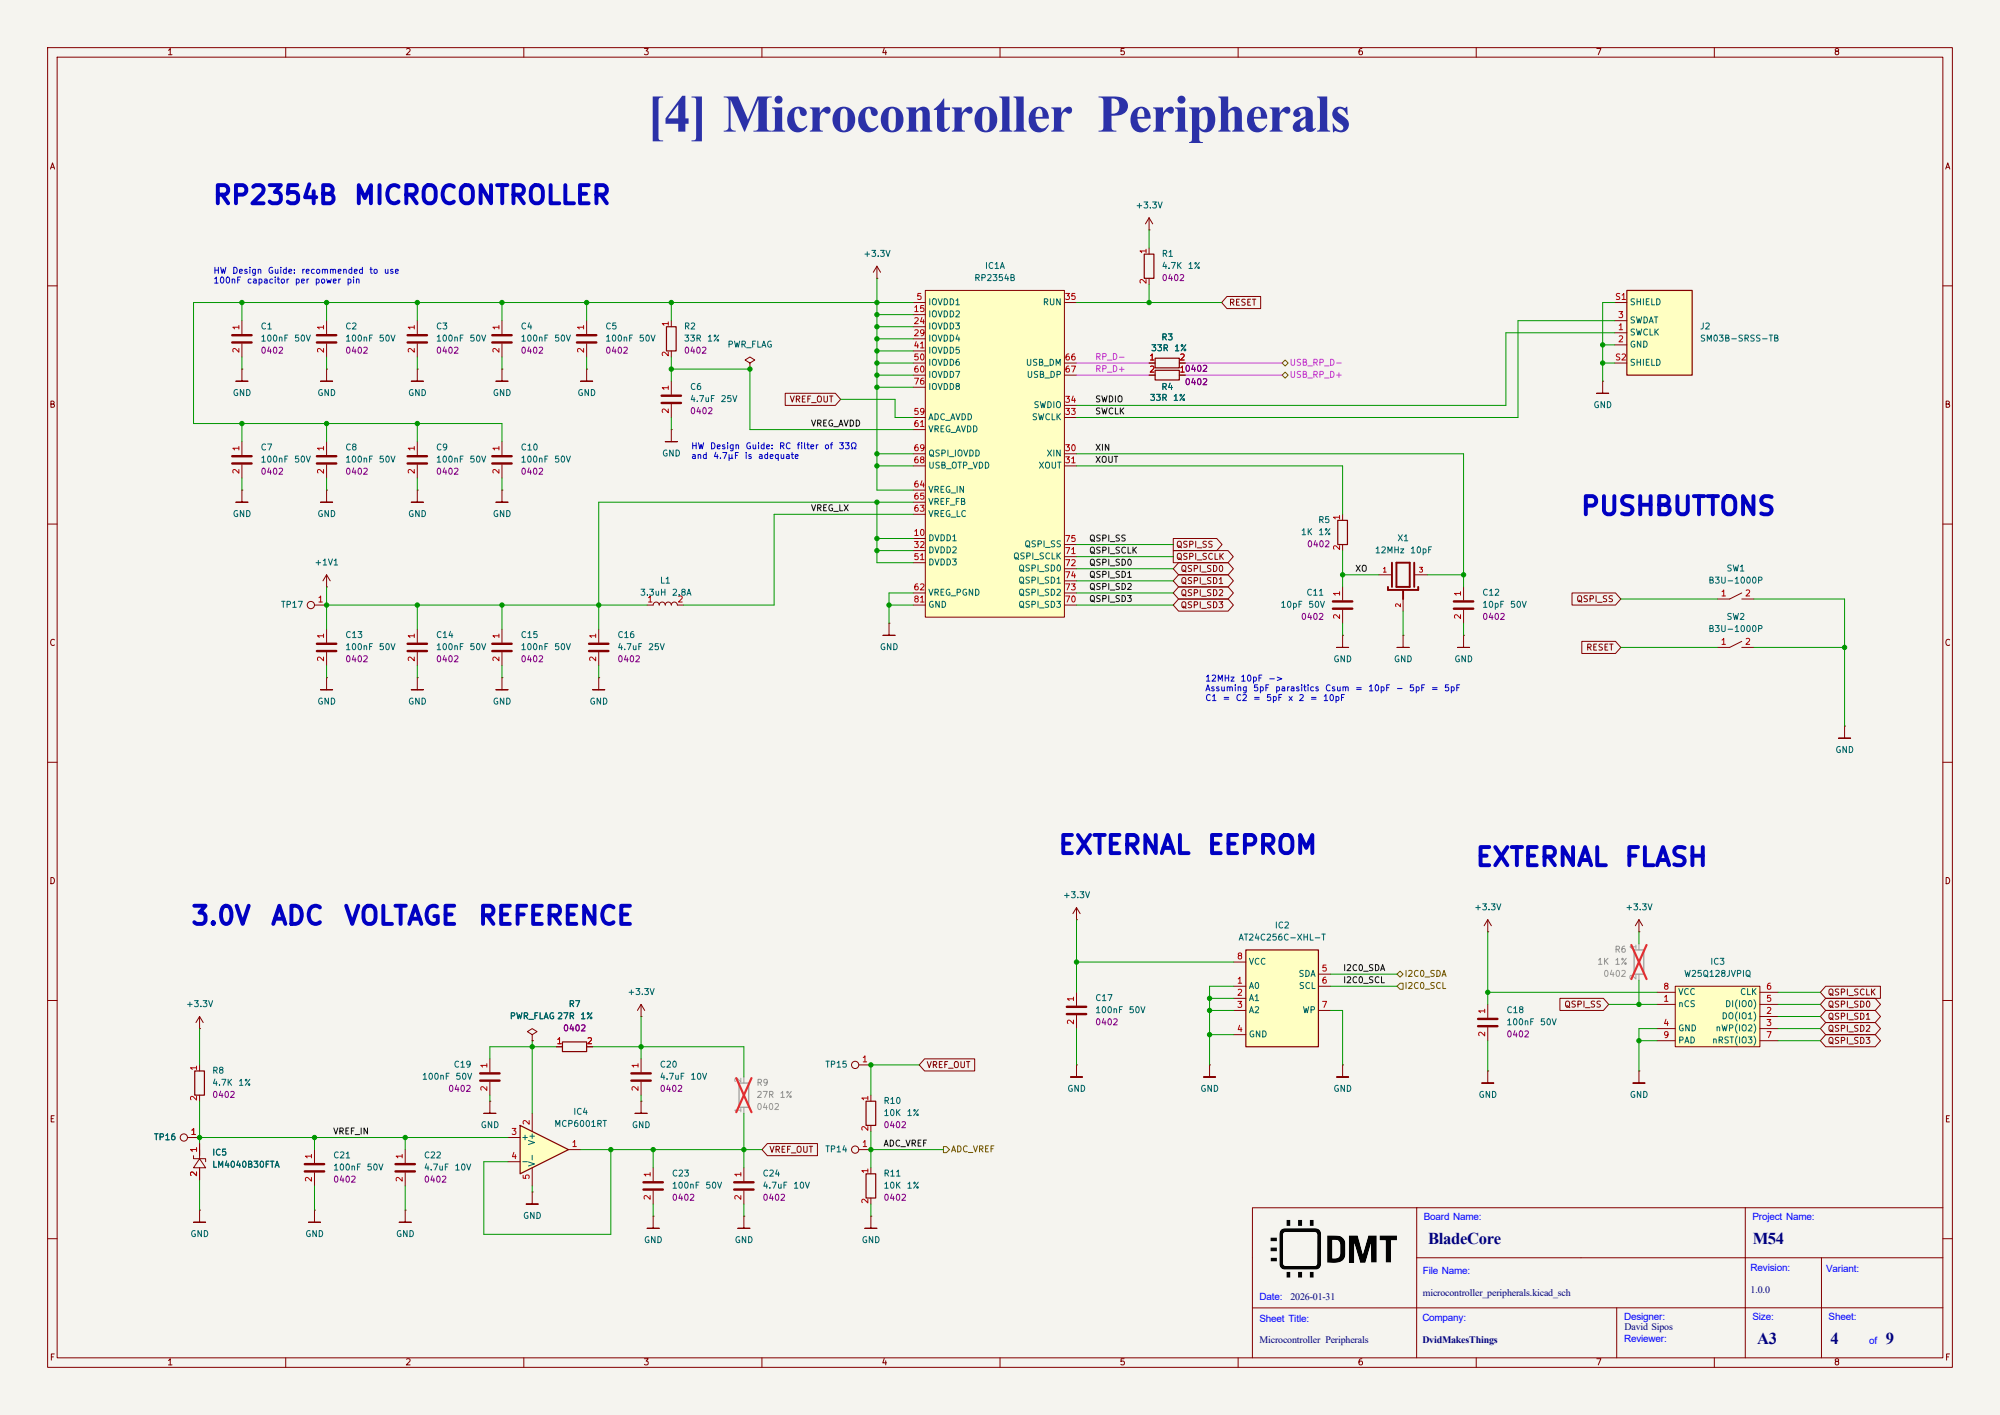
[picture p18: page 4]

HW Design Guide: recommended to use 100nF capacitor per power pin

IOVDD1 5 DVDD1 10 | SWDIO

IOVDD7 60 | RP_D+

HW Design Guide: RC filter of 33Ω

File Name: Sheet Title: Microcontroller Peripherals

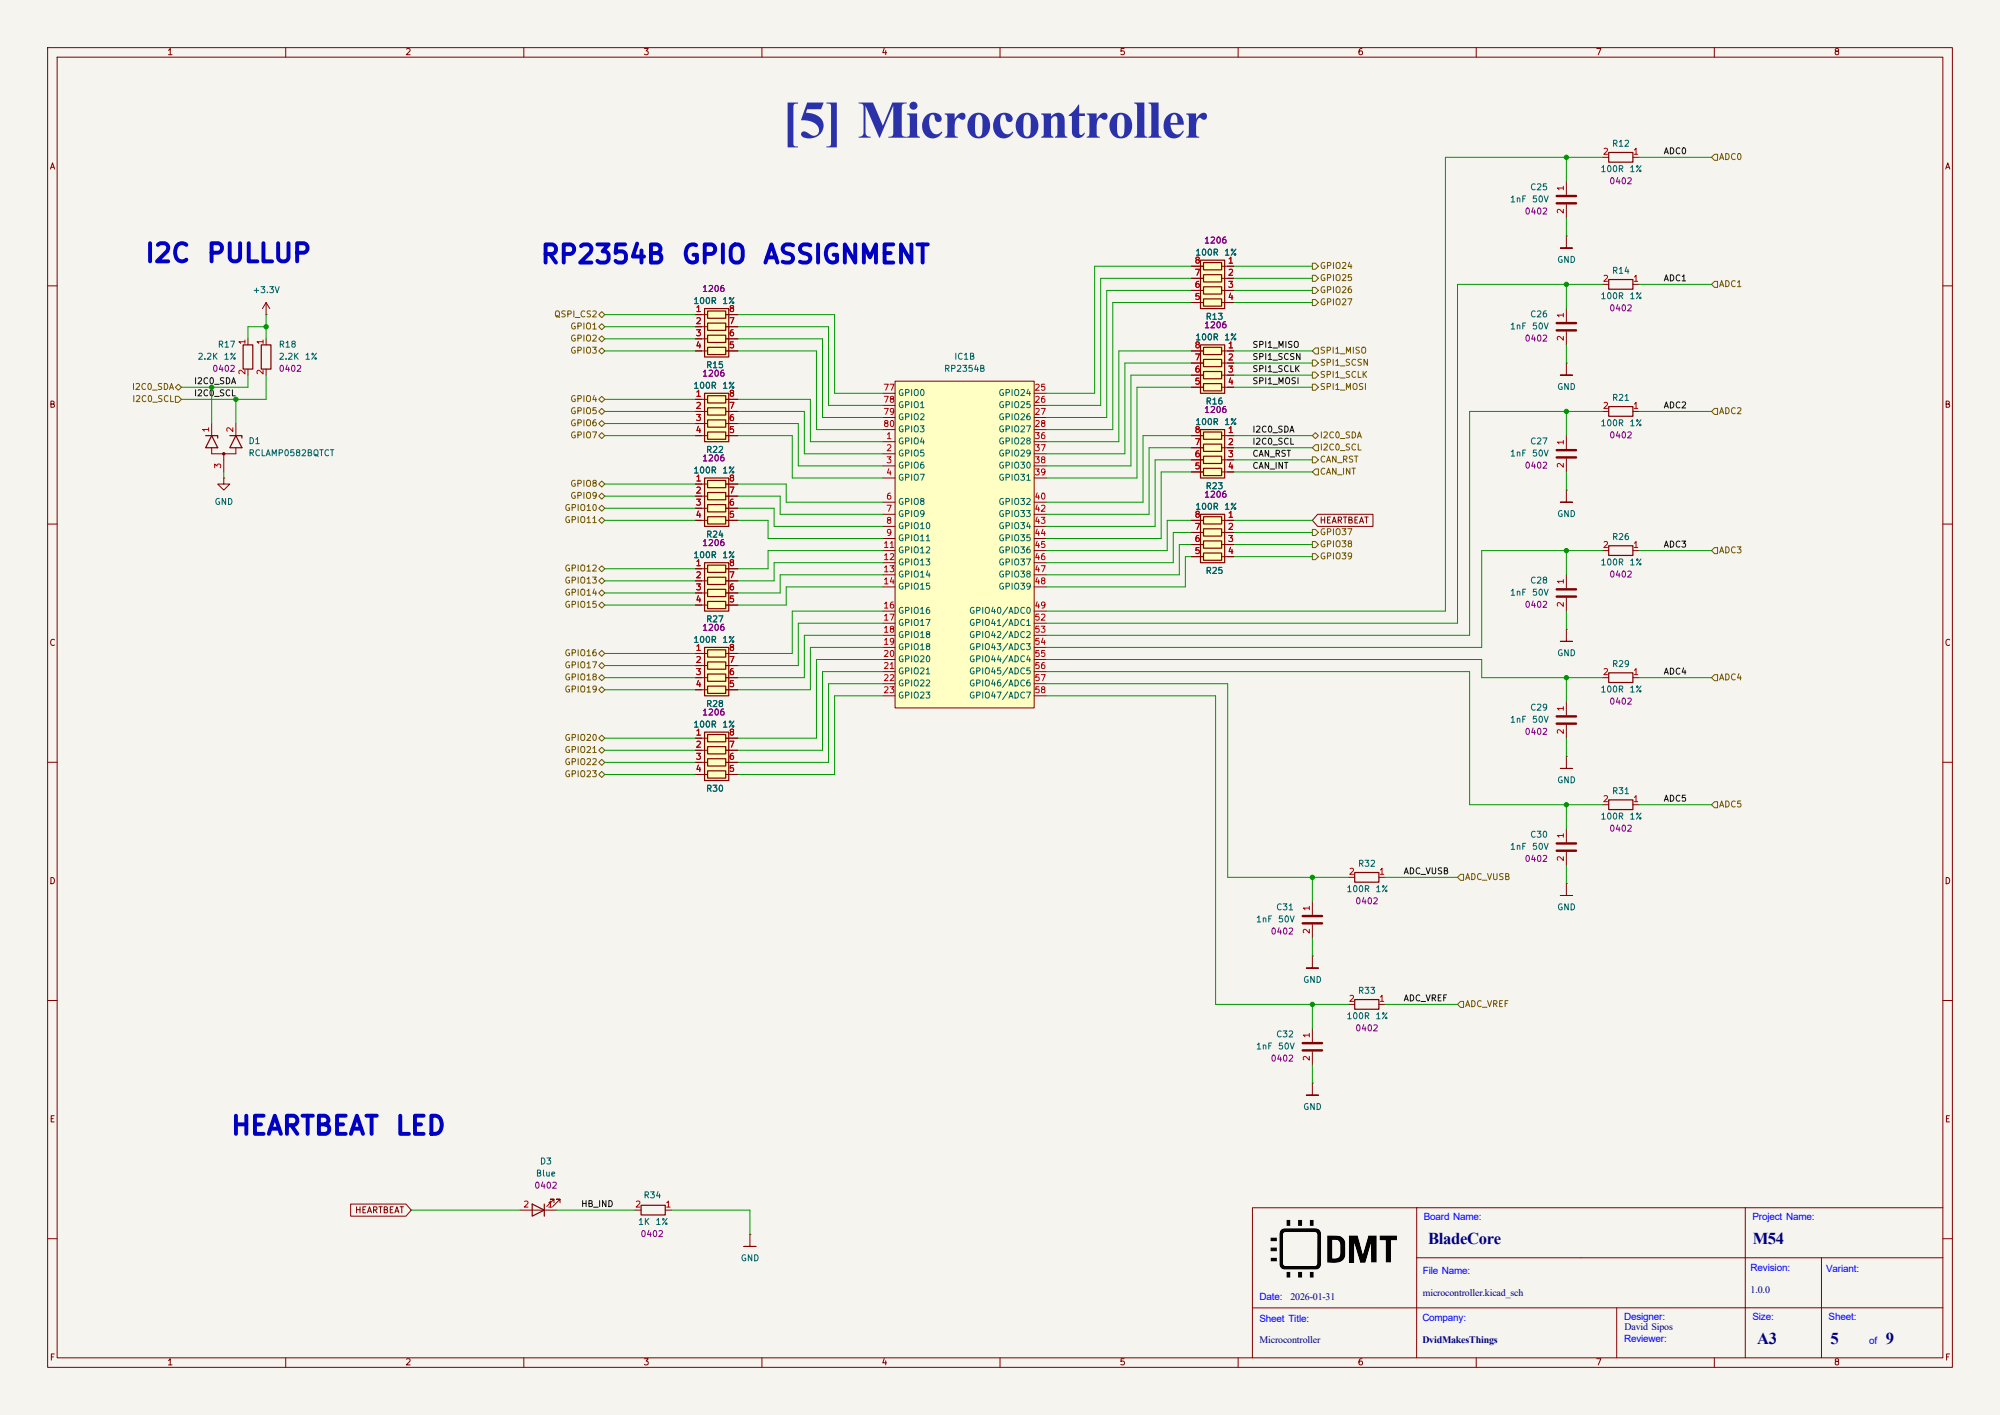
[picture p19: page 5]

File Name: Sheet Title: Microcontroller

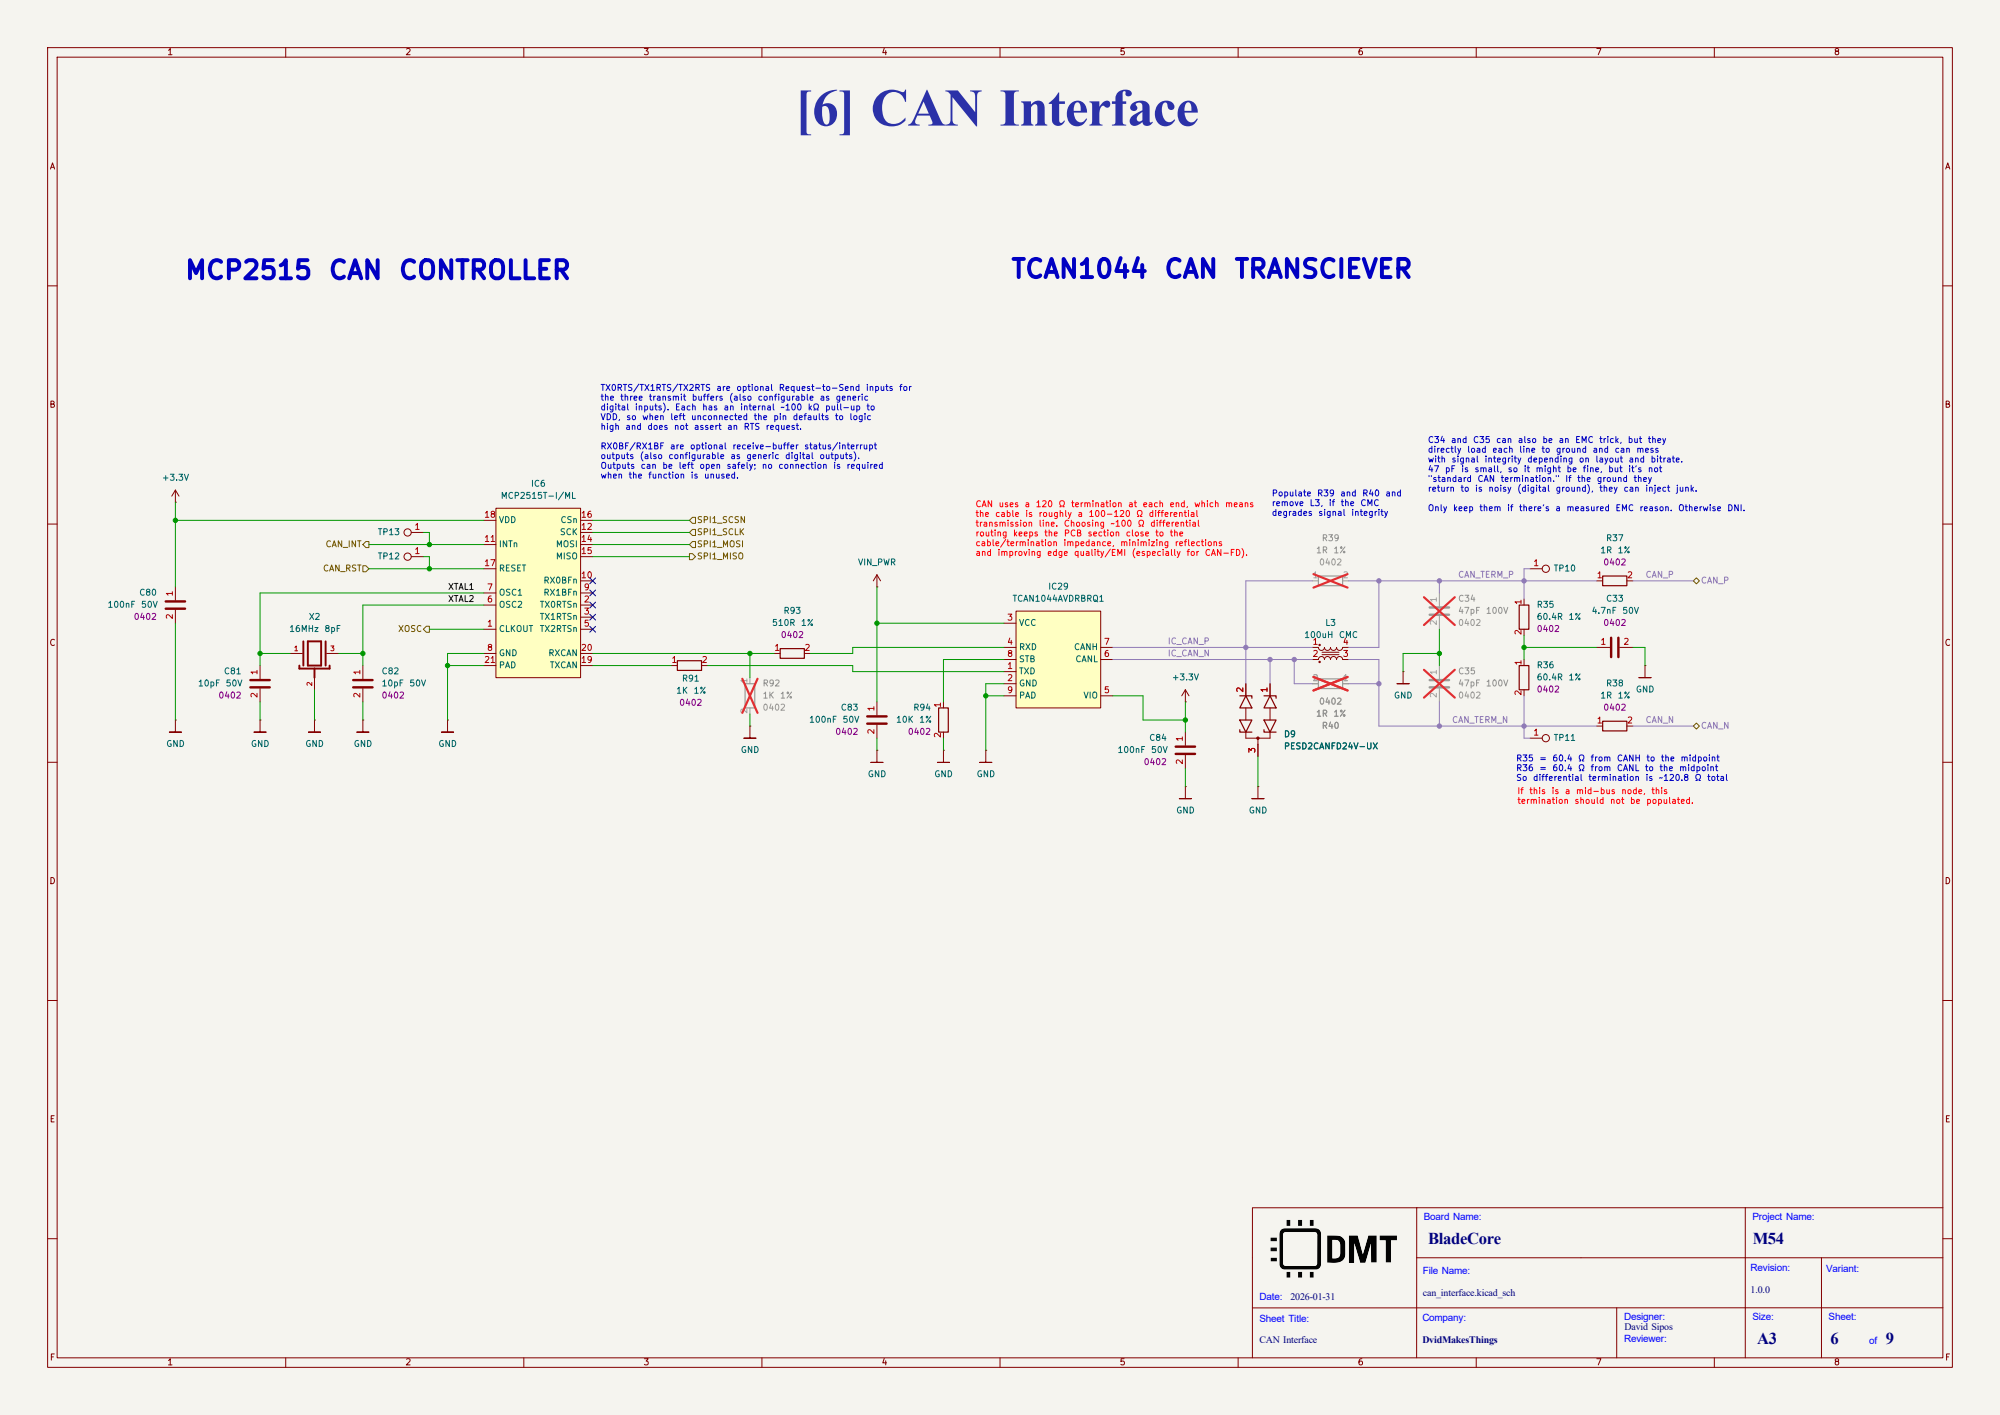
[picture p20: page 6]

when the function is unused. MCP2515 CAN CONTROLLER

So differential termination is ~120.8 Ω total TCAN1044 CAN TRANSCIEVER

TX0RTS/TX1RTS/TX2RTS are optional Request-to-Send inputs for
the three transmit buffers (also configurable as generic
digital inputs). Each has an internal ~100 kΩ pull-up to
VDD, so when left unconnected the pin defaults to logic
high and does not assert an RTS request.

C34 and C35 can also be an EMC trick, but they
directly load each line to ground and can mess with signal integrity depending on layout and bitrate. 47 pF is small, so it might be fine, but it's not

RX0BF/RX1BF are optional receive-buffer status/interrupt
outputs (also configurable as generic digital outputs).
Outputs can be left open safely; no connection is required

"standard CAN termination." If the ground they
return to is noisy (digital ground), they can inject junk.

Populate R39 and R40 and
remove L3, if the CMC
degrades signal integrity

CAN uses a 120 Ω termination at each end, which means
the cable is roughly a 100-120 Ω differential
transmission line. Choosing ~100 Ω differential
routing keeps the PCB section close to the
cable/termination impedance, minimizing reflections
and improving edge quality/EMI (especially for CAN-FD).

Only keep them if there's a measured EMC reason. Otherwise DNI.

R35 = 60.4 Ω from CANH to the midpoint
R36 = 60.4 Ω from CANL to the midpoint

If this is a mid-bus node, this
termination should not be populated.

File Name: Sheet Title: CAN Interface


5V_IND [7] USB Interface and Power
from M.2 connector ONBOARD USB INDICATOR LED

USB powering is needed +5V to 3.3V PMIC

the debug header itself PGOOD LOGIC

VBUS_ONBOARD: +5V from the onboard USB-C
VBUS_ISO: USB +5V from the M.2 connector
+5V: Supply voltage from external source

3.3V setpoint (FB divider):
Datasheet "Setting the Output Voltage"
formula: Vout = Vfb * (1 + R1/R2), Vfb = 0.8V.

Chosen 1% values: R2 = 2.40k, R1 = 7.50k.
Result: Vout = 0.8 * (1 + 7.5/2.4) = 3.300V nominal.
R2 kept <= 4k to stay well under the datasheet's 4.99k guideline.

and USB route is redirected Power OK:

USB DATA-PATH SELECTOR

No need for external VBUS, R36 is DNI. Only USB data

The purpose of the MUX is debugging.
By default SEL = 0, it's connecting to the MCU
Attaching the debug header will pull SEL to 1

For USB_RP lines, no TVS needed
For USB_DBG lines, TVS is expected on

VBUS voltage sense divider and RC
filtering for the ADC input; with
equal resistors the ADC sees VBUS/2.
Only USB-Attached detection

File Name: Sheet Title: USB Interface and Power GND


File Name: Sheet Title: Power - Sequencing


File Name: Sheet Title: Revision History

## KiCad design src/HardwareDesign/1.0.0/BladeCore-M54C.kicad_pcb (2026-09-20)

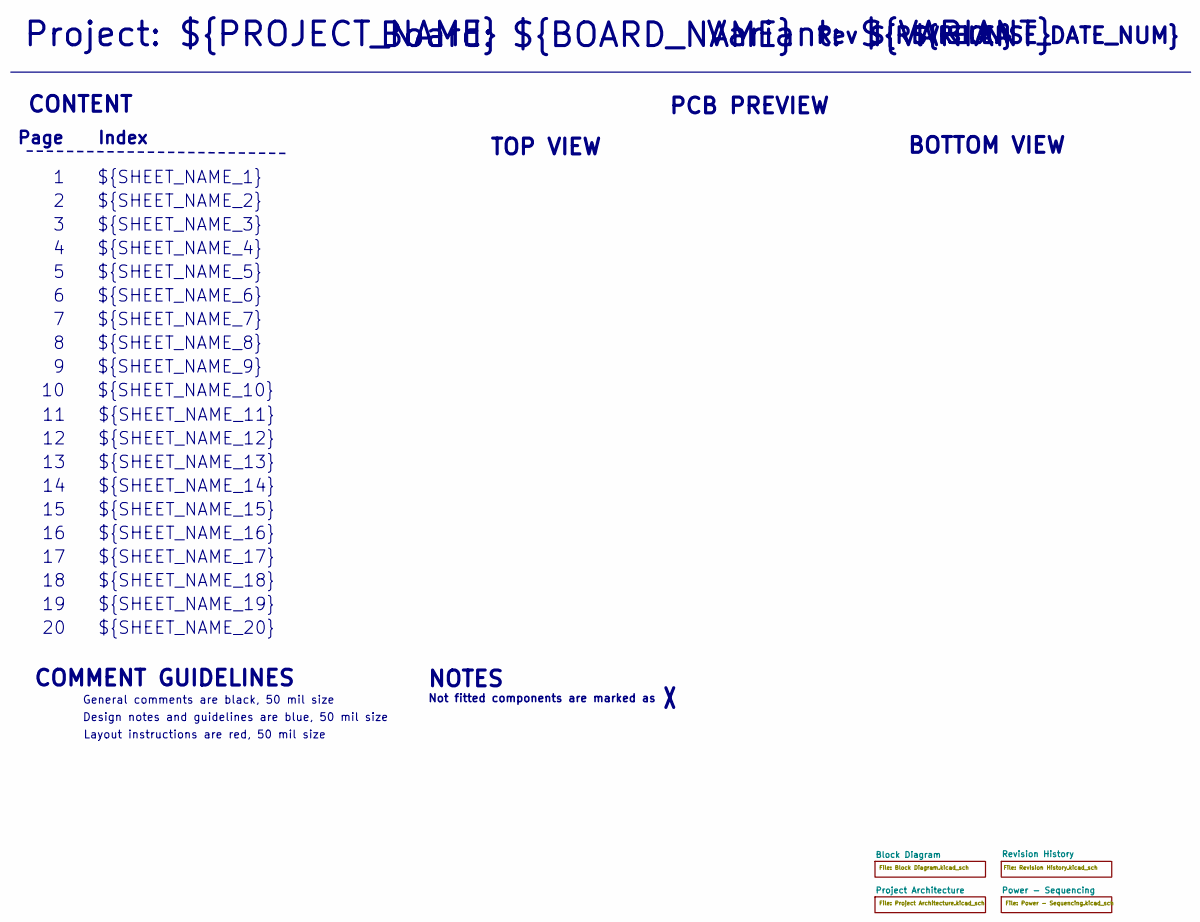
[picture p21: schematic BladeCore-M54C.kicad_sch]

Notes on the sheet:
${SHEET_NAME_12}
${SHEET_NAME_8}
${SHEET_NAME_2}
${SHEET_NAME_5}
${SHEET_NAME_20}
Page
PCB PREVIEW
${RELEASE_DATE_NUM}
CONTENT
${SHEET_NAME_11}
${SHEET_NAME_6}
Rev ${REVISION}
${SHEET_NAME_15}
BOTTOM VIEW
${SHEET_NAME_14}
${SHEET_NAME_17}
${SHEET_NAME_18}
${SHEET_NAME_7}
Not fitted components are marked as
Project: ${PROJECT_NAME}
NOTES
Design notes and guidelines are blue, 50 mil size
${SHEET_NAME_1}
${SHEET_NAME_9}
Board: ${BOARD_NAME}
General comments are black, 50 mil size
${SHEET_NAME_16}
${SHEET_NAME_3}
Variant: ${VARIANT}
${SHEET_NAME_19}
TOP VIEW
${SHEET_NAME_10}
Index
${SHEET_NAME_13}
${SHEET_NAME_4}
COMMENT GUIDELINES
Layout instructions are red, 50 mil size

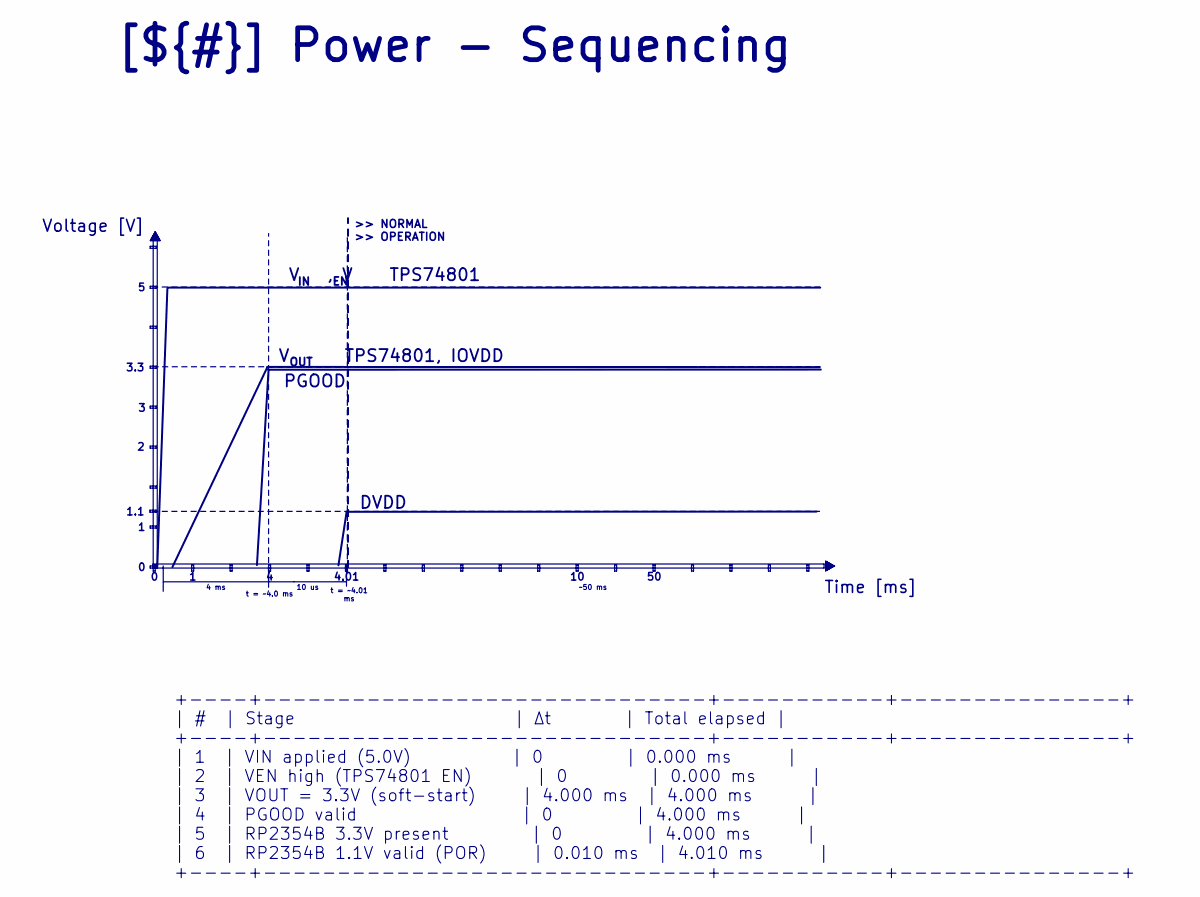
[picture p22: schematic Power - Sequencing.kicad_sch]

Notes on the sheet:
Voltage [V]
+----+------------------------------+-----------+---------------+ | # | Stage | Δt | Total elapsed | +----+------------------------------+-----------+---------------+ | 1 | VIN applied (5.0V) | 0 | 0.000 ms | | 2 | VEN high (TPS74801 EN) | 0 | 0.000 ms | | 3 | VOUT = 3.3V (soft-start) | 4.000 ms | 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
>> NORMAL >> OPERATION
Time [ms]
10 us
4.01
DVDD
t = ~4.01 ms
3.3
~50 ms
V , V TPS74801
t = ~4.0 ms
PGOOD
1.1
4 ms
OUT
V TPS74801, IOVDD
[${#}] ${TITLE}

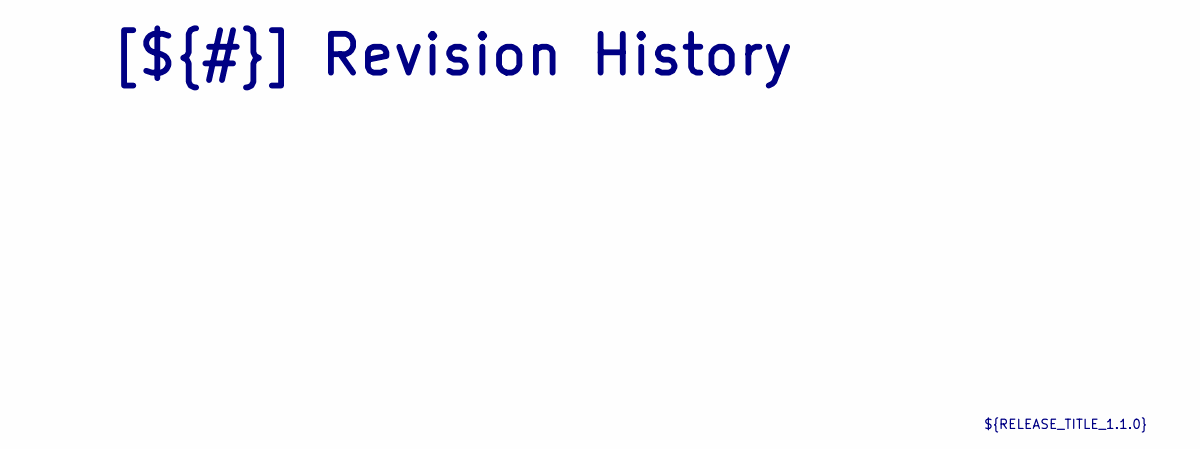
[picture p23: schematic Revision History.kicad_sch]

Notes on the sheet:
[${#}] ${TITLE}
${RELEASE_TITLE_1.1.0}

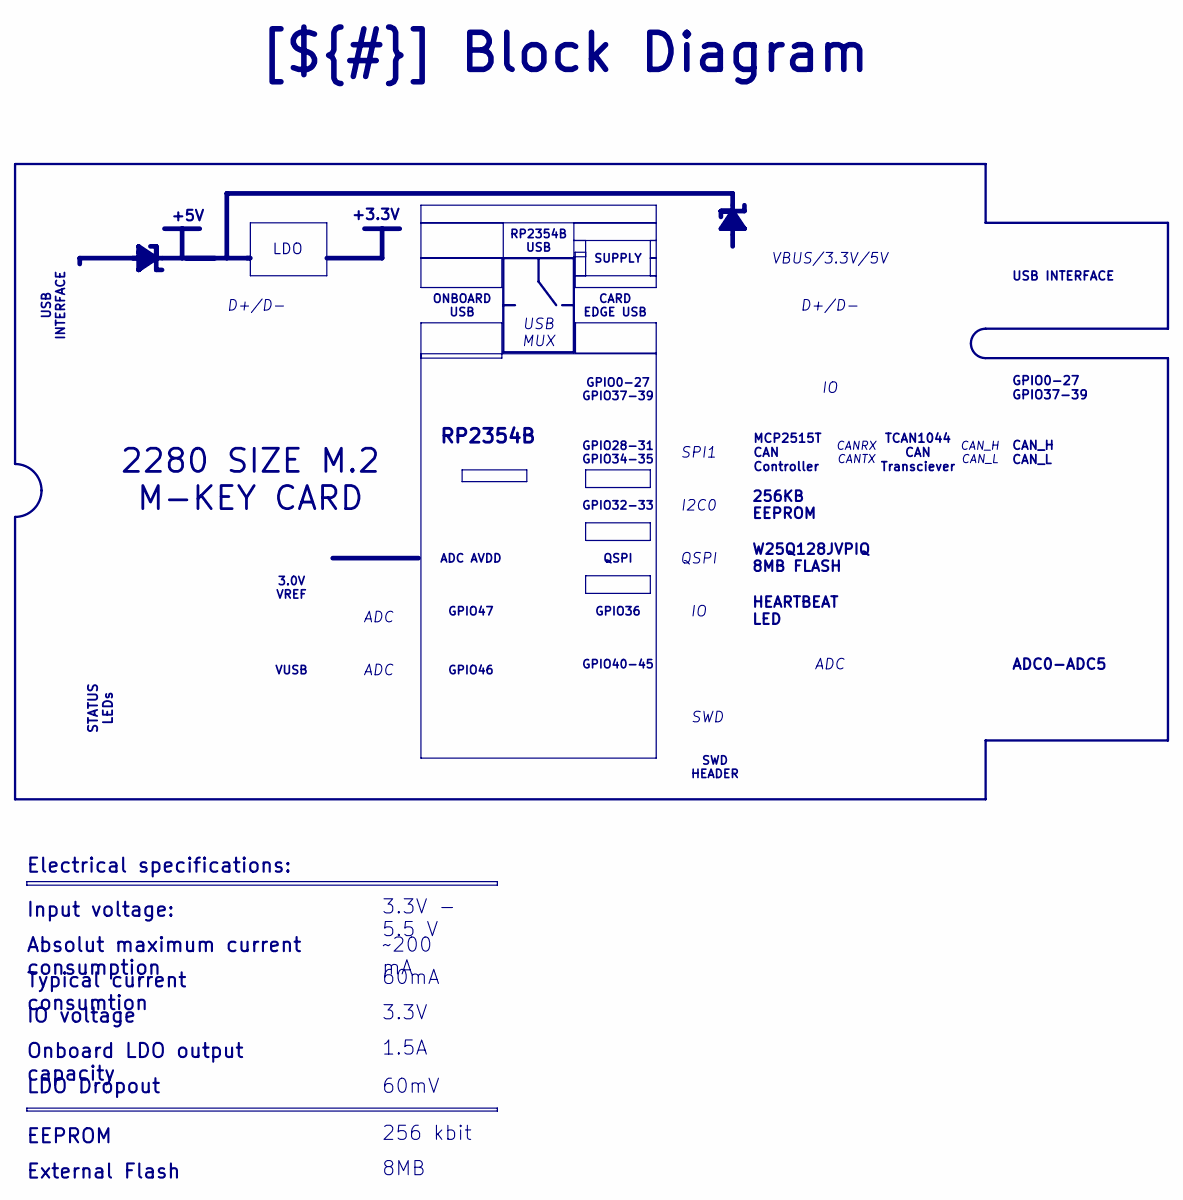
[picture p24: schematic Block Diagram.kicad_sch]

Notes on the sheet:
+3.3V
RP2354B
2280 SIZE M.2 M-KEY CARD
+5V
USB INTERFACE
LDO Dropout
IO voltage
256KB EEPROM
VBUS/3.3V/5V
1.5A
CARD EDGE USB
W25Q128JVPIQ 8MB FLASH
3.3V - 5.5 V
ADC0-ADC5
SWD HEADER
LDO
3.3V
GPIO0-27 GPIO37-39
CAN_H CAN_L
SPI1
MCP2515T CAN Controller
TCAN1044 CAN Transciever
GPIO40-45
ADC
QSPI
3.0V VREF
RP2354B USB
GPIO32-33
[${#}] ${TITLE}
~200 mA
Input voltage:
STATUS LEDs
EEPROM
GPIO46
256 kbit
Electrical specifications:
SWD
GPIO47
GPIO36
GPIO28-31 GPIO34-35

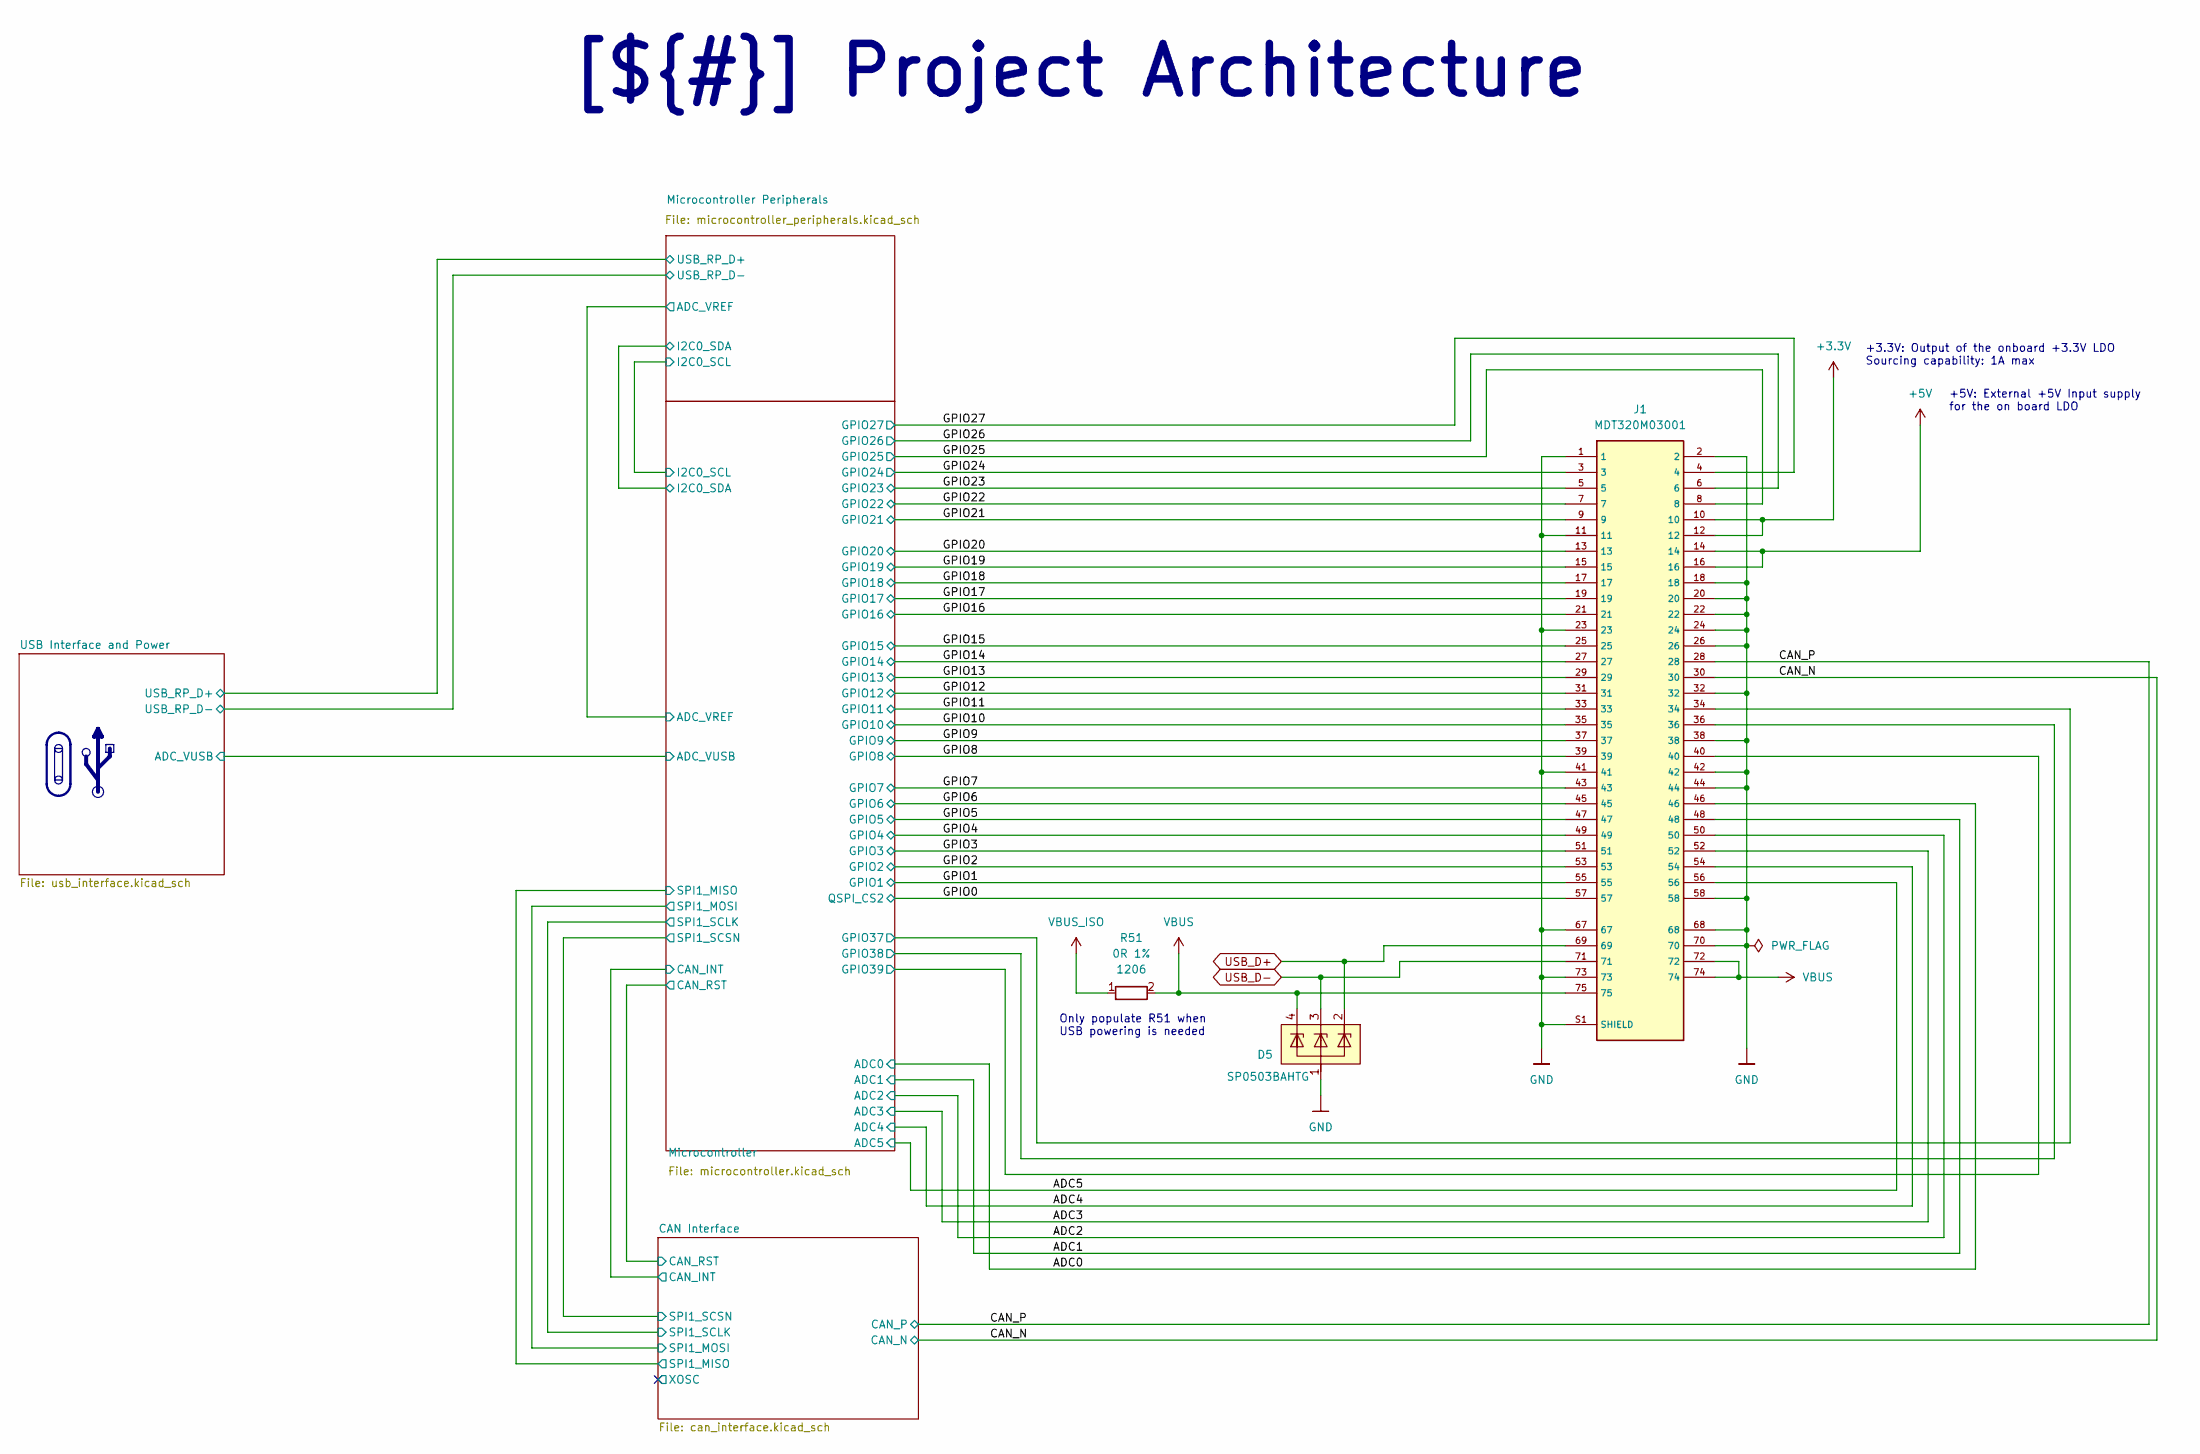
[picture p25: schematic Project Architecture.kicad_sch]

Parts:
D5: SP0503BAHTG; SOT143; MPN SP0503BAHTG; LCSC_PART C3040626
J1: MDT320M03001; M.2-M-KEY_Card_Plain
R51: 0R 1%; R_1206_3216Metric; LCSC_PART C205296

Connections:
+3.3V: J1.10, J1.12; also elsewhere on the board
+5V: J1.14, J1.16; also elsewhere on the board
/Project Architecture/ADC0: J1.46; also elsewhere on the board
/Project Architecture/ADC1: J1.48; also elsewhere on the board
/Project Architecture/ADC2: J1.50; also elsewhere on the board
/Project Architecture/ADC3: J1.52; also elsewhere on the board
/Project Architecture/ADC4: J1.54; also elsewhere on the board
/Project Architecture/ADC5: J1.56; also elsewhere on the board
/Project Architecture/CAN_N: J1.30; also elsewhere on the board
/Project Architecture/CAN_P: J1.28; also elsewhere on the board
/Project Architecture/GPIO0: J1.57; also elsewhere on the board
/Project Architecture/GPIO1: J1.55; also elsewhere on the board
/Project Architecture/GPIO2: J1.53; also elsewhere on the board
/Project Architecture/GPIO3: J1.51; also elsewhere on the board
/Project Architecture/GPIO4: J1.49; also elsewhere on the board
/Project Architecture/GPIO5: J1.47; also elsewhere on the board
/Project Architecture/GPIO6: J1.45; also elsewhere on the board
/Project Architecture/GPIO7: J1.43; also elsewhere on the board
/Project Architecture/GPIO8: J1.39; also elsewhere on the board
/Project Architecture/GPIO9: J1.37; also elsewhere on the board
/Project Architecture/GPIO10: J1.35; also elsewhere on the board
/Project Architecture/GPIO11: J1.33; also elsewhere on the board
/Project Architecture/GPIO12: J1.31; also elsewhere on the board
/Project Architecture/GPIO13: J1.29; also elsewhere on the board
/Project Architecture/GPIO14: J1.27; also elsewhere on the board
/Project Architecture/GPIO15: J1.25; also elsewhere on the board
/Project Architecture/GPIO16: J1.21; also elsewhere on the board
/Project Architecture/GPIO17: J1.19; also elsewhere on the board
/Project Architecture/GPIO18: J1.17; also elsewhere on the board
/Project Architecture/GPIO19: J1.15; also elsewhere on the board
/Project Architecture/GPIO20: J1.13; also elsewhere on the board
/Project Architecture/GPIO21: J1.9; also elsewhere on the board
/Project Architecture/GPIO22: J1.7; also elsewhere on the board
/Project Architecture/GPIO23: J1.5; also elsewhere on the board
/Project Architecture/GPIO24: J1.3; also elsewhere on the board
/Project Architecture/GPIO25: J1.8; also elsewhere on the board
/Project Architecture/GPIO26: J1.6; also elsewhere on the board
/Project Architecture/GPIO27: J1.4; also elsewhere on the board
/Project Architecture/Microcontroller/GPIO37: J1.34; also elsewhere on the board
/Project Architecture/Microcontroller/GPIO38: J1.36; also elsewhere on the board
/Project Architecture/Microcontroller/GPIO39: J1.40; also elsewhere on the board
GND: D5.1, J1.1, J1.2, J1.11, J1.18, J1.20, J1.22, J1.23, J1.24, J1.26, J1.32, J1.38, J1.41, J1.42, J1.44, J1.58, J1.67, J1.68, J1.70, J1.73, J1.S1 (SHIELD); also elsewhere on the board
USB_D+: D5.2, J1.69; also elsewhere on the board
USB_D-: D5.3, J1.71; also elsewhere on the board
VBUS: D5.4, J1.72, J1.74, J1.75, R51.2; also elsewhere on the board
VBUS_ISO: R51.1; also elsewhere on the board

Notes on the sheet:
Only populate R51 when USB powering is needed
+3.3V: Output of the onboard +3.3V LDO Sourcing capability: 1A max
+5V: External +5V Input supply for the on board LDO
[${#}] ${TITLE}

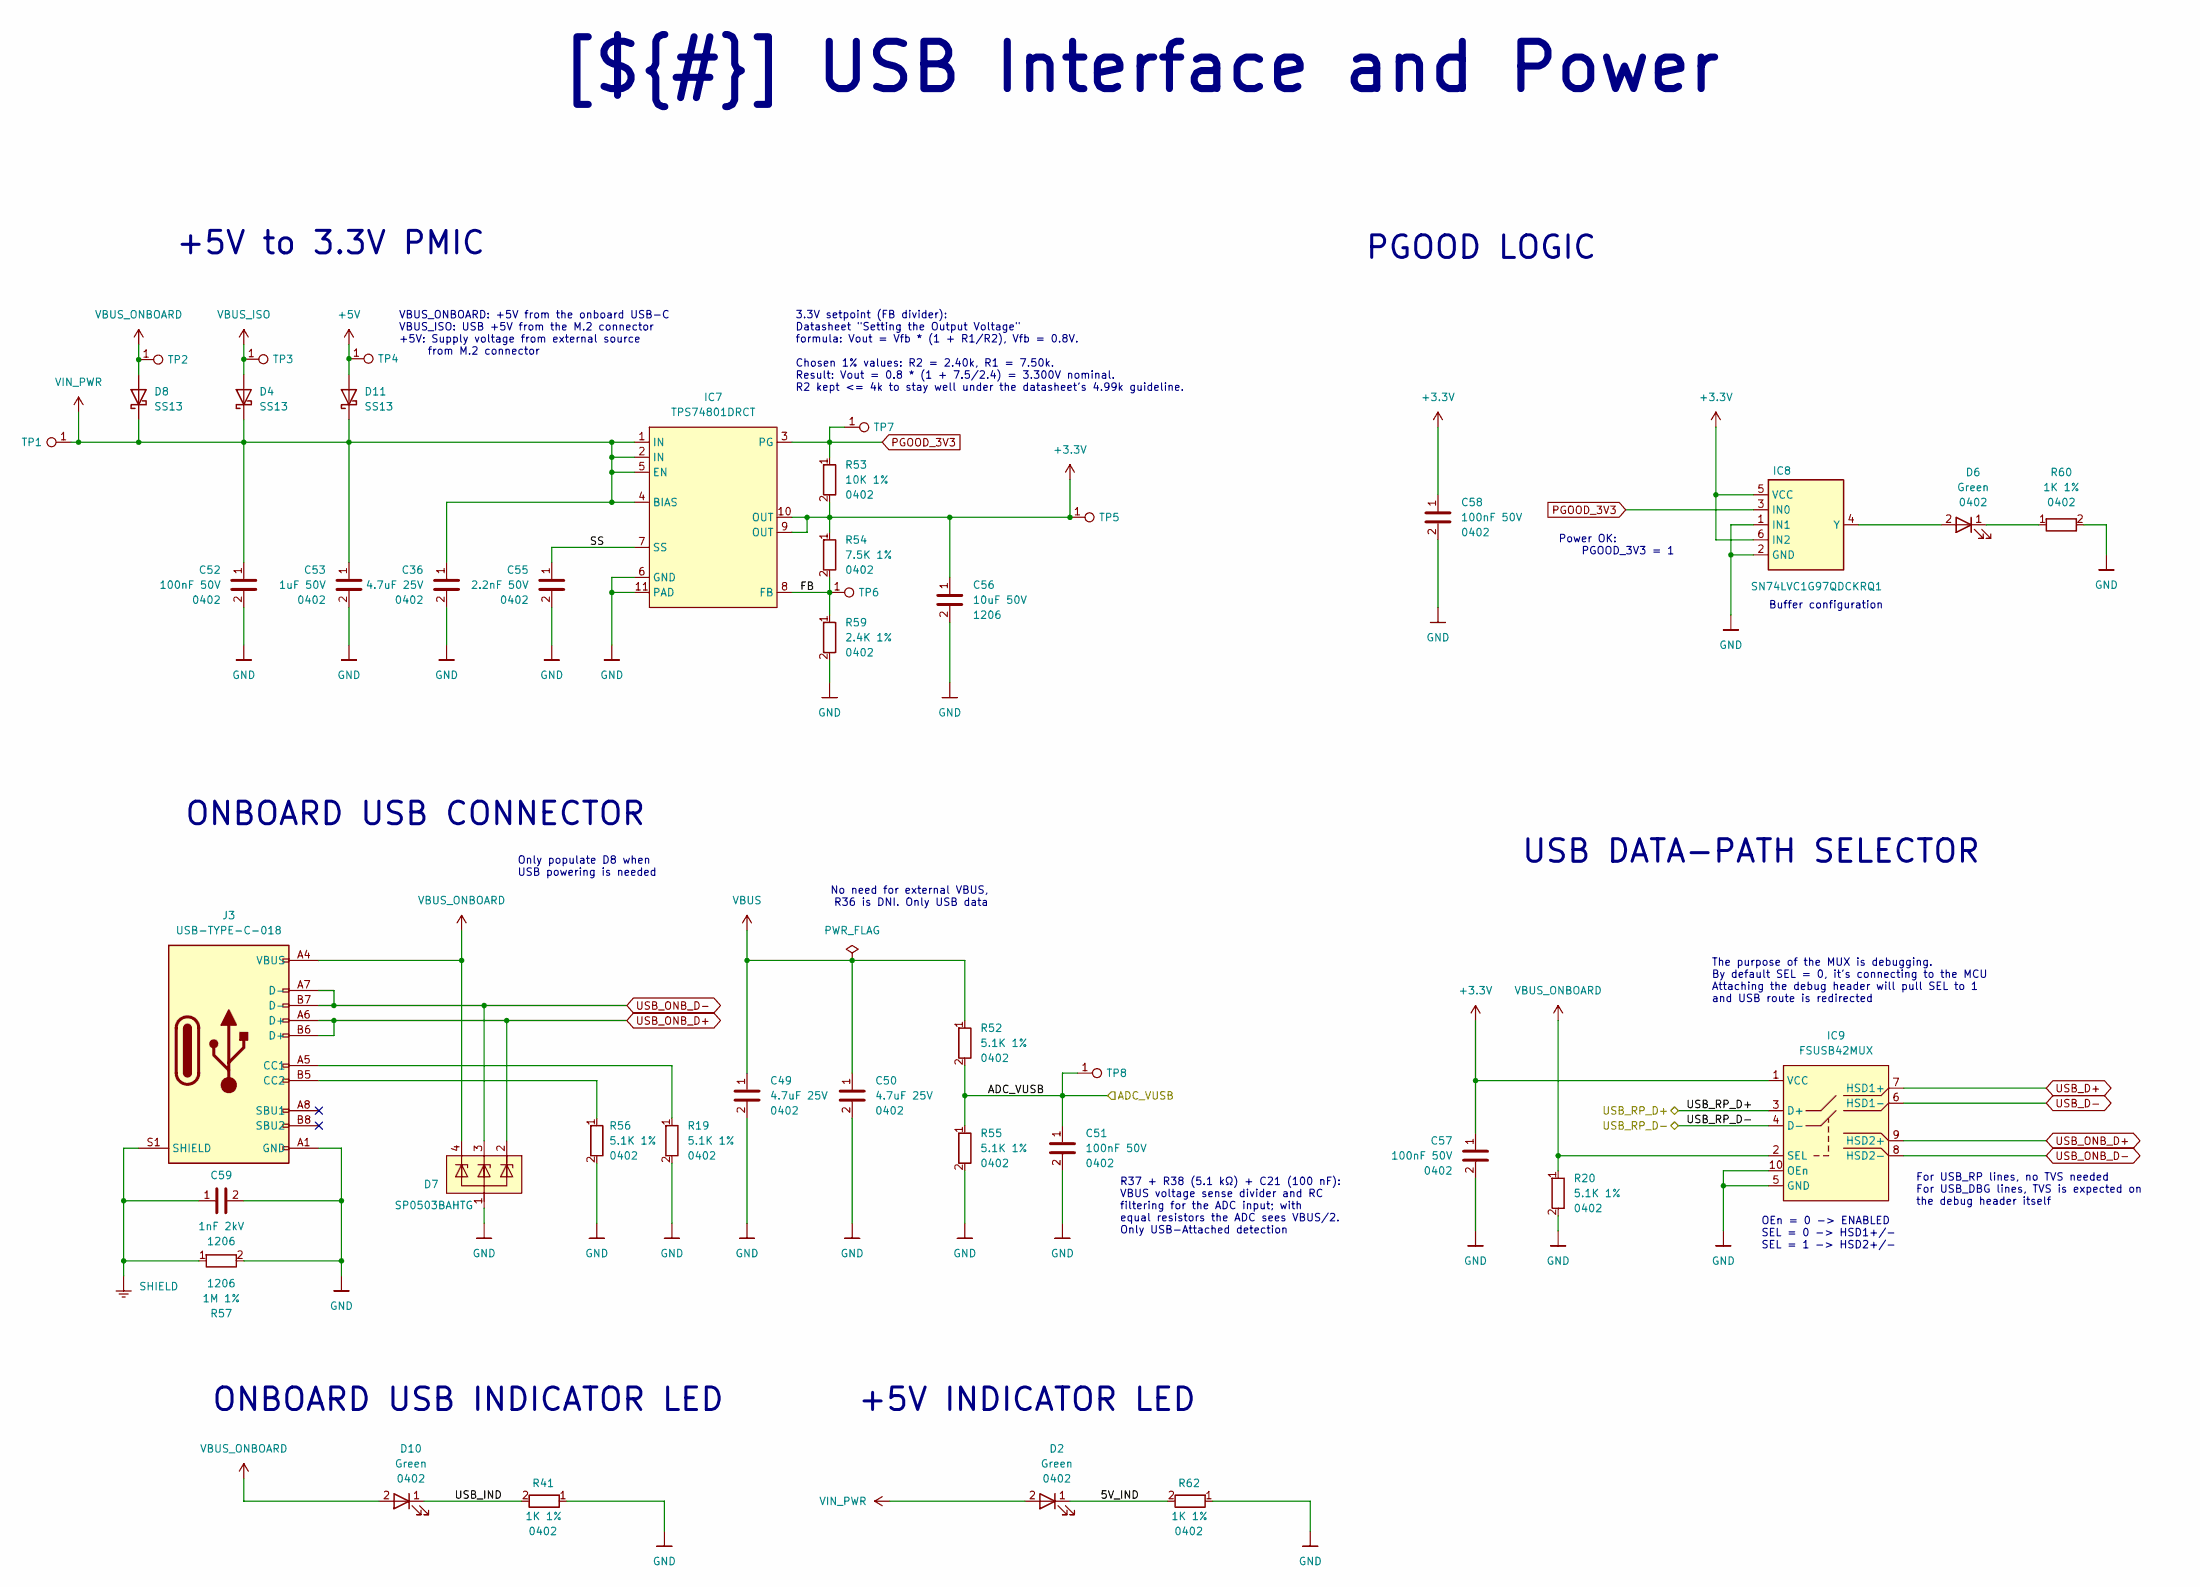
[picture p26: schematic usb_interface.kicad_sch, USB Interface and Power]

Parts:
C36, C49, C50: 4.7uF 25V; C_0402_1005Metric; LCSC_PART C22367824
C51, C52, C57, C58: 100nF 50V; C_0402_1005Metric; LCSC_PART C307331
C53: 1uF 50V; C_0402_1005Metric; LCSC_PART C1518208
C55: 2.2nF 50V; C_0402_1005Metric; MPN CC0402KRX7R9BB222; LCSC_PART C106861
C56: 10uF 50V; C_1206_3216Metric; MPN CL31A106KBHNNNE; LCSC_PART C13585
C59: 1nF 2kV; C_1206_3216Metric; LCSC_PART C173242
D2, D6, D10: Green; LED_0402_1005Metric; MPN XL-1005UGC; LCSC_PART C965793
D4, D8, D11: SS13; D_SMA
D7: SP0503BAHTG; SOT143; MPN SP0503BAHTG; LCSC_PART C3040626
IC7: TPS74801DRCT; VSON-10-1EP_3x3mm_P0.5mm_EP1.65x2.4mm_ThermalVias; MPN TPS74801DRCT; LCSC_PART C882845
IC8: SN74LVC1G97QDCKRQ1; SOT-363_SC-70-6; MPN SN74LVC1G97QDCKRQ1; LCSC_PART C179911
IC9: FSUSB42MUX; MSOP-10_3x3mm_P0.5mm; MPN FSUSB42MUX; LCSC_PART C11355
J3: USB-TYPE-C-018; USB_C_Receptacle_HCTL_HC-TYPE-C-16P-01A; MPN USB-TYPE-C-018; LCSC_PART C2927038
R19, R20, R52, R55, R56: 5.1K 1%; R_0402_1005Metric; LCSC_PART C25905
R41, R60, R62: 1K 1%; R_0402_1005Metric; LCSC_PART C11702
R53: 10K 1%; R_0402_1005Metric; LCSC_PART C25744
R54: 7.5K 1%; R_0402_1005Metric; LCSC_PART C25918
R57: 1M 1%; R_1206_3216Metric; LCSC_PART C17927
R59: 2.4K 1%; R_0402_1005Metric; LCSC_PART C25882
TP1, TP2, TP3, TP4, TP5, TP6, TP7, TP8: TestPoint_0.6mm

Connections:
+3.3V: C56.1, C57.1, C58.1, IC7.9 (OUT), IC7.10 (OUT), IC8.5 (VCC), IC8.6 (IN2), IC9.1 (VCC), R53.2, R54.1, TP5.1; also elsewhere on the board
+5V: D11.2 (A), TP4.1; also elsewhere on the board
/Project Architecture/Microcontroller/ADC_VUSB: C51.1, R52.2, R55.1, TP8.1; also elsewhere on the board
/Project Architecture/USB Interface and Power/5V_IND: D2.1, R62.2
/Project Architecture/USB Interface and Power/FB: IC7.8 (FB), R54.2, R59.1, TP6.1
/Project Architecture/USB Interface and Power/SS: C55.1, IC7.7 (SS)
/Project Architecture/USB Interface and Power/USB_IND: D10.1, R41.2
/Project Architecture/USB Interface and Power/USB_RP_D+: IC9.3 (D+); also elsewhere on the board
/Project Architecture/USB Interface and Power/USB_RP_D-: IC9.4 (D-); also elsewhere on the board
GND: C36.2, C49.2, C50.2, C51.2, C52.2, C53.2, C55.2, C56.2, C57.2, C58.2, C59.2, D7.1, IC7.6 (GND), IC7.11 (PAD), IC8.1 (IN1), IC8.2 (GND), IC9.5 (GND), IC9.10 (OEn), J3.A1 (GND), J3.A12 (GND), J3.B1 (GND), J3.B12 (GND), R19.2, R20.2, R41.1, R55.2, R56.2, R57.2, R59.2, R60.2, R62.1; also elsewhere on the board
unnamed: D6.1, R60.1
unnamed: D6.2, IC8.4 (Y)
unnamed: J3.A5 (CC1), R19.1
unnamed: J3.B5 (CC2), R56.1
PGOOD_3V3: IC7.3 (PG), IC8.3 (IN0), R53.1, TP7.1
SHIELD: C59.1, J3.S1 (SHIELD), R57.1
USB_D+: IC9.7 (HSD1+); also elsewhere on the board
USB_D-: IC9.6 (HSD1-); also elsewhere on the board
USB_ONB_D+: D7.2, IC9.9 (HSD2+), J3.A6 (D+), J3.B6 (D+)
USB_ONB_D-: D7.3, IC9.8 (HSD2-), J3.A7 (D-), J3.B7 (D-)
VBUS: C49.1, C50.1, R52.1; also elsewhere on the board
VBUS_ISO: D4.2 (A), TP3.1; also elsewhere on the board
VBUS_ONBOARD: D7.4, D8.2 (A), D10.2, IC9.2 (SEL), J3.A4 (VBUS), J3.A9 (VBUS), J3.B4 (VBUS), J3.B9 (VBUS), R20.1, TP2.1
VIN_PWR: C36.1, C52.1, C53.1, D2.2, D4.1 (K), D8.1 (K), D11.1 (K), IC7.1 (IN), IC7.2 (IN), IC7.4 (BIAS), IC7.5 (EN), TP1.1; also elsewhere on the board

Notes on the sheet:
OEn = 0 -> ENABLED SEL = 0 -> HSD1+/- SEL = 1 -> HSD2+/-
ONBOARD USB INDICATOR LED
USB DATA-PATH SELECTOR
VBUS_ONBOARD: +5V from the onboard USB-C VBUS_ISO: USB +5V from the M.2 connector +5V: Supply voltage from external source from M.2 connector
No need for external VBUS, R36 is DNI. Only USB data
+5V to 3.3V PMIC
3.3V setpoint (FB divider): Datasheet "Setting the Output Voltage" formula: Vout = Vfb * (1 + R1/R2), Vfb = 0.8V. Chosen 1% values: R2 = 2.40k, R1 = 7.50k. Result: Vout = 0.8 * (1 + 7.5/2.4) = 3.300V nominal. R2 kept <= 4k to stay well under the datasheet's 4.99k guideline.
ONBOARD USB CONNECTOR
For USB_RP lines, no TVS needed For USB_DBG lines, TVS is expected on the debug header itself
R37 + R38 (5.1 kΩ) + C21 (100 nF): VBUS voltage sense divider and RC filtering for the ADC input; with equal resistors the ADC sees VBUS/2. Only USB-Attached detection
+5V INDICATOR LED
Power OK: PGOOD_3V3 = 1
Buffer configuration
PGOOD LOGIC
Only populate D8 when USB powering is needed
The purpose of the MUX is debugging. By default SEL = 0, it's connecting to the MCU Attaching the debug header will pull SEL to 1 and USB route is redirected
[${#}] ${TITLE}

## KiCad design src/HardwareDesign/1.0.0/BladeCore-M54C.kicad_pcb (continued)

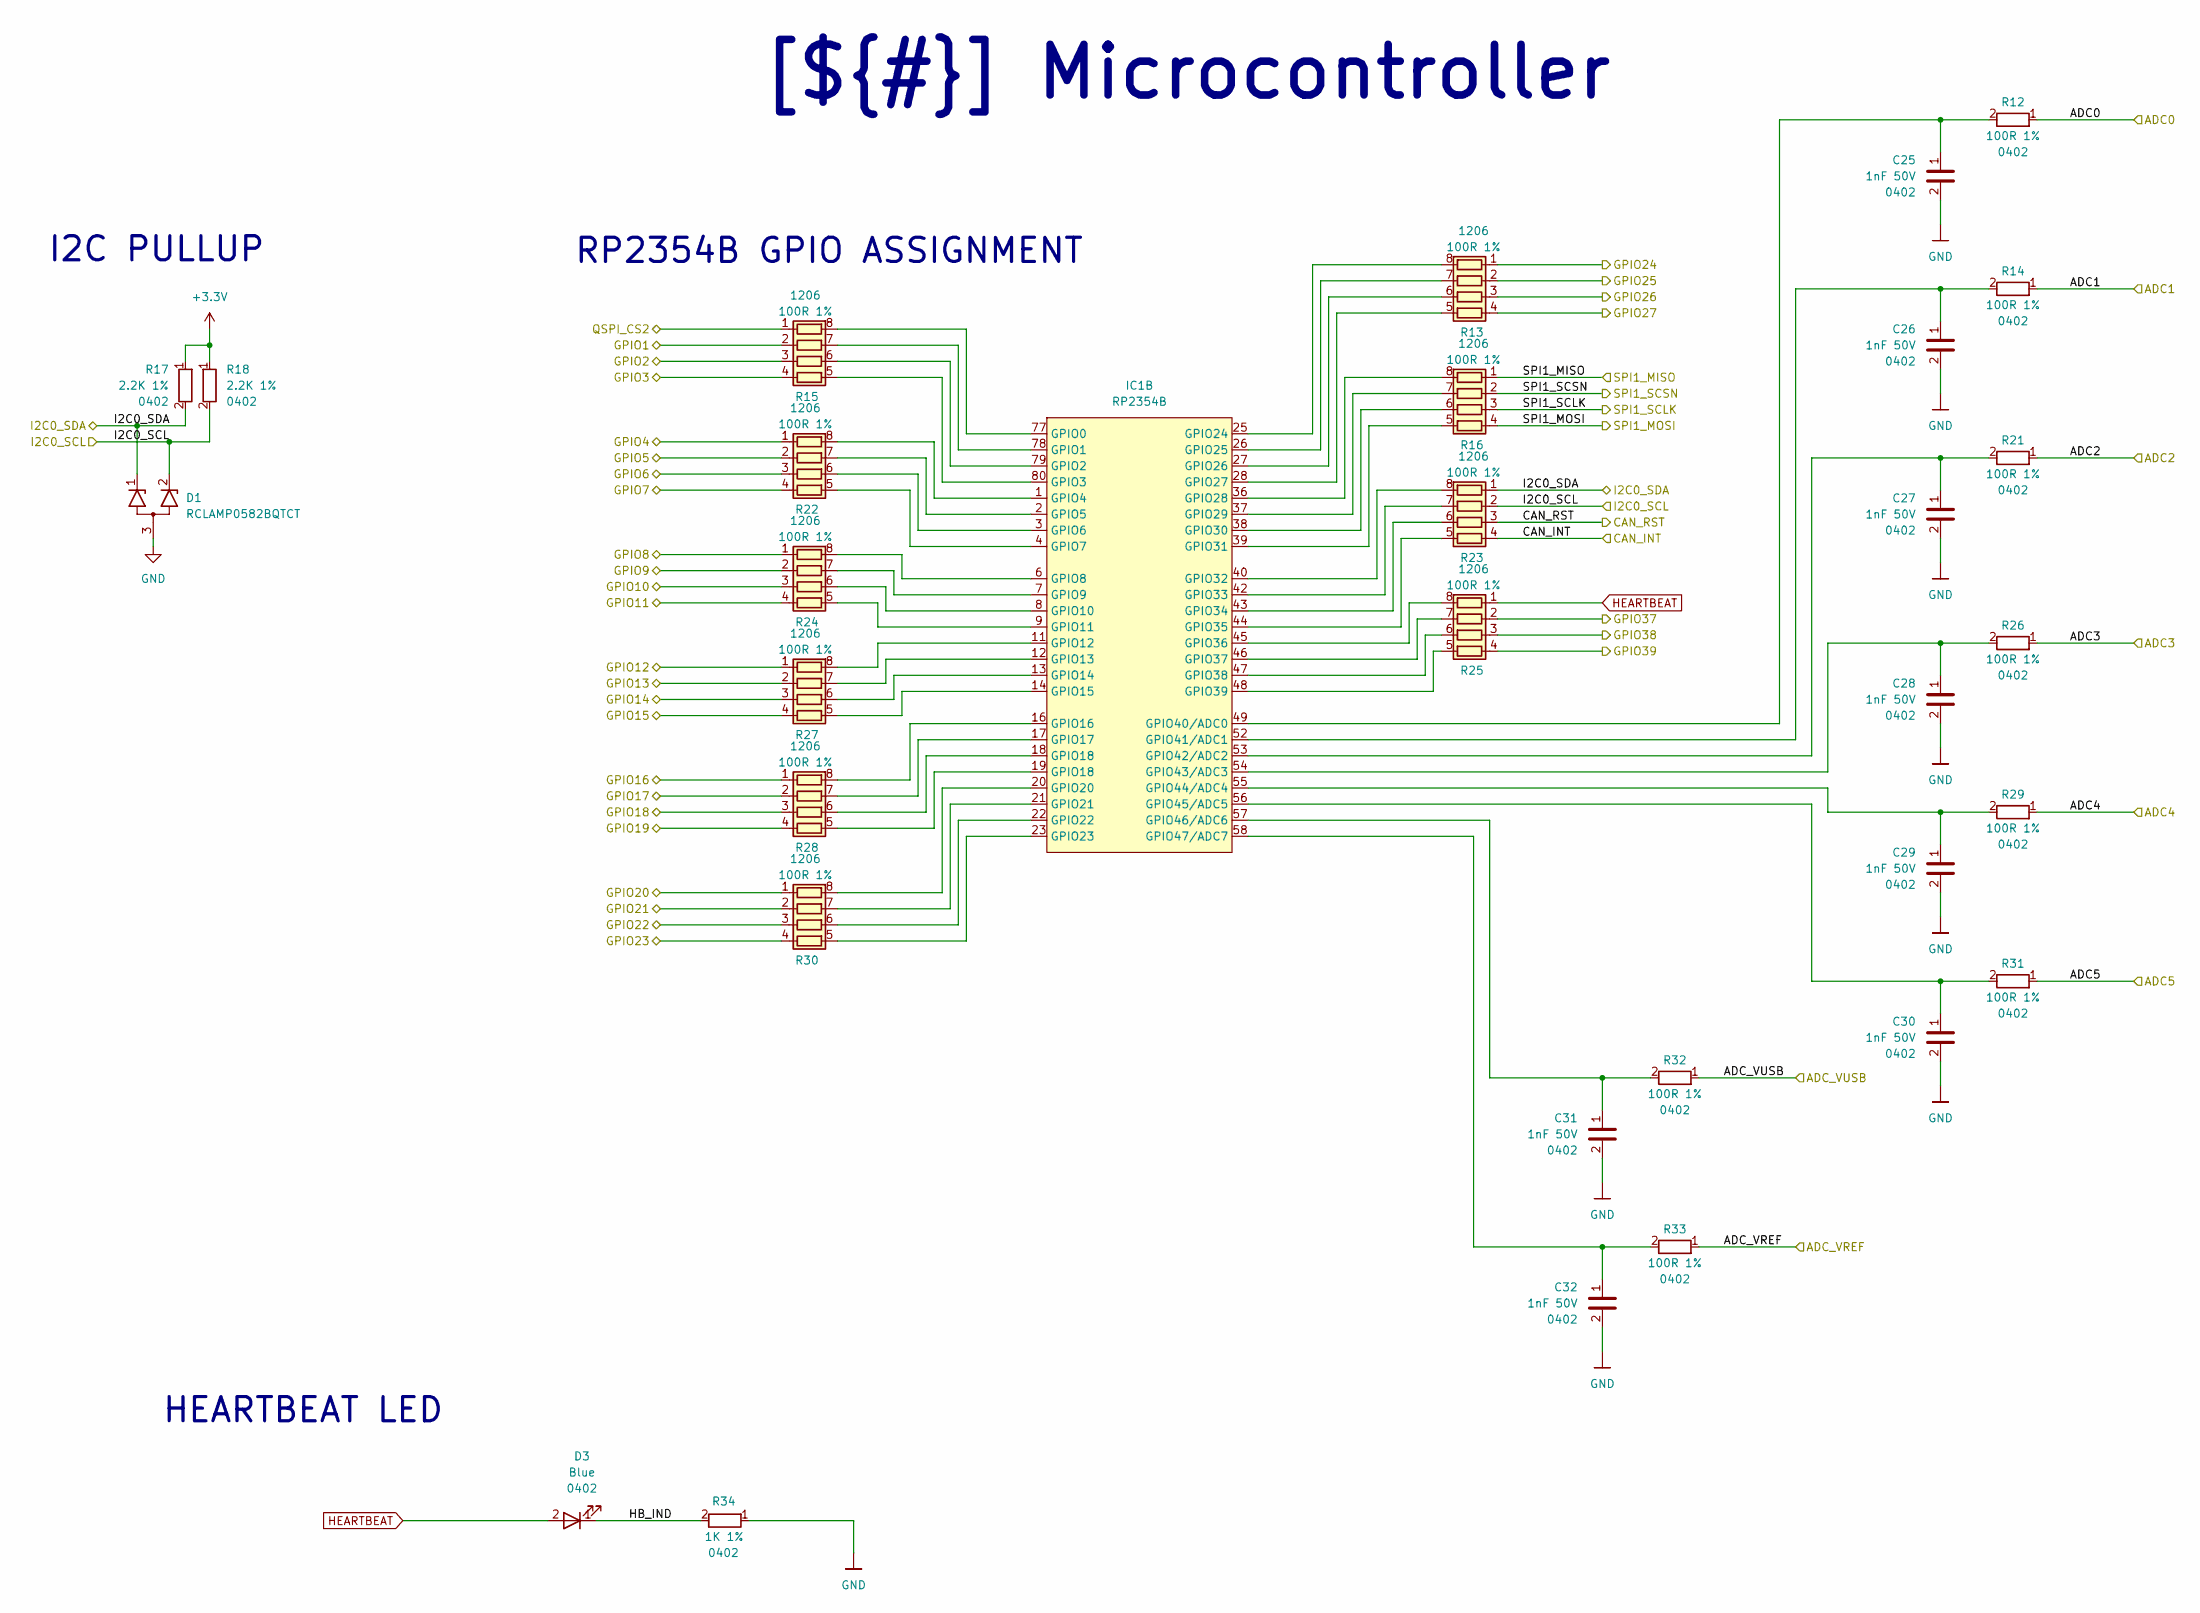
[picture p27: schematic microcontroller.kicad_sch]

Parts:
C25, C26, C27, C28, C29, C30, C31, C32: 1nF 50V; C_0402_1005Metric; LCSC_PART C14442
D1: RCLAMP0582BQTCT; SOT-416; MPN RCLAMP0582BQTCT; LCSC_PART C841193
D3: Blue; LED_0402_1005Metric; MPN XL-1005UBC; LCSC_PART C22355736
IC1: RP2354B; QFN80_10x10; MPN RP2354B; LCSC_PART C39843328
R12, R14, R21, R26, R29, R31, R32, R33: 100R 1%; R_0402_1005Metric; LCSC_PART C25076
R13, R15, R16, R22, R23, R24, R25, R27, R28, R30: 100R 1%; R_Array_Convex_4x0603; MPN YC164-FR-07100RL; LCSC_PART C136838
R17, R18: 2.2K 1%; R_0402_1005Metric; LCSC_PART C25879
R34: 1K 1%; R_0402_1005Metric; LCSC_PART C11702

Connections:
+3.3V: R17.1, R18.1; also elsewhere on the board
/Project Architecture/ADC0: R12.1; also elsewhere on the board
/Project Architecture/ADC1: R14.1; also elsewhere on the board
/Project Architecture/ADC2: R21.1; also elsewhere on the board
/Project Architecture/ADC3: R26.1; also elsewhere on the board
/Project Architecture/ADC4: R29.1; also elsewhere on the board
/Project Architecture/ADC5: R31.1; also elsewhere on the board
/Project Architecture/GPIO0: R15.1 (R11); also elsewhere on the board
/Project Architecture/GPIO1: R15.2 (R12); also elsewhere on the board
/Project Architecture/GPIO2: R15.3 (R13); also elsewhere on the board
/Project Architecture/GPIO3: R15.4 (R14); also elsewhere on the board
/Project Architecture/GPIO4: R22.1 (R11); also elsewhere on the board
/Project Architecture/GPIO5: R22.2 (R12); also elsewhere on the board
/Project Architecture/GPIO6: R22.3 (R13); also elsewhere on the board
/Project Architecture/GPIO7: R22.4 (R14); also elsewhere on the board
/Project Architecture/GPIO8: R24.1 (R11); also elsewhere on the board
/Project Architecture/GPIO9: R24.2 (R12); also elsewhere on the board
/Project Architecture/GPIO10: R24.3 (R13); also elsewhere on the board
/Project Architecture/GPIO11: R24.4 (R14); also elsewhere on the board
/Project Architecture/GPIO12: R27.1 (R11); also elsewhere on the board
/Project Architecture/GPIO13: R27.2 (R12); also elsewhere on the board
/Project Architecture/GPIO14: R27.3 (R13); also elsewhere on the board
/Project Architecture/GPIO15: R27.4 (R14); also elsewhere on the board
/Project Architecture/GPIO16: R28.1 (R11); also elsewhere on the board
/Project Architecture/GPIO17: R28.2 (R12); also elsewhere on the board
/Project Architecture/GPIO18: R28.3 (R13); also elsewhere on the board
/Project Architecture/GPIO19: R28.4 (R14); also elsewhere on the board
/Project Architecture/GPIO20: R30.1 (R11); also elsewhere on the board
/Project Architecture/GPIO21: R30.2 (R12); also elsewhere on the board
/Project Architecture/GPIO22: R30.3 (R13); also elsewhere on the board
/Project Architecture/GPIO23: R30.4 (R14); also elsewhere on the board
/Project Architecture/GPIO24: R13.1 (R11); also elsewhere on the board
/Project Architecture/GPIO25: R13.2 (R12); also elsewhere on the board
/Project Architecture/GPIO26: R13.3 (R13); also elsewhere on the board
/Project Architecture/GPIO27: R13.4 (R14); also elsewhere on the board
/Project Architecture/Microcontroller Peripherals/ADC_VREF: R33.1; also elsewhere on the board
/Project Architecture/Microcontroller Peripherals/I2C0_SCL: D1.2 (K2), R18.2, R23.2 (R12); also elsewhere on the board
/Project Architecture/Microcontroller Peripherals/I2C0_SDA: D1.1 (K1), R17.2, R23.1 (R11); also elsewhere on the board
/Project Architecture/Microcontroller/ADC_VUSB: R32.1; also elsewhere on the board
/Project Architecture/Microcontroller/CAN_INT: R23.4 (R14); also elsewhere on the board
/Project Architecture/Microcontroller/CAN_RST: R23.3 (R13); also elsewhere on the board
/Project Architecture/Microcontroller/GPIO37: R25.2 (R12); also elsewhere on the board
/Project Architecture/Microcontroller/GPIO38: R25.3 (R13); also elsewhere on the board
/Project Architecture/Microcontroller/GPIO39: R25.4 (R14); also elsewhere on the board
/Project Architecture/Microcontroller/HB_IND: D3.1, R34.2
/Project Architecture/Microcontroller/SPI1_MISO: R16.1 (R11); also elsewhere on the board
/Project Architecture/Microcontroller/SPI1_MOSI: R16.4 (R14); also elsewhere on the board
/Project Architecture/Microcontroller/SPI1_SCLK: R16.3 (R13); also elsewhere on the board
/Project Architecture/Microcontroller/SPI1_SCSN: R16.2 (R12); also elsewhere on the board
GND: C25.2, C26.2, C27.2, C28.2, C29.2, C30.2, C31.2, C32.2, D1.3 (A), R34.1; also elsewhere on the board
HEARTBEAT: D3.2, R25.1 (R11)
unnamed: IC1.77 (GPIO0), R15.8 (R12)
unnamed: IC1.78 (GPIO1), R15.7 (R22)
unnamed: IC1.79 (GPIO2), R15.6 (R23)
unnamed: IC1.80 (GPIO3), R15.5 (R24)
unnamed: IC1.1 (GPIO4), R22.8 (R12)
unnamed: IC1.2 (GPIO5), R22.7 (R22)
unnamed: IC1.3 (GPIO6), R22.6 (R23)
unnamed: IC1.4 (GPIO7), R22.5 (R24)
unnamed: IC1.6 (GPIO8), R24.8 (R12)
unnamed: IC1.7 (GPIO9), R24.7 (R22)
unnamed: IC1.8 (GPIO10), R24.6 (R23)
unnamed: IC1.9 (GPIO11), R24.5 (R24)
unnamed: IC1.11 (GPIO12), R27.8 (R12)
unnamed: IC1.12 (GPIO13), R27.7 (R22)
unnamed: IC1.13 (GPIO14), R27.6 (R23)
unnamed: IC1.14 (GPIO15), R27.5 (R24)
unnamed: IC1.16 (GPIO16), R28.8 (R12)
unnamed: IC1.17 (GPIO17), R28.7 (R22)
unnamed: IC1.20 (GPIO20), R30.8 (R12)
unnamed: IC1.21 (GPIO21), R30.7 (R22)
unnamed: IC1.22 (GPIO22), R30.6 (R23)
unnamed: IC1.23 (GPIO23), R30.5 (R24)
unnamed: IC1.25 (GPIO24), R13.8 (R12)
unnamed: IC1.26 (GPIO25), R13.7 (R22)
unnamed: IC1.27 (GPIO26), R13.6 (R23)
unnamed: IC1.28 (GPIO27), R13.5 (R24)
unnamed: IC1.36 (GPIO28), R16.8 (R12)
unnamed: IC1.37 (GPIO29), R16.7 (R22)
unnamed: IC1.38 (GPIO30), R16.6 (R23)
unnamed: IC1.39 (GPIO31), R16.5 (R24)
unnamed: IC1.40 (GPIO32), R23.8 (R12)
unnamed: IC1.42 (GPIO33), R23.7 (R22)
unnamed: IC1.43 (GPIO34), R23.6 (R23)
unnamed: IC1.44 (GPIO35), R23.5 (R24)
unnamed: IC1.45 (GPIO36), R25.8 (R12)
unnamed: IC1.46 (GPIO37), R25.7 (R22)
unnamed: IC1.47 (GPIO38), R25.6 (R23)
unnamed: IC1.48 (GPIO39), R25.5 (R24)
unnamed: C25.1, IC1.49 (GPIO40/ADC0), R12.2
unnamed: C26.1, IC1.52 (GPIO41/ADC1), R14.2
unnamed: C27.1, IC1.53 (GPIO42/ADC2), R21.2
unnamed: C28.1, IC1.54 (GPIO43/ADC3), R26.2
unnamed: C29.1, IC1.55 (GPIO44/ADC4), R29.2
unnamed: C30.1, IC1.56 (GPIO45/ADC5), R31.2
unnamed: C31.1, IC1.57 (GPIO46/ADC6), R32.2
unnamed: C32.1, IC1.58 (GPIO47/ADC7), R33.2
unnamed: IC1.18 (GPIO18), R28.6 (R23)
unnamed: IC1.19 (GPIO18), R28.5 (R24)

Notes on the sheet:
I2C PULLUP
HEARTBEAT LED
RP2354B GPIO ASSIGNMENT
[${#}] ${TITLE}

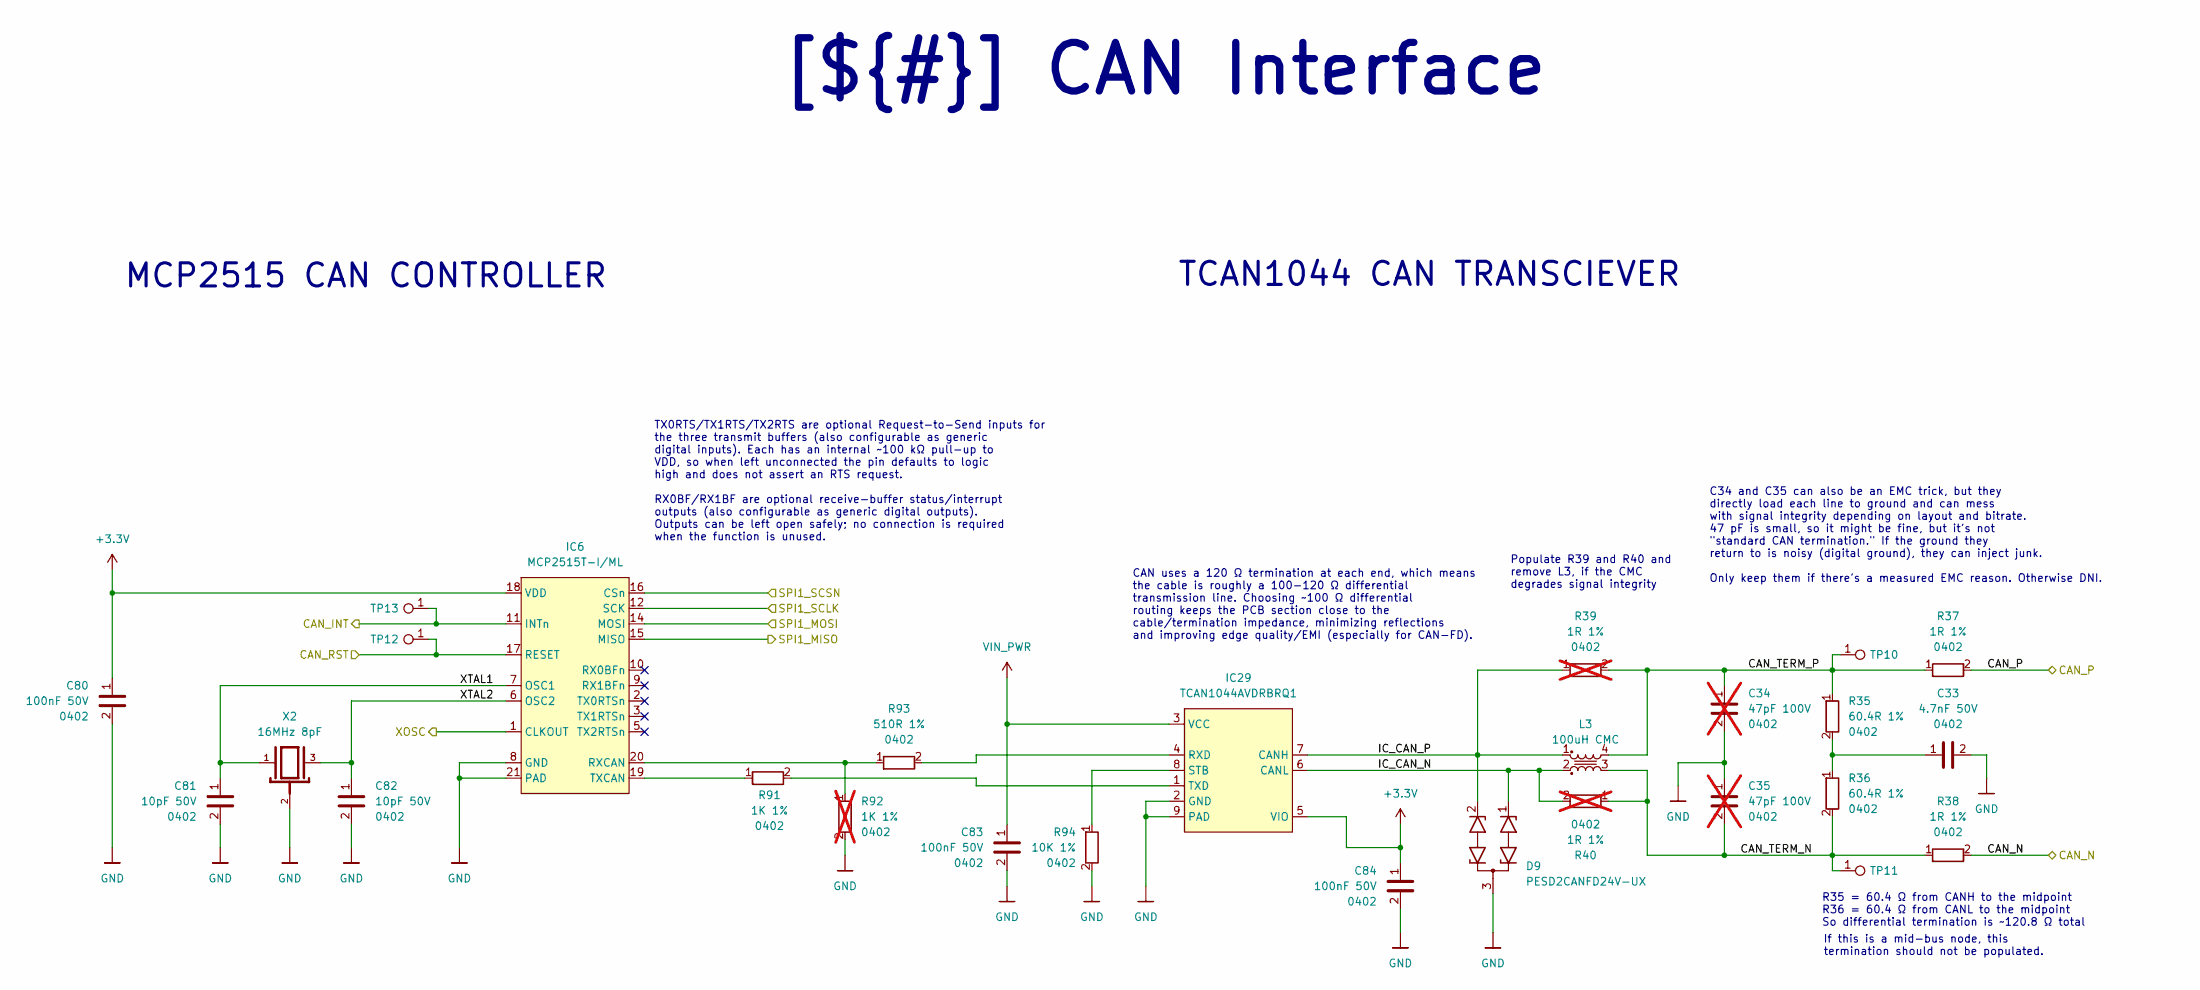
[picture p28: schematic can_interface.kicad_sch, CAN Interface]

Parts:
C33: 4.7nF 50V; C_0402_1005Metric; LCSC_PART C1538
C34, C35: 47pF 100V; C_0402_1005Metric; LCSC_PART C5358466; not fitted
C80, C83, C84: 100nF 50V; C_0402_1005Metric; LCSC_PART C307331
C81, C82: 10pF 50V; C_0402_1005Metric; LCSC_PART C466222
D9: PESD2CANFD24V-UX; SOT-323_SC-70; MPN PESD2CANFD24V-UX; LCSC_PART C46970732
IC6: MCP2515T-I/ML; QFN-20-1EP_4x4mm_P0.5mm_EP2.7x2.7mm; MPN MCP2515T-I/ML; LCSC_PART C96140
IC29: TCAN1044AVDRBRQ1; HVSON-8-1EP_3x3mm_P0.65mm_EP1.6x2.4mm; MPN TCAN1044AVDRBRQ1; LCSC_PART C3234119
L3: 100uH CMC; ACT1210D-101-2P-TL00; MPN ACT1210D-101-2P-TL00; LCSC_PART C3039743
R35, R36: 60.4R 1%; R_0402_1005Metric; MPN RC0402FR-0760R4L; LCSC_PART C137954
R37, R38: 1R 1%; R_0402_1005Metric; MPN RC0402FR-071RL; LCSC_PART C185446
R39, R40: 1R 1%; R_0402_1005Metric; MPN RC0402FR-071RL; LCSC_PART C185446; not fitted
R91: 1K 1%; R_0402_1005Metric; LCSC_PART C11702
R92: 1K 1%; R_0402_1005Metric; LCSC_PART C11702; not fitted
R93: 510R 1%; R_0402_1005Metric; MPN 0402WGF5100TCE; LCSC_PART C25123
R94: 10K 1%; R_0402_1005Metric; LCSC_PART C25744
TP10, TP11, TP12, TP13: TestPoint_0.6mm
X2: 16MHz 8pF; Crystal_SMD_2016-4Pin_2.0x1.6mm; MPN CS07826-16M; LCSC_PART C2965577

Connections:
+3.3V: C80.1, C84.1, IC6.18 (VDD), IC29.5 (VIO); also elsewhere on the board
/Project Architecture/CAN Interface/CAN_TERM_N: C35.2, L3.3, R36.2, R38.1, R40.1, TP11.1
/Project Architecture/CAN Interface/CAN_TERM_P: C34.1, L3.4, R35.1, R37.1, R39.2, TP10.1
/Project Architecture/CAN Interface/IC_CAN_N: D9.1 (K1), IC29.6 (CANL), L3.2, R40.2
/Project Architecture/CAN Interface/IC_CAN_P: D9.2 (K2), IC29.7 (CANH), L3.1, R39.1
/Project Architecture/CAN Interface/XOSC: IC6.1 (CLKOUT)
/Project Architecture/CAN Interface/XTAL1: C81.1, IC6.7 (OSC1), X2.1
/Project Architecture/CAN Interface/XTAL2: C82.1, IC6.6 (OSC2), X2.3
/Project Architecture/CAN_N: R38.2; also elsewhere on the board
/Project Architecture/CAN_P: R37.2; also elsewhere on the board
/Project Architecture/Microcontroller/CAN_INT: IC6.11 (INTn), TP13.1; also elsewhere on the board
/Project Architecture/Microcontroller/CAN_RST: IC6.17 (RESET), TP12.1; also elsewhere on the board
/Project Architecture/Microcontroller/SPI1_MISO: IC6.15 (MISO); also elsewhere on the board
/Project Architecture/Microcontroller/SPI1_MOSI: IC6.14 (MOSI); also elsewhere on the board
/Project Architecture/Microcontroller/SPI1_SCLK: IC6.12 (SCK); also elsewhere on the board
/Project Architecture/Microcontroller/SPI1_SCSN: IC6.16 (CSn); also elsewhere on the board
GND: C33.2, C34.2, C35.1, C80.2, C81.2, C82.2, C83.2, C84.2, D9.3 (A), IC6.8 (GND), IC6.21 (PAD), IC29.2 (GND), IC29.9 (PAD), R92.2, R94.2, X2.2; also elsewhere on the board
unnamed: C33.1, R35.2, R36.1
unnamed: IC6.20 (RXCAN), R92.1, R93.1
unnamed: IC6.19 (TXCAN), R91.1
unnamed: IC29.4 (RXD), R93.2
unnamed: IC29.8 (STB), R94.1
unnamed: IC29.1 (TXD), R91.2
VIN_PWR: C83.1, IC29.3 (VCC); also elsewhere on the board

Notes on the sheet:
MCP2515 CAN CONTROLLER
Populate R39 and R40 and remove L3, if the CMC degrades signal integrity
R35 = 60.4 Ω from CANH to the midpoint R36 = 60.4 Ω from CANL to the midpoint So differential termination is ~120.8 Ω total
TX0RTS/TX1RTS/TX2RTS are optional Request-to-Send inputs for the three transmit buffers (also configurable as generic digital inputs). Each has an internal ~100 kΩ pull-up to VDD, so when left unconnected the pin defaults to logic high and does not assert an RTS request. RX0BF/RX1BF are optional re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
CAN uses a 120 Ω termination at each end, which means the cable is roughly a 100-120 Ω differential transmission line. Choosing ~100 Ω differential routing keeps the PCB section close to the cable/termination impedance, minimizing reflections and improving edge quality/EMI (especially for CAN-FD).
C34 and C35 can also be an EMC trick, but they directly load each line to ground and can mess with signal integrity depending on layout and bitrate. 47 pF is small, so it might be fine, but it's not "standard CAN termination." If the ground they return to is noisy (digital ground), they can inject 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
If this is a mid-bus node, this termination should not be populated.
TCAN1044 CAN TRANSCIEVER
[${#}] ${TITLE}

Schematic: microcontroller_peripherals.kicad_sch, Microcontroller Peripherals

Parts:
C1, C2, C3, C4, C5, C7, C8, C9, C10, C13, C14, C15, C17, C18, C19, C21, C23: 100nF 50V; C_0402_1005Metric; LCSC_PART C307331
C6, C16: 4.7uF 25V; C_0402_1005Metric; LCSC_PART C22367824
C11, C12: 10pF 50V; C_0402_1005Metric; LCSC_PART C466222
C20, C22, C24: 4.7uF 10V; C_0402_1005Metric; LCSC_PART C368809
IC1: RP2354B; QFN80_10x10; MPN RP2354B; LCSC_PART C39843328
IC2: AT24C256C-XHL-T; TSSOP-8; MPN AT24C256C-XHL-T; LCSC_PART C33035
IC3: W25Q128JVPIQ; WSON8_6x5; MPN W25Q128JVPIQ; LCSC_PART C190862
IC4: MCP6001RT; SOT-23-5; MPN MCP6001RT-I/OT; LCSC_PART C154973
IC5: LM4040B30FTA; SOT-23; MPN LM4040B30FTA; LCSC_PART C460604
J2: SM03B-SRSS-TB; JST_SM03B-SRSS-TB_LF__SN_; MPN SM03B-SRSS-TB; LCSC_PART C160403
L1: 3.3uH 2.8A; 0805; MPN AOTA-B201610S3R3-101-T; LCSC_PART C42411119
R1, R8: 4.7K 1%; R_0402_1005Metric; LCSC_PART C25900
R2, R3, R4: 33R 1%; R_0402_1005Metric; LCSC_PART C25105
R5: 1K 1%; R_0402_1005Metric; LCSC_PART C11702
R6: 1K 1%; R_0402_1005Metric; LCSC_PART C11702; not fitted
R7: 27R 1%; R_0402_1005Metric; LCSC_PART C138021
R9: 27R 1%; R_0402_1005Metric; LCSC_PART C138021; not fitted
R10, R11: 10K 1%; R_0402_1005Metric; LCSC_PART C25744
SW1, SW2: B3U-1000P; SW_B3U-1000P; MPN B3U-1000P; LCSC_PART C231329
TP14, TP15, TP16, TP17: TestPoint_0.6mm
X1: 12MHz 10pF; X3225; MPN SX3B12.000F1010F30; LCSC_PART C2901649

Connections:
+1V1: C13.1, C14.1, C15.1, C16.1, IC1.10 (DVDD1), IC1.32 (DVDD2), IC1.51 (DVDD3), IC1.65 (VREF_FB), L1.1, TP17.1
+3.3V: C1.1, C2.1, C3.1, C4.1, C5.1, C7.1, C8.1, C9.1, C10.1, C17.1, C18.1, C20.1, IC1.5 (IOVDD1), IC1.15 (IOVDD2), IC1.24 (IOVDD3), IC1.29 (IOVDD4), IC1.41 (IOVDD5), IC1.50 (IOVDD6), IC1.60 (IOVDD7), IC1.64 (VREG_IN), IC1.68 (USB_OTP_VDD), IC1.69 (QSPI_IOVDD), IC1.76 (IOVDD8), IC2.8 (VCC), IC3.8 (VCC), R1.1, R2.1, R6.1, R7.2, R8.1, R9.2; also elsewhere on the board
/Project Architecture/Microcontroller Peripherals/ADC_VREF: R10.2, R11.1, TP14.1; also elsewhere on the board
/Project Architecture/Microcontroller Peripherals/I2C0_SCL: IC2.6 (SCL); also elsewhere on the board
/Project Architecture/Microcontroller Peripherals/I2C0_SDA: IC2.5 (SDA); also elsewhere on the board
/Project Architecture/Microcontroller Peripherals/RP_D+: IC1.67 (USB_DP), R4.2
/Project Architecture/Microcontroller Peripherals/RP_D-: IC1.66 (USB_DM), R3.1
/Project Architecture/Microcontroller Peripherals/SWCLK: IC1.33 (SWCLK), J2.1 (SWCLK)
/Project Architecture/Microcontroller Peripherals/SWDIO: IC1.34 (SWDIO), J2.3 (SWDAT)
/Project Architecture/Microcontroller Peripherals/VREF_IN: C21.1, C22.1, IC4.3 (+), IC5.1 (K), R8.2, TP16.1
/Project Architecture/Microcontroller Peripherals/VREG_AVDD: C6.1, IC1.61 (VREG_AVDD), R2.2
/Project Architecture/Microcontroller Peripherals/VREG_LX: IC1.63 (VREG_LC), L1.2
/Project Architecture/Microcontroller Peripherals/XIN: C12.1, IC1.30 (XIN), X1.3
/Project Architecture/Microcontroller Peripherals/XO: C11.1, R5.2, X1.1
/Project Architecture/Microcontroller Peripherals/XOUT: IC1.31 (XOUT), R5.1
/Project Architecture/USB Interface and Power/USB_RP_D+: R4.1; also elsewhere on the board
/Project Architecture/USB Interface and Power/USB_RP_D-: R3.2; also elsewhere on the board
GND: C1.2, C2.2, C3.2, C4.2, C5.2, C6.2, C7.2, C8.2, C9.2, C10.2, C11.2, C12.2, C13.2, C14.2, C15.2, C16.2, C17.2, C18.2, C19.2, C20.2, C21.2, C22.2, C23.2, C24.2, IC1.62 (VREG_PGND), IC1.81 (GND), IC2.1 (A0), IC2.2 (A1), IC2.3 (A2), IC2.4 (GND), IC2.7 (WP), IC3.4 (GND), IC3.9 (PAD), IC4.5 (V-), IC5.2 (A), J2.2 (GND), J2.S1 (SHIELD), J2.S2 (SHIELD), R11.2, SW1.2, SW2.2, X1.2; also elsewhere on the board
unnamed: C19.1, IC4.2 (V+), R7.1
QSPI_SCLK: IC1.71 (QSPI_SCLK), IC3.6 (CLK)
QSPI_SD0: IC1.72 (QSPI_SD0), IC3.5 (DI(IO0))
QSPI_SD1: IC1.74 (QSPI_SD1), IC3.2 (DO(IO1))
QSPI_SD2: IC1.73 (QSPI_SD2), IC3.3 (nWP(IO2))
QSPI_SD3: IC1.70 (QSPI_SD3), IC3.7 (nRST(IO3))
QSPI_SS: IC1.75 (QSPI_SS), IC3.1 (nCS), R6.2, SW1.1
RESET: IC1.35 (RUN), R1.2, SW2.1
VREF_OUT: C23.1, C24.1, IC1.59 (ADC_AVDD), IC4.1, IC4.4 (-), R9.1, R10.1, TP15.1

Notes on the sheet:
EXTERNAL EEPROM
PUSHBUTTONS
EXTERNAL FLASH
RP2354B MICROCONTROLLER
HW Design Guide: RC filter of 33Ω and 4.7μF is adequate
HW Design Guide: recommended to use 100nF capacitor per power pin
3.0V ADC VOLTAGE REFERENCE
12MHz 10pF -> Assuming 5pF parasitics Csum = 10pF - 5pF = 5pF C1 = C2 = 5pF x 2 = 10pF
[${#}] ${TITLE}

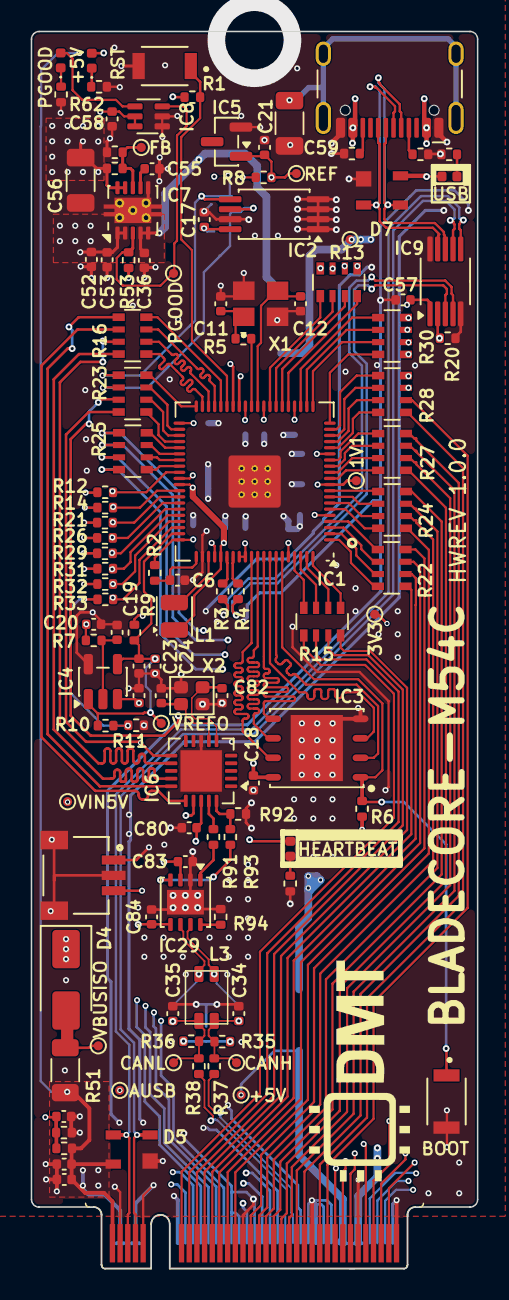
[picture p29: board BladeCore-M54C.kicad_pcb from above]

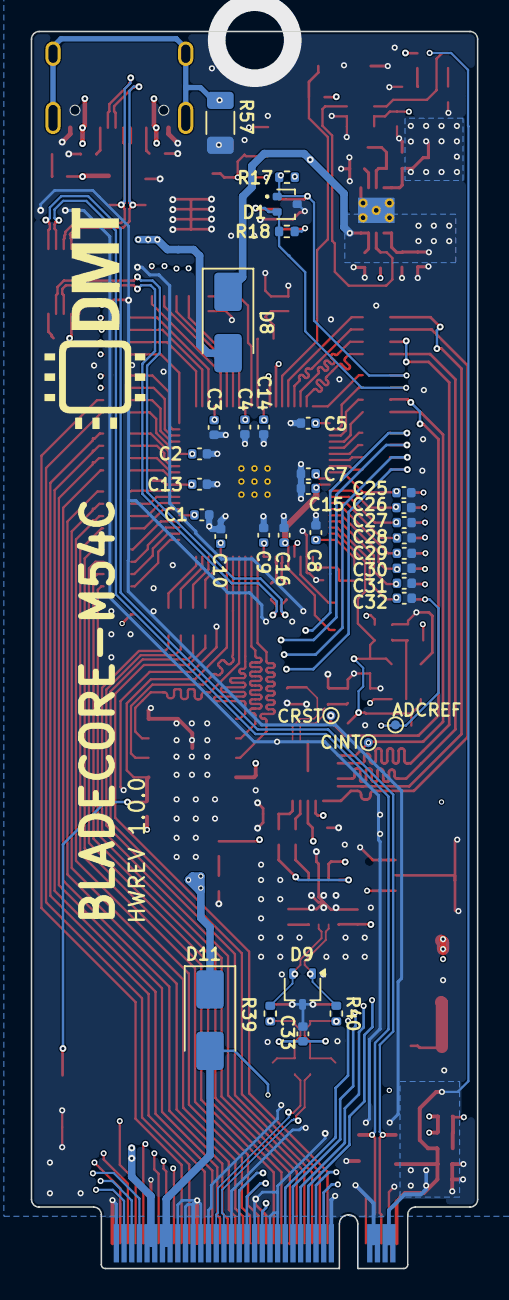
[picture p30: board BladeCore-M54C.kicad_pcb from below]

Board: 6 copper layers, 29.0 x 80.6 mm, 152 parts (34 on the bottom side), 154 nets.

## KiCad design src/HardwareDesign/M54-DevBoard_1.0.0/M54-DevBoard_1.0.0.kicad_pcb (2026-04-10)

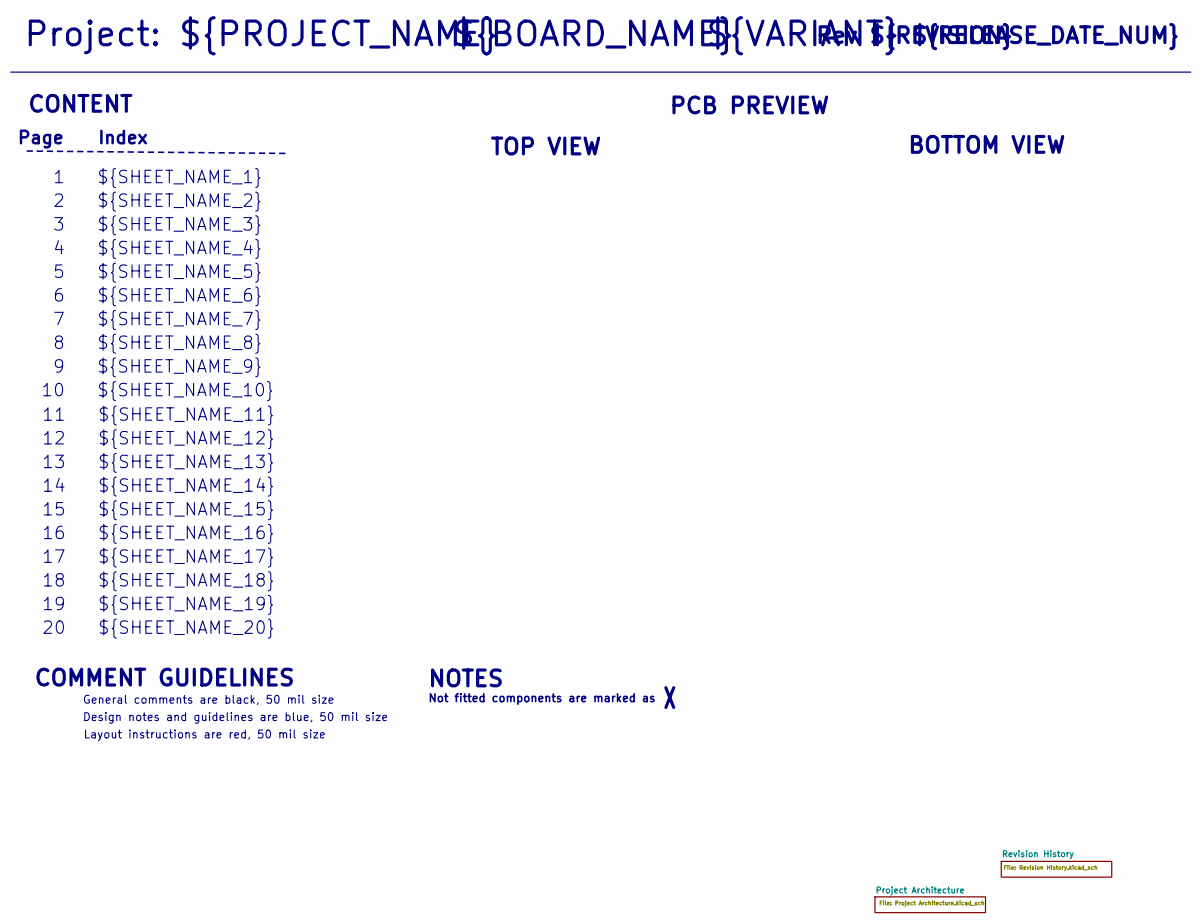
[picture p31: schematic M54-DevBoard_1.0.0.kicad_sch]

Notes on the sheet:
${SHEET_NAME_12}
${SHEET_NAME_8}
${SHEET_NAME_2}
${SHEET_NAME_5}
${SHEET_NAME_20}
Page
PCB PREVIEW
${RELEASE_DATE_NUM}
CONTENT
${SHEET_NAME_11}
${SHEET_NAME_6}
Rev ${REVISION}
${SHEET_NAME_15}
BOTTOM VIEW
${SHEET_NAME_14}
${SHEET_NAME_17}
${SHEET_NAME_18}
${SHEET_NAME_7}
Not fitted components are marked as
Project: ${PROJECT_NAME}
NOTES
Design notes and guidelines are blue, 50 mil size
${SHEET_NAME_1}
${SHEET_NAME_9}
${BOARD_NAME}
General comments are black, 50 mil size
${SHEET_NAME_16}
${SHEET_NAME_3}
${VARIANT}
${SHEET_NAME_19}
TOP VIEW
${SHEET_NAME_10}
Index
${SHEET_NAME_13}
${SHEET_NAME_4}
COMMENT GUIDELINES
Layout instructions are red, 50 mil size

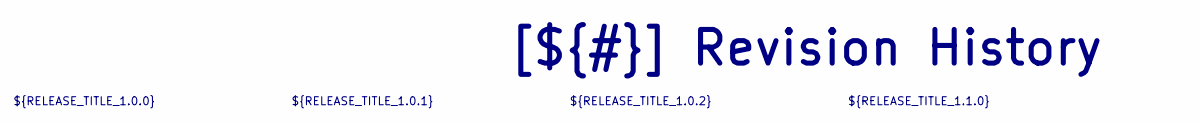
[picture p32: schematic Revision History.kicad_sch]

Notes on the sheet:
[${#}] ${TITLE}
${RELEASE_TITLE_1.0.2}
${RELEASE_TITLE_1.0.0}
${RELEASE_TITLE_1.0.1}
${RELEASE_TITLE_1.1.0}


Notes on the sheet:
VIN = 10V to 20V
LEVEL SHIFTER ADC BUFFER
CAN DB9
USB-B
GPIO 8-15 GPIO 24-39 GPIO 0-7 GPIO 16-23 POWER ADC0-5
GPIO 3.3V/5V
GPIO
[${#}] ${TITLE}

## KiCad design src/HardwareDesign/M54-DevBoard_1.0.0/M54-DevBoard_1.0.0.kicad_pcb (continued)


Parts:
C1, C3, C4, C5, C6, C7, C8, C9, C10, C11, C12, C13, C14, C15, C16, C18, C29: 100nF 50V; C_0603_1608Metric; LCSC_PART C14663
D2, D5, D8, D10: Orange; LED_0805_2012Metric; MPN XL-2012UOC; LCSC_PART C965813
D3, D4, D6, D9: Red; LED_0805_2012Metric; MPN XL-2012VRC; LCSC_PART C7371913
D15: Green; LED_0805_2012Metric; MPN XL-2012UGC; LCSC_PART C965815
D16: SMA
IC1, IC2, IC3, IC4: TXS0108EPWR; TSSOP-20_4.4x6.5_P0.65mm; MPN TXS0108EPWR; LCSC_PART C17206
IC5, IC7, IC8, IC9, IC10, IC11, IC13: OPA365AQDBVRQ1; SOT-23-5; MPN OPA365AQDBVRQ1; LCSC_PART C485978
IC20, IC21: LM397; SOT-23-5
J11: PINHD_1x3_Male; PinHeader_1x03_P2.54mm_Vertical
R1: 10K 1%; R_0805_2012Metric; LCSC_PART C17414
R3, R4, R7, R8, R9, R10, R11, R12, R22: 1K 1%; R_0603_1608Metric; LCSC_PART C21190
R5: 15K 1%; R_0603_1608Metric; LCSC_PART C22809
R6, R24, R25, R26, R27: 10K 1%; R_0603_1608Metric; LCSC_PART C25804
T2, T3, T4, T5, T6, T7, T8, T9: BSS138LT1G; SOT-23; MPN BSS138LT1G
TP10, TP11, TP12: TestPoint_0.6mm

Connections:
3.3V_LED: IC21.4, R27.2, T3.1, T4.1, T6.1, T8.1
5V_LED: IC20.4, R26.2, T2.1, T5.1, T7.1, T9.1
+3.3V: C1.1, C3.1, C4.1, C5.1, C18.1, D16.2 (A), IC1.2 (VCCA), IC2.2 (VCCA), IC3.2 (VCCA), IC4.2 (VCCA), IC13.5 (V+), J11.3, TP12.1; also elsewhere on the board
+5V: C10.1, C11.1, C12.1, C13.1, C14.1, C15.1, C16.1, C29.1, IC5.5 (V+), IC7.5 (V+), IC8.5 (V+), IC9.5 (V+), IC10.5 (V+), IC11.5 (V+), IC20.5 (V+), IC21.5 (V+), J11.1, R3.1, R4.1, R5.1, R7.1, R8.1, R9.1, R10.1, R11.1, R12.1, R26.1, R27.1; also elsewhere on the board
ADC0: IC5.1, IC5.4 (-); also elsewhere on the board
ADC0C: IC5.3 (+); also elsewhere on the board
ADC1: IC7.1, IC7.4 (-); also elsewhere on the board
ADC1C: IC7.3 (+); also elsewhere on the board
ADC2: IC8.1, IC8.4 (-); also elsewhere on the board
ADC2C: IC8.3 (+); also elsewhere on the board
ADC3: IC9.1, IC9.4 (-); also elsewhere on the board
ADC3C: IC9.3 (+); also elsewhere on the board
ADC4: IC10.1, IC10.4 (-); also elsewhere on the board
ADC4C: IC10.3 (+); also elsewhere on the board
ADC5: IC11.1, IC11.4 (-); also elsewhere on the board
ADC5C: IC11.3 (+); also elsewhere on the board
GND: C1.2, C3.2, C4.2, C5.2, C6.2, C7.2, C8.2, C9.2, C10.2, C11.2, C12.2, C13.2, C14.2, C15.2, C16.2, C18.2, C29.2, IC1.11 (GND), IC2.11 (GND), IC3.11 (GND), IC4.11 (GND), IC5.2 (V-), IC7.2 (V-), IC8.2 (V-), IC9.2 (V-), IC10.2 (V-), IC11.2 (V-), IC13.2 (V-), IC20.2 (V-), IC21.2 (V-), R1.2, R6.2, R22.2, R25.2, T2.2, T3.2, T4.2, T5.2, T6.2, T7.2, T8.2, T9.2; also elsewhere on the board
GPIO0: IC1.1 (A1); also elsewhere on the board
GPIO0C: IC1.20 (B1); also elsewhere on the board
GPIO1: IC1.3 (A2); also elsewhere on the board
GPIO1C: IC1.18 (B2); also elsewhere on the board
GPIO2: IC1.4 (A3); also elsewhere on the board
GPIO2C: IC1.17 (B3); also elsewhere on the board
GPIO3: IC1.5 (A4); also elsewhere on the board
GPIO3C: IC1.16 (B4); also elsewhere on the board
GPIO4: IC1.6 (A5); also elsewhere on the board
GPIO4C: IC1.15 (B5); also elsewhere on the board
GPIO5: IC1.7 (A6); also elsewhere on the board
GPIO5C: IC1.14 (B6); also elsewhere on the board
GPIO6: IC1.8 (A7); also elsewhere on the board
GPIO6C: IC1.13 (B7); also elsewhere on the board
GPIO7: IC1.9 (A8); also elsewhere on the board
GPIO7C: IC1.12 (B8); also elsewhere on the board
GPIO8: IC2.1 (A1); also elsewhere on the board
GPIO8C: IC2.20 (B1); also elsewhere on the board
GPIO9: IC2.3 (A2); also elsewhere on the board
GPIO9C: IC2.18 (B2); also elsewhere on the board
GPIO10: IC2.4 (A3); also elsewhere on the board
GPIO10C: IC2.17 (B3); also elsewhere on the board
GPIO11: IC2.5 (A4); also elsewhere on the board
GPIO11C: IC2.16 (B4); also elsewhere on the board
GPIO12: IC2.6 (A5); also elsewhere on the board
GPIO12C: IC2.15 (B5); also elsewhere on the board
GPIO13: IC2.7 (A6); also elsewhere on the board
GPIO13C: IC2.14 (B6); also elsewhere on the board
GPIO14: IC2.8 (A7); also elsewhere on the board
GPIO14C: IC2.13 (B7); also elsewhere on the board
GPIO15: IC2.9 (A8); also elsewhere on the board
GPIO15C: IC2.12 (B8); also elsewhere on the board
GPIO16: IC3.1 (A1); also elsewhere on the board
GPIO16C: IC3.20 (B1); also elsewhere on the board
GPIO17: IC3.3 (A2); also elsewhere on the board
GPIO17C: IC3.18 (B2); also elsewhere on the board
GPIO18: IC3.4 (A3); also elsewhere on the board
GPIO18C: IC3.17 (B3); also elsewhere on the board
GPIO19: IC3.5 (A4); also elsewhere on the board
GPIO19C: IC3.16 (B4); also elsewhere on the board
GPIO20: IC3.6 (A5); also elsewhere on the board
GPIO20C: IC3.15 (B5); also elsewhere on the board
GPIO21: IC3.7 (A6); also elsewhere on the board
GPIO21C: IC3.14 (B6); also elsewhere on the board
GPIO22: IC3.8 (A7); also elsewhere on the board
GPIO22C: IC3.13 (B7); also elsewhere on the board
GPIO23: IC3.9 (A8); also elsewhere on the board
GPIO23C: IC3.12 (B8); also elsewhere on the board
GPIO24: IC4.8 (A7); also elsewhere on the board
GPIO24C: IC4.13 (B7); also elsewhere on the board
GPIO25: IC4.7 (A6); also elsewhere on the board
GPIO25C: IC4.14 (B6); also elsewhere on the board
GPIO26: IC4.6 (A5); also elsewhere on the board
GPIO26C: IC4.15 (B5); also elsewhere on the board
GPIO27: IC4.5 (A4); also elsewhere on the board
GPIO27C: IC4.16 (B4); also elsewhere on the board
GPIO37: IC4.4 (A3); also elsewhere on the board
GPIO37C: IC4.17 (B3); also elsewhere on the board
GPIO38: IC4.3 (A2); also elsewhere on the board
GPIO38C: IC4.18 (B2); also elsewhere on the board
GPIO39: IC4.1 (A1); also elsewhere on the board
GPIO39C: IC4.20 (B1); also elsewhere on the board
unnamed: D2.1, T8.3
unnamed: D2.2, R4.2
unnamed: D3.1, T9.3
unnamed: D3.2, R3.2
unnamed: D4.1, T7.3
unnamed: D4.2, R8.2
unnamed: D5.1, T6.3
unnamed: D5.2, R7.2
unnamed: D6.1, T5.3
unnamed: D6.2, R10.2
unnamed: D8.1, T4.3
unnamed: D8.2, R9.2
unnamed: D9.1, T2.3
unnamed: D9.2, R12.2
unnamed: D10.1, T3.3
unnamed: D10.2, R11.2
unnamed: D15.1, R22.1
unnamed: D15.2, IC13.1, IC13.4 (-)
OE: D16.1 (K), IC1.10 (OE), IC2.10 (OE), IC3.10 (OE), IC4.10 (OE), IC13.3 (+), R1.1, TP10.1
VDD: C6.1, C7.1, C8.1, C9.1, IC1.19 (VCCB), IC2.19 (VCCB), IC3.19 (VCCB), IC4.19 (VCCB), J11.2, R24.1, TP11.1; also elsewhere on the board
VDD_SENSE: IC20.3 (+), IC21.1 (-), R24.2, R25.1
VREF: IC20.1 (-), IC21.3 (+), R5.2, R6.1

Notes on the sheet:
2.0V
Simple comparator. VREF = 2.0V If VDD > VREF -> HiZ If VDD < VREF -> LOW
VDD LEVEL SELECTOR AND COMPARATOR
GPIO LEVEL SHIFTERS
1.65V
2.5V
ADC INPUT BUFFERS
V+ > V- (2.0V > 1.65V) -> HiZ -> Tgate = High -> 3.3V LED ON V+ < V- (2.0V < 2.5V) -> LOW -> Tgate = LOW -> 3.3V LED OFF
V+ > V- (2.5V > 2.0V) -> HiZ -> Tgate = High -> 5V LED ON V+ < V- (1.65V < 2.0V) -> LOW -> Tgate = LOW -> 5V LED OFF
[${#}] ${TITLE}


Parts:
C17: 100uF 50V; C_Elec_6.3x7.7; MPN RVT1H101M0607; LCSC_PART C3151829
C19: 330uF 50V; CP_Elec_10x10.5; MPN EEE-FT1H331AP; LCSC_PART C178596
C20, C24, C25, C26, C27, C28: 10uF 50V; C_1206_3216Metric; MPN CL31A106KBHNNNE; LCSC_PART C13585
C21, C23: 100nF 50V; C_0603_1608Metric; LCSC_PART C14663
C22: 150pF 50V; C_0603_1608Metric; MPN 0603B151K500NT; LCSC_PART C1594
C59: 1nF 2kV; C_1206_3216Metric; LCSC_PART C173242
D1: Blue; LED_0603_1608Metric; MPN XL-2012UBC; LCSC_PART C965817
D7: SP0503BAHTG; SOT143; MPN SP0503BAHTG; LCSC_PART C3040626
D11: SMAZ15-13-F; SMA; MPN SMAZ15-13-F; LCSC_PART C110524
D12: CMSH3-40MA; SMA; MPN CMSH3-40MA TR13 PBFREE; LCSC_PART C48937470
D13: Red; LED_0805_2012Metric; MPN XL-2012VRC; LCSC_PART C7371913
IC12: MP4462DN-LF-Z; SO-8_3.9x4.9mm_EP2.6x3.5mm; MPN MCP1754ST-3302E/MB; LCSC_PART C28398
J8: USB-B-S-F-B-TH; USB_B_Lumberg_2411_02_Horizontal; MPN USB-B-S-F-B-TH; LCSC_PART C5714571
J9: PJ-102AH; BarrelJack_CUI_PJ-102AH_Horizontal; MPN PJ-102AH; LCSC_PART C3096093
J10: 1888687; TerminalBlock_Phoenix_PT-1,5-2-5.0-H_1x02_P5.00mm_Horizontal
L1: 15uH 4.2A; L_12x12x6_WE-PD-1260; MPN 744771115; LCSC_PART C2049359
R13: 10K 1%; R_0805_2012Metric; LCSC_PART C17414
R14, R16, R17: 100K 1%; R_0603_1608Metric; LCSC_PART C25803
R15: 24.9K 1%; R_0603_1608Metric; LCSC_PART C2930080
R18: 40.2K 1%; R_0603_1608Metric; LCSC_PART C12447
R19: 210K 1%; R_0603_1608Metric; MPN 0603WAF2103T5E; LCSC_PART C22952
R20: 1K 1%; R_0603_1608Metric; LCSC_PART C21190
R41: 1K 1%; R_0402_1005Metric; LCSC_PART C11702
R57: 1M 1%; R_1206_3216Metric; LCSC_PART C17927
SHIELD1: SHIELD
T1: SQJ459EP-T1_GE3; PowerPAK SO-8; MPN SQJ459EP-T1_GE3; LCSC_PART C3289501
TP1, TP2, TP3, TP4, TP5, TP6, TP7, TP8, TP9: TestPoint_0.6mm

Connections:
+5V: C24.1, C25.1, C28.1, L1.2, R19.1, R20.1, TP4.1; also elsewhere on the board
/Project Architecture/Bladecore M54C/USB_D_N: D7.3, J8.2 (D-); also elsewhere on the board
/Project Architecture/Bladecore M54C/USB_D_P: D7.2, J8.3 (D+); also elsewhere on the board
/Project Architecture/USB and Power/BUCK_COMP: C22.1, IC12.3 (COMP)
/Project Architecture/USB and Power/BUCK_EN: IC12.2 (EN), R14.2, R15.1, TP2.1
/Project Architecture/USB and Power/BUCK_FREQ: IC12.6 (FREQ), R16.1
/Project Architecture/USB and Power/SW: C23.2, D12.1 (K), IC12.1 (SW), L1.1
/Project Architecture/USB and Power/USB_IND: D1.1, R41.2
/Project Architecture/USB and Power/VIN_14V_PROT: C19.1, C20.1, C21.1, D11.1 (K), IC12.7 (VIN), R14.1, T1.1 (S), T1.2 (S), T1.3 (S), TP1.1
GND: C17.2, C19.2, C20.2, C21.2, C24.2, C25.2, C26.2, C27.2, C28.2, C59.2, D7.1, D12.2 (A), D13.1, IC12.5 (GND), IC12.9 (EP), J8.4 (GND), J9.2, J9.3, J10.2, R13.2, R15.2, R16.2, R17.2, R18.2, R41.1, R57.2, TP6.1, TP8.1; also elsewhere on the board
unnamed: C22.2, R17.1
unnamed: D11.2 (A), R13.1, T1.4 (G), TP7.1
unnamed: D13.2, R20.2
unnamed: C23.1, IC12.8 (BST)
unnamed: IC12.4 (FB), R18.1, R19.2, TP3.1
VBUS: C17.1, C26.1, C27.1, D1.2, D7.4, J8.1 (VBUS), TP5.1; also elsewhere on the board
VIN: J9.1, J10.1, T1.5 (D), T1.6 (D), T1.7 (D), T1.8 (D), TP9.1; also elsewhere on the board

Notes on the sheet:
Recommended for 5V: 15-22uH + 22uF
10V-36V to 5V 3A BUCK
INPUT SUPPLY WITH REVERSE POLARITY PROTECTION
100K = 1MHz switching freq
or B340A-13-F
USB CONNECTOR
Recommended for 5V: 150pF - 100K
[${#}] ${TITLE}


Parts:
C2: 1nF 2kV; C_1206_3216Metric; LCSC_PART C173242
D14: Green; LED_0805_2012Metric; MPN XL-2012UGC; LCSC_PART C965815
H1, H2, H3, H4: MountingHole_Pad; MountingHole_3.2mm_M3_Pad_Via
J1: MDT580M01001; BladeCore-M54C; MPN MDT580M01001; LCSC_PART C5177196
J2, J3, J4, J5, J6, J7: PINHD_1x10_Female; PinSocket_1x10_P2.54mm_Vertical
J12: DE9_Socket_MountingHoles; DSUB-9_Socket_Horizontal_P2.77x2.84mm_EdgePinOffset7.70mm_H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
R2: 1M 1%; R_1206_3216Metric; LCSC_PART C17927
R21: 1K 1%; R_0603_1608Metric; LCSC_PART C21190
SHIELD2: SHIELD
ST1: M2.5; Round Standoff Threaded M2.5 Steel; MPN 9774045151R; LCSC_PART C7435234

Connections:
+3.3V: J1.10 (3V3_OUT), J1.12 (3V3_OUT), J7.4, R21.1; also elsewhere on the board
+5V: J1.14 (5VIN), J1.16 (5VIN); also elsewhere on the board
/Project Architecture/Bladecore M54C/USB_D_N: J1.71 (USB_D-); also elsewhere on the board
/Project Architecture/Bladecore M54C/USB_D_P: J1.69 (USB_D+); also elsewhere on the board
ADC0: J1.46 (ADC0); also elsewhere on the board
ADC0C: J5.3; also elsewhere on the board
ADC1: J1.48 (ADC1); also elsewhere on the board
ADC1C: J5.4; also elsewhere on the board
ADC2: J1.50 (ADC2); also elsewhere on the board
ADC2C: J5.5; also elsewhere on the board
ADC3: J1.52 (ADC3); also elsewhere on the board
ADC3C: J5.6; also elsewhere on the board
ADC4: J1.54 (ADC4); also elsewhere on the board
ADC4C: J5.7; also elsewhere on the board
ADC5: J1.56 (ADC5); also elsewhere on the board
ADC5C: J5.8; also elsewhere on the board
CAN_N: J1.30 (CAN_L), J7.9, J12.2
CAN_P: J1.28 (CAN_H), J7.8, J12.7
GND: C2.1, D14.1, H1.1 (1_1), H2.1 (1_1), H3.1 (1_1), H4.1 (1_1), J1.1 (GND), J1.2 (GND), J1.11 (GND), J1.18 (GND), J1.20 (GND), J1.22 (GND), J1.23 (GND), J1.24 (GND), J1.26 (GND), J1.32 (GND), J1.38 (GND), J1.41 (GND), J1.42 (GND), J1.44 (GND), J1.58 (GND), J1.67 (GND), J1.68 (GND), J1.70 (GND), J1.73 (GND), J1.SH1 (SHIELD), J1.SH2 (SHIELD), J2.10, J3.10, J4.10, J5.2, J5.9, J5.10, J6.9, J6.10, J7.7, J7.10, J12.3, J12.6, R2.1, ST1.1; also elsewhere on the board
GPIO0: J1.57 (GPIO0); also elsewhere on the board
GPIO0C: J2.9; also elsewhere on the board
GPIO1: J1.55 (GPIO1); also elsewhere on the board
GPIO1C: J2.8; also elsewhere on the board
GPIO2: J1.53 (GPIO2); also elsewhere on the board
GPIO2C: J2.7; also elsewhere on the board
GPIO3: J1.51 (GPIO3); also elsewhere on the board
GPIO3C: J2.6; also elsewhere on the board
GPIO4: J1.49 (GPIO4); also elsewhere on the board
GPIO4C: J2.5; also elsewhere on the board
GPIO5: J1.47 (GPIO5); also elsewhere on the board
GPIO5C: J2.4; also elsewhere on the board
GPIO6: J1.45 (GPIO6); also elsewhere on the board
GPIO6C: J2.3; also elsewhere on the board
GPIO7: J1.43 (GPIO7); also elsewhere on the board
GPIO7C: J2.2; also elsewhere on the board
GPIO8: J1.39 (GPIO8); also elsewhere on the board
GPIO8C: J3.9; also elsewhere on the board
GPIO9: J1.37 (GPIO9); also elsewhere on the board
GPIO9C: J3.8; also elsewhere on the board
GPIO10: J1.35 (GPIO10); also elsewhere on the board
GPIO10C: J3.7; also elsewhere on the board
GPIO11: J1.33 (GPIO11); also elsewhere on the board
GPIO11C: J3.6; also elsewhere on the board
GPIO12: J1.31 (GPIO12); also elsewhere on the board
GPIO12C: J3.5; also elsewhere on the board
GPIO13: J1.29 (GPIO13); also elsewhere on the board
GPIO13C: J3.4; also elsewhere on the board
GPIO14: J1.27 (GPIO14); also elsewhere on the board
GPIO14C: J3.3; also elsewhere on the board
GPIO15: J1.25 (GPIO15); also elsewhere on the board
GPIO15C: J3.2; also elsewhere on the board
GPIO16: J1.21 (GPIO16); also elsewhere on the board
GPIO16C: J4.2; also elsewhere on the board
GPIO17: J1.19 (GPIO17); also elsewhere on the board
GPIO17C: J4.3; also elsewhere on the board
GPIO18: J1.17 (GPIO18); also elsewhere on the board
GPIO18C: J4.4; also elsewhere on the board
GPIO19: J1.15 (GPIO19); also elsewhere on the board
GPIO19C: J4.5; also elsewhere on the board
GPIO20: J1.13 (GPIO20); also elsewhere on the board
GPIO20C: J4.6; also elsewhere on the board
GPIO21: J1.9 (GPIO21); also elsewhere on the board
GPIO21C: J4.7; also elsewhere on the board
GPIO22: J1.7 (GPIO22); also elsewhere on the board
GPIO22C: J4.8; also elsewhere on the board
GPIO23: J1.5 (GPIO23); also elsewhere on the board
GPIO23C: J4.9; also elsewhere on the board
GPIO24: J1.3 (GPIO24); also elsewhere on the board
GPIO24C: J6.8; also elsewhere on the board
GPIO25: J1.8 (GPIO25); also elsewhere on the board
GPIO25C: J6.7; also elsewhere on the board
GPIO26: J1.6 (GPIO26); also elsewhere on the board
GPIO26C: J6.6; also elsewhere on the board
GPIO27: J1.4 (GPIO27); also elsewhere on the board
GPIO27C: J6.5; also elsewhere on the board
GPIO37: J1.34 (GPIO37); also elsewhere on the board
GPIO37C: J6.4; also elsewhere on the board
GPIO38: J1.36 (GPIO38); also elsewhere on the board
GPIO38C: J6.3; also elsewhere on the board
GPIO39: J1.40 (GPIO39); also elsewhere on the board
GPIO39C: J6.2; also elsewhere on the board
unnamed: D14.2, R21.2
VBUS: J1.72 (VBUS), J1.74 (VBUS), J1.75 (VBUS), J7.3; also elsewhere on the board
VDD: J2.1, J3.1, J4.1, J5.1, J6.1, J7.1, J7.2; also elsewhere on the board
VIN: J7.5, J7.6; also elsewhere on the board

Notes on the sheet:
MOUNTING HOLES
BLADECORE-M54C SOCKET
GPIO HEADERS
CAN DB9 CONNECTOR
[${#}] ${TITLE}

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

Board: 4 copper layers, 66.0 x 147.0 mm, 127 parts (0 on the bottom side), 120 nets.

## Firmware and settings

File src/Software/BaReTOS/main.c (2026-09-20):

/**
 * @file src/Software/BaReTOS/main.c
 *
 * @version 1.0.0
 * @date 2026-09-18
 *
 * @details
 * Starts the generated BaReTOS project with the two requested application tasks: Heartbeat at
 * the minimum scheduler priority and a higher-priority CAN listener. Initialises the board
 * clock and silicon identity before checking both task allocations and starting FreeRTOS. The
 * watchdog is serviced only when both tasks make progress. Fault hooks request reset rather
 * than continuing with an invalid scheduler state.
 *
 * @project BaReTOS - BladeCore-M54C firmware
 * @github https://github.com/DvidMakesThings/HW_BladeCore-M54C
 */
#include "CONFIG.h"
#include "application.h"
#include "pico/stdlib.h"
#include "hardware/clocks.h"
#include "hardware/watchdog.h"
#include <string.h>

volatile application_diagnostics_t bare_diag; /**< Runtime diagnostic state. */
TaskHandle_t can_task_handle;                 /**< Handle assigned before the scheduler starts. */

/**
 * @brief Reset following a failed runtime assertion.
 *
 * @param[in] file Source filename reporting the failure.
 * @param[in] line Source line reporting the failure.
 * @return None (void); this function never returns.
 *
 * @details
 * Disables task interrupts and requests a short watchdog reset instead of continuing with a
 * potentially corrupted scheduler state. The source location is supplied by configASSERT and
 * remains available to a debugger at the call site. The function then stays in a tight loop
 * until reset; it must never return to the failed operation.
 */
void vAssertCalled(const char *file, int line)
{
    (void)file;
    (void)line;
    taskDISABLE_INTERRUPTS();
    watchdog_reboot(0, 0, FAULT_RESET_DELAY_MS);
    while (true)
    {
        tight_loop_contents();
    }
}

/**
 * @brief Reset when FreeRTOS detects a task stack overflow.
 *
 * @param[in] task Task whose stack failed validation.
 * @param[in] name Name of the affected task.
 * @return None (void); delegates to the non-returning assertion handler.
 *
 * @details
 * Receives the task handle and name supplied by the FreeRTOS stack-overflow check. It forwards
 * the failure to the common assertion handler, which disables interrupts and resets the MCU.
 * No allocation, logging, or further task processing is attempted on a potentially corrupted
 * stack.
 */
void vApplicationStackOverflowHook(TaskHandle_t task, char *name)
{
    (void)task;
    vAssertCalled(name, 0);
}

/**
 * @brief Reset when the FreeRTOS heap cannot satisfy an allocation.
 *
 * @par Parameters
 * None (void).
 * @return None (void); delegates to the non-returning assertion handler.
 *
 * @details
 * Handles failure of a FreeRTOS dynamic allocation by entering the common reset path. The hook
 * avoids any additional heap use. Task creation in main is also checked explicitly so the
 * scheduler cannot start without both required tasks.
 */
void vApplicationMallocFailedHook(void)
{
    vAssertCalled("heap", 0);
}

/**
 * @brief Initialise board state, create both tasks, and start FreeRTOS.
 *
 * @par Parameters
 * None (void).
 * @return Does not return during normal operation; scheduler failure causes reset.
 *
 * @details
 * Initialises board clock, heartbeat GPIO, and the full silicon identifier before allocating
 * Heartbeat and CAN tasks. Both allocation results are checked. The scheduler starts only
 * after the watchdog is enabled, and any unexpected scheduler return enters the common fault-
 * reset path.
 */
int main(void)
{
    uint8_t identity[8]; /**< Full silicon identifier fetched before scheduling. */
    set_sys_clock_khz(SYSTEM_CLOCK_KHZ, true);
    gpio_init(PIN_HEARTBEAT);
    gpio_set_dir(PIN_HEARTBEAT, GPIO_OUT);
    bare_diag.node = board_identity(identity);
    memcpy((void *)bare_diag.uid, identity, sizeof(identity));

    /* Validate allocations before enabling the task-supervised watchdog. */
    configASSERT(xTaskCreate(init_task, "Init", INIT_STACK_WORDS, NULL, INIT_TASK_PRIORITY, NULL) ==
                 pdPASS);
    configASSERT(xTaskCreate(heartbeat_task, "Heartbeat", HEARTBEAT_STACK_WORDS, NULL,
                             HEARTBEAT_TASK_PRIORITY, NULL) == pdPASS);
    configASSERT(xTaskCreate(can_task, "CAN", CAN_STACK_WORDS, NULL, CAN_TASK_PRIORITY,
                             &can_task_handle) == pdPASS);
    configASSERT(xTaskCreate(example_task, "Example", EXAMPLE_STACK_WORDS, NULL,
                             EXAMPLE_TASK_PRIORITY, NULL) == pdPASS);
    watchdog_enable(WATCHDOG_TIMEOUT_MS, true);
    vTaskStartScheduler();
    vAssertCalled("scheduler", 0);
    return 0;
}

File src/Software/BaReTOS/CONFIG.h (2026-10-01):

/**
 * @file src/Software/BaReTOS/CONFIG.h
 *
 * @version 1.0.0
 * @date 2026-09-18
 *
 * @details
 * Owns the board pin map, peripheral instances, application task priorities and timing, CAN
 * protocol identifiers, and application flash-layout macros for BladeCore-M54C, so the firmware
 * and host tools share one configuration source. FreeRTOS kernel configuration lives separately
 * in FreeRTOSConfig.h. This file is macro-only and safe for the Pico SDK board adapter's
 * assembler preprocessing.
 *
 * @project BaReTOS - BladeCore-M54C firmware
 * @github https://github.com/DvidMakesThings/HW_BladeCore-M54C
 */

#pragma once
#include "FreeRTOSConfig.h"

/* -------------------------------------------------------------------------- */
/*  CAN bus speed selector                                                    */
/* -------------------------------------------------------------------------- */
#define CAN_SPEED_1M 1000u
#define CAN_SPEED_500K 500u
#define CAN_SPEED_250K 250u
#define CAN_SPEED_125K 125u
#define CAN_SPEED CAN_SPEED_500K /**< Active CAN bitrate in kbit/s. */

/* -------------------------------------------------------------------------- */
/*  MCP2515 CAN Controller (SPI1)                                             */
/* -------------------------------------------------------------------------- */
#define PIN_CAN_MISO 28 /**< SPI1 RX  - MCP2515 SO             */
#define PIN_CAN_CS 29   /**< SPI1 CSn - MCP2515 CS (active low)*/
#define PIN_CAN_SCK 30  /**< SPI1 SCK - MCP2515 SCK            */
#define PIN_CAN_MOSI 31 /**< SPI1 TX  - MCP2515 SI             */

/* -------------------------------------------------------------------------- */
/*  I2C0 - Onboard EEPROM (AT24C256) + M.2 connector                         */
/* -------------------------------------------------------------------------- */
#define PIN_I2C0_SDA 32 /**< I2C0 data  (4.7K pull-up)         */
#define PIN_I2C0_SCL 33 /**< I2C0 clock (4.7K pull-up)         */

/* -------------------------------------------------------------------------- */
/*  MCP2515 CAN Control                                                       */
/* -------------------------------------------------------------------------- */
#define PIN_CAN_RST 34 /**< MCP2515 hardware reset (active low)*/
#define PIN_CAN_INT 35 /**< MCP2515 interrupt (active low)    */

/* -------------------------------------------------------------------------- */
/*  Onboard Heartbeat LED                                                     */
/* -------------------------------------------------------------------------- */
#define PIN_HEARTBEAT 36 /**< Blue LED, 100R series resistor    */

/* -------------------------------------------------------------------------- */
/*  ADC - Onboard                                                             */
/* -------------------------------------------------------------------------- */
#define PIN_ADC_VUSB 46 /**< GPIO46/ADC6 - USB VBUS sense (5.1K-5.1K divider) */
#define PIN_ADC_VREF 47 /**< GPIO47/ADC7 - 3.00V 0.1% ref (10K-10K divider)   */
/** @brief Measured true voltage at the VREF ADC pin (3.004 V ref through the 2:1 divider). */
#define ADC_CAL_PIN_MV 1500u
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

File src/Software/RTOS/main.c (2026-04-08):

/*
 * main.c - BladeCore-M54C PCAN adapter firmware entry point (FreeRTOS)
 *
 * Startup sequence:
 *   1. Check for bootloader trigger (magic word from previous USB/CAN request)
 *   2. Initialize USB device task (TinyUSB + PCAN custom class)
 *   3. Initialize CAN bridge tasks (MCP2515 TX/RX via SPI)
 *   4. Initialize heartbeat LED task
 *   5. Start FreeRTOS scheduler
 */

#include "CONFIG.h"
#include "bootloader/bootloader.h"
#include "hal/can_bridge.h"
#include "usb/pcan_protocol.h"
#include "tusb.h"

#include "FreeRTOS.h"
#include "task.h"

#include "pico/stdlib.h"
#include "hardware/watchdog.h"
#include "hardware/gpio.h"
#include "hardware/clocks.h"
#include "hardware/timer.h"

/* Watchdog timeout: 2 seconds.  Fed from the USB task every iteration.
 * If the firmware hangs (assert, deadlock, stack overflow), the watchdog
 * will reboot the device automatically instead of staying stuck. */
#define WATCHDOG_TIMEOUT_MS 2000

/* USB layer function (defined in pcan_usb_class.c) */
extern bool pcan_usb_send_rx_msg(const uint8_t *buf, uint16_t len);

/* -------------------------------------------------------------------------- */
/*  USB device task                                                            */
/* -------------------------------------------------------------------------- */
static void usb_device_task(void *param)
{
    (void)param;
    tusb_rhport_init_t dev_init = {
        .role = TUSB_ROLE_DEVICE,
        .speed = TUSB_SPEED_AUTO};
    tusb_init(0, &dev_init);

    /* Start watchdog now that the scheduler is running and we can feed it.
     * Must be after tusb_init so the USB enumeration window is covered. */
    watchdog_enable(WATCHDOG_TIMEOUT_MS, true);

    for (;;)
    {
        /* Process any pending USB events without blocking.
         * tud_task() blocks forever (starves CAN RX poll).
         * tud_task_ext(1, false) breaks EP1 OUT on RP2350.
         * Instead: check if events are ready, process them with
         * timeout=0, then do our periodic work and yield. */
        while (tud_task_event_ready())
        {
            tud_task_ext(0, false);
        }

        /* Reconfigure MCP2515 on bus-on transition */
        static bool s_was_bus_on = false;
        bool bus_on_now = pcan_is_bus_on();

        if (bus_on_now && !s_was_bus_on)
        {
            can_bridge_reconfigure();

            /* Send timesync event on EP2 IN.  This initializes the
             * host driver's internal timestamp reference.  The real
             * PCAN-USB firmware (and working STM32 clones) always
             * send a REC_TS + REC_ERROR pair on bus-on.  Without
             * this, the Windows PEAK driver silently discards all
             * subsequent data frames. */
            if (tud_ready())
            {
                uint8_t sb[PCAN_USB_EP_SIZE];
                uint64_t us = time_us_64();
                uint16_t ts = (uint16_t)((us * PCAN_TS_US_TO_TICK_NUM) /
                                         PCAN_TS_US_TO_TICK_DEN);
                pcan_encode_bus_active_msg(sb, ts);
                pcan_usb_send_rx_msg(sb, PCAN_USB_EP_SIZE);
            }
        }
        s_was_bus_on = bus_on_now;

        /* Forward CAN RX frames when USB is ready */
        if (tud_ready())
        {
            can_bridge_poll_rx();
        }

        vTaskDelay(pdMS_TO_TICKS(1));

        /* Feed watchdog -- if we ever hang, the device auto-reboots */
        watchdog_update();
    }
}

/* -------------------------------------------------------------------------- */
/*  Heartbeat LED task (breathing / slow blink)                                */
/* -------------------------------------------------------------------------- */
static void heartbeat_task(void *param)
{
    (void)param;

    gpio_init(PIN_HEARTBEAT);
    gpio_set_dir(PIN_HEARTBEAT, GPIO_OUT);

    bool led = false;
    for (;;)
    {
        led = !led;
        gpio_put(PIN_HEARTBEAT, led);

        /* Slow blink: 500ms on, 500ms off = normal operation
         * The blink rate visually distinguishes app mode from bootloader. */
        vTaskDelay(pdMS_TO_TICKS(500));
    }
}

/* -------------------------------------------------------------------------- */
/*  FreeRTOS hook implementations                                              */
/* -------------------------------------------------------------------------- */
void vAssertCalled(const char *file, int line)
{
    (void)file;
    (void)line;
    taskDISABLE_INTERRUPTS();
    for (;;)
    {
        tight_loop_contents();
    }
}

void vApplicationStackOverflowHook(TaskHandle_t xTask, char *pcTaskName)
{
    (void)xTask;
    (void)pcTaskName;
    watchdog_reboot(0, 0, 100);
    for (;;)
    {
        tight_loop_contents();
    }
}

void vApplicationMallocFailedHook(void)
{
    watchdog_reboot(0, 0, 100);
    for (;;)
    {
        tight_loop_contents();
    }
}

/* -------------------------------------------------------------------------- */
/*  main                                                                       */
/* -------------------------------------------------------------------------- */
int main(void)
{
    /* Step 1: Check bootloader trigger (does not return if triggered) */
    bootloader_check();

    /* Step 2: Normal application startup */
    set_sys_clock_khz(150000, true);

    /* Step 3: Create tasks */
    xTaskCreate(usb_device_task, "usb", 2048, NULL, USB_TASK_PRIORITY, NULL);
    xTaskCreate(heartbeat_task, "hb", 256, NULL, HEARTBEAT_TASK_PRIORITY, NULL);
    can_bridge_create_tasks();

    /* Step 4: Start scheduler (does not return) */
    vTaskStartScheduler();

    for (;;)
    {
        tight_loop_contents();
    }
    return 0;
}

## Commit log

2026-02-18 first release
    [BladeCore-M54C.kicad_pcb, BladeCore-M54C.kicad_sch, Block Diagram.kicad_sch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]
2026-02-18 add production files
    [BOM-BladeCore-M54C.csv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]
2026-02-18 update component list
    [BladeCore-M54C.kicad_pcb, microcontroller_peripherals.kicad_sch]
2026-03-19 Update M54C
    [BOM-BladeCore-M54C.csv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]
2026-03-19 Update pdf schematic
2026-03-19 Finalize design
    [BOM-BladeCore-M54C.csv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]
2026-03-19 add simple software
    [BladeCore-M54C.kicad_pcb, microcontroller.kicad_sch]
2026-03-21 add eval board
    [BOM-BladeCore-M54C.csv, BOM-M54-DevBoard_1.0.0.csv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]
2026-03-21 export gerbers
    [BOM-BladeCore-M54C.csv, BOM-M54-DevBoard_1.0.0.csv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]
2026-03-23 Generate pdf
    [Bladecore-M54C.kicad_sch, M54-DevBoard_1.0.0.kicad_pcb, M54-DevBoard_1.0.0.kicad_sch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]
2026-04-07 fix hardware bugs, add software example
    [Bladecore-M54C.kicad_sch, M54-DevBoard_1.0.0.kicad_pcb]
2026-04-08 scope measurements
    [Bladecore-M54C.kicad_sch, Output_interfaces.kicad_sch, USB_and_Power.kicad_sch]
2026-04-10 correct devboard findings
    [BOM-M54-DevBoard_1.0.0.csv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]
2026-05-31 update documentation
    [BOM-BladeCore-M54C.csv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]
2026-09-20 update generator
    [BladeCore-M54C.kicad_pcb, microcontroller_peripherals.kicad_sch]
